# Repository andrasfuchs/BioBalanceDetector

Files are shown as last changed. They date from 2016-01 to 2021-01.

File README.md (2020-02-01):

<p align="center">
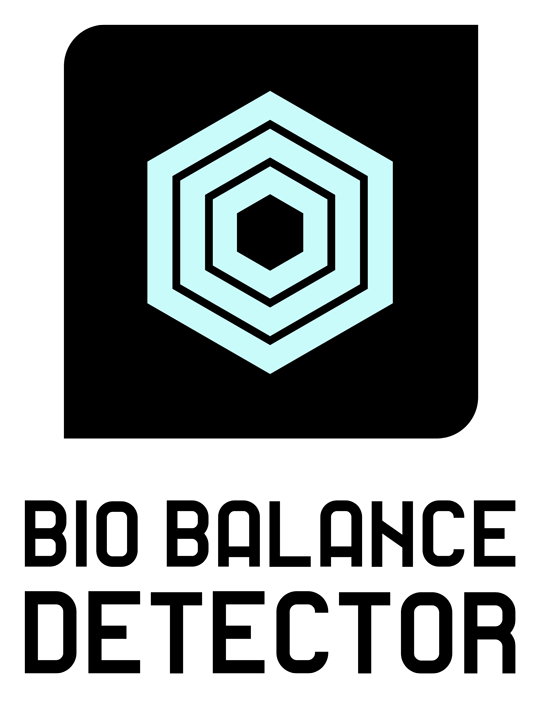
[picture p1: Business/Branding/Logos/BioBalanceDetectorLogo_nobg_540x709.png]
  
</p>

Technically speaking Bio Balance Detector is a software and hardware combination (a data acquisition system - DAS) to detect, measure, display and analyze the electromagnetic energy field around living beings and indicate any potential health imbalance.  
  
These very weak, but measurable electromagnetic fields are the same what our doctors use while using an EEG (electroencephalogram) and ECG (electrocardiogram) devices. We use the information gathered there mainly to detect if we are sleeping, awake or alert, or if there is any problem with our heart's. My goal is to extend this phenomenon's measurements to our hands, or even our whole body.  
  
Technically I will need to connect an electromagnetic sensor matrix which is connected to a PC where the rendering would take place. It will look similar to a Wacom tablet, just like this:
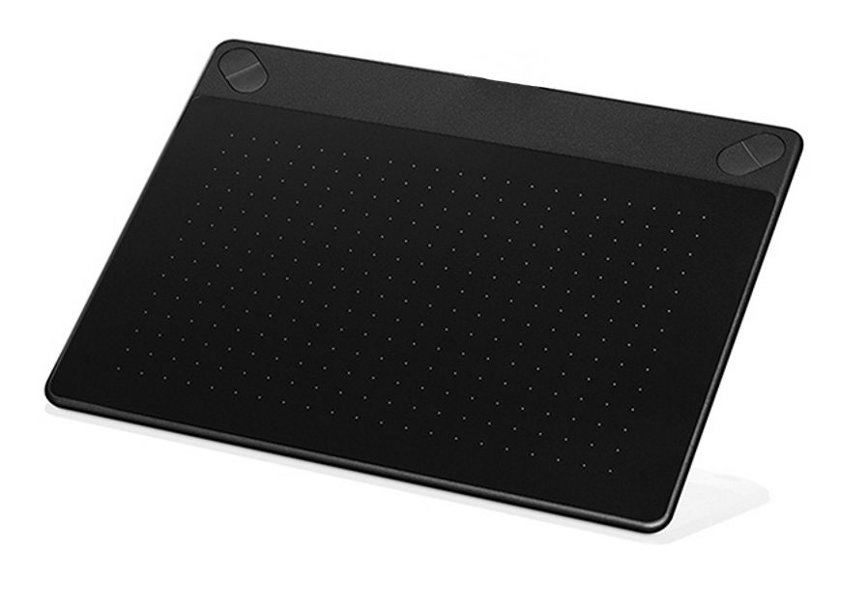
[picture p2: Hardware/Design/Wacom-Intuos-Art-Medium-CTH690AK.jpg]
Wacom Tablet
  
  
Right now, with my [Mercury-16 prototype](https://github.com/andrasfuchs/BioBalanceDetector/wiki/Proto-%235---Mercury-16)  I reached a point where I have a working sensor matrix connected to a microcontroller. Every microcontroller is connected to 8 sensors and 1 emitter. The sensors detect electromagnetic fields, the emitters generate those fields. This part (1 microcontroller, 8 sensors, 1 emitter) is called the cell. These cells are daisy-chained and they all are connected to another microcontroller called the organizer. The cells digitize the analog signals (at 1kHz, 12bit) from the sensors (antennas) and forward them to the organizer. The organizer's job is to format the raw data and send it to the PC trough USB. The PC has a driver which further processes the data, and applies the filters if necessary. There are now WAV file writer, VTS file writer, FFT (Fast Fourier Transformation), averager and offsetter filters available. The driver is capable to work with [SciLab](http://www.scilab.org/) and [ParaView](https://www.paraview.org/), and it also has a very basic console application UI.  
  
You can browse the technical challenges I worked and I am working on on the [implementation wiki page](https://github.com/andrasfuchs/BioBalanceDetector/wiki/Implementation). Future plans include, but not limited to: fractal antenna design, analog low-pass Butterworth filters, Goertzel algorithm implementation on the cells, emitters, USB 3.0, Unity3D GUI and many more.  
  
I realize at this point that I need experienced, passionate people to more forward. I'm currently looking for people with the following expertise, so don't hesitate to contact me:  
* Hardware designer: PCB with [KiCad](https://www.kicad-pcb.org/), antenna and analog low pass filter design  
* Microcontroller firmware programmer: Atmel XMEGA programming with AVR C  
* PC driver developer: .NET, C#, signal processing and WebSockets  
* GUI: Unity3D, C# and WebSockets  
  
If you would like to get know the project more, check out the [wiki page](http://bit.ly/29OBsJ2) or contact me at <andras.fuchs@gmail.com>.

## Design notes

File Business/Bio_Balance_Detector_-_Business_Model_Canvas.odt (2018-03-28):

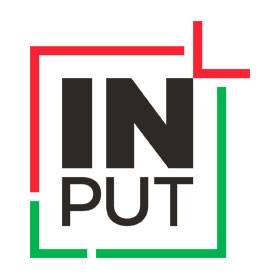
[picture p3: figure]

Business Canvas Model

| 7. Stratégiai partnerek - alkatrész beszállítók - természetgyógyászok - értékesítő ügynökök - szakorvosok | 8. Kulcs-tevékenységek - készülék értékesítése - a diagnózis felállításához szükséges adatok begyűjtése a célszemélytől - elemzés felajánlása szolgáltatásként | 1. Érték ajánlatok - gyors, fájdalommentes, non-invazív, teljes testre vonatkozó elektromágneses diagnosztikai eljárás, amely vizuálisan azonnal értelmezhető adatokat szolgáltat - egészségünkkel kapcsolatos egyensúlyi pontról való elmozdulások megjelenítése | | 4. Fogyasztói kapcsolatok - online - személyes | 2. Fogyasztói csoportok - egészségtudatos személy - természetgyógyász - magánpraxissal rendelkező orvos
| | 6. Erőforrások - hardware tervező - firmware fejlesztő - driver fejlesztő - Unity3D fejlesztő - adatelemző szakember - szkennelő hardware | | | 3. Értékesítési csatornák - online megrendelés - értékesítési ügynök
9. Költség struktúra - prototípus alkatrészek: 1.1 millió Ft - antenna háló tervezése és 3D nyomtatása: 1.5 millió Ft - hardware tervezés: 1.2 millió Ft (240 munkaóra) - software fejlesztés: 4.6 millió Ft (910 munkaóra) - adatok elemzése, diagnosztika: 0.6 millió Ft (120 munkaóra) | | | | 5. Bevételi Források - egyszeri bevétel a készülék eladásából - rendszeres előfizetői díj a folyamatos elemzésért - emelt díjas esetenkénti elemzési díj

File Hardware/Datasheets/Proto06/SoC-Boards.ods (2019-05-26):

 | Raspberry Pi 3 Model B | Raspberry Pi 3 Model B+ | Orange Pi PC Plus | Orange Pi 3 | Orange Pi Win | Pine RockPro64 | Pine Rock64 | Pine H64-B | Odroid C2 | Odroid N2
SoC | Broadcom BCM2837 4 x ARM Cortex-A53 1.2Ghz 64bit ARMv7 Architecture @40nm | Broadcom BCM2837B0 quad-core A53 (ARMv8) 64-bit @ 1.4GHz | Allwinner H3 Quad-core Cortex-A7 H.265/HEVC 4K | Allwinner H6 Quad-core 1.8GHZ 64bit ARM Cortex-A53 | Allwinner A64 quad core ARM Cortex A53 processor @ 1.2 GHz with Mali-400MP2 GPU | Rockchip RK3399 Hexa-Core (dual ARM Cortex A72 and quad ARM Cortex A53) 64-Bit Processor with MALI T-860 Quad-Core GPU | Rockchip RK3328 Quad-Core ARM Cortex A53 64-Bit | Quad-core ARM Cortex-A53 Processor@1488Mhz | Amlogic ARM® Cortex®-A53(ARMv8) 1.5Ghz quad core CPUs
RAM | 1GB 32bit LPDDR2 450MHz | 1GB LPDDR2 SDRAM | 1GB DDR3 (shared with GPU) | 1GB LPDDR3 (shared with GPU) | 1 GB DDR3 | 2/4GB LPDDR4 | 1/2/3GB 1600MHz LPDDR3 | 2/3GB LPDDR3. | 2GB 32bit DDR3 912MHz
HDMI | HDMI 1.4 / RCA / DSI |  |  |  |  |  |  |  | HDMI 2.0 4K / 60Hz
WiFi |  | 2.4GHz and 5GHz 802.11b/g/n/ac Wi-Fi |  | AP6256, IEEE 802.11 a/b/g/n/ac | 802.11 b/g/n | WiFi 802.11 b/g/n (extension) | WiFi 802.11 b/g/n (extension) | WiFi 802.11 b/g/n/ac
LAN | 10/100 Mbit/s | 10/100/1000Mbps (via USB channel) | 10/100Mbps | 10/100/1000Mbps | 10/100/1000Mbps | 10/100/1000Mbps | 10/100/1000Mbps | 10/100/1000Mbps | 10/100/1000Mbps
USB | 2.0 | 2.0 | 2.0 | 3.0 | 2.0 | 3.0 | 3.0 | 3.0 | 2.0
Power |  |  |  |  |  | 12V/3A barrel | 5V/3A coaxial
Linux | Raspbian | Raspbian |  |  |  |  |  | Armbian Debian | Ubuntu 16.04 or Android 6.0
Windows IoT | Yes | No |  |  |  | No | No | No | No
Released | 2016 | 2018 |  | 2019 | 2017
Price (USD) | 35 |  | 24 | 30 |  | 60/80 | 25/35/45 | 36/45 | 46 | 63/79
Problems | -faulty USB driver |  |  | -faulty software |  |  | -no wifi | +RaspPi header

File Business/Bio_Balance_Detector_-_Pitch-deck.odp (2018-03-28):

## Bio Balance Detector

- Fuchs András
  Április, 2018
  Hiventures, Budapest

## Jelenlegi csapat

  <number>
  Fuchs András
  Mérnök Informatikus
  Ötletgazda, hardware tervező, firmware és software fejlesztő
  13 éves .NET/C# szoftverfejlesztői tapasztalat
  5 éves hardware tervezői és Atmel-C firmware fejlesztői tapasztalat

## A kihívás

  <number>
- Egészségügyi diagnosztika ma: későn és kevés
  - A rákok 95%-a megelőzhető lenne, ez évente 9 millió emberélet!
- Drasztikus beavatkozások
  - Megelőzhető, ha időben cselekszünk, életmódváltással, gyógyszerek nélkül
- Félrekezelések
  - Azonnal kimutatható, ha a szervezet rosszabb állapotba kerül
- Kevés lehetőség öndiagnózisra
  - Mit tehet az egészségtudatos ember?
  - Quantified Self

## A megoldás

  <number>
- Testünk lenyomatának feldolgozása
- Intuitív hőtérképszerű megjelenítés
- Szakemberek bevonása akár távolról
- Idővel tipikus problémák felismerése Mesterséges Intelligenciával
- A későbbiekben szabadalmaztatható antenna kialakítása

## Hasonló vállalkozások

  <number>
- Hyperspectral Imaging
  - Űrkutatás
  - Nyersanyag-térképészet
  - Élelmiszer minőség ellenőrzés
- Reptéri ellenőrző kapuk
  - Millimeter-wave test szkenner
- Modern röntgen gépek

## Ügyfelek, értékesítés

  <number>
- Egészségtudatos magánszemélyek
  - Kis méretű készülék
  - Távoli diagnosztizálás szolgáltatás
- Természetgyógyászok
  - Kis méretű készülék
  - Helyi vagy távoli diagnózis
- Magánpraxissal rendelkező szakorvosok
  - Egész testes készülék
  - Helyi diagnózis

## Üzleti modell

  <number>
- Jelenleg
  - Prototípus fejlesztés alatt
- Későbbiekben
  - Termék eladások
  - Kapcsolódó szolgáltatás értékesítés
    - Távoli diagnózis közvetítés
    - AI szoftvercsomag
    - Akkreditált képzések

## Hol járunk most?

  <number>
- Ötödik prototípus működőképes
  - 16 csatorna (pixel)
  - Jelfeldolgozás a PC-n
  - Nagyon egyszerű megjelenítés
  - 2D maratott antennák
- Hatodik tervezési fázisban
  - 256 csatorna (pixel) egy 20x20 cm-es panelon
  - Jelfeldolgozás a mikrokontrolleren
  - Grafikus, valós idejű megjelenítés
  - 3D nyomtatott antennák

## Együttműködésünk

  <number>
- Egyelőre nem történt külső tőke bevonás
- Szakmai mentorokkal való kapcsolatfelvétel
  - Cégalapítás
  - Szabadalom-kezelés
  - Nemzetközi piacra való kijutás
  - Marketing, termékpozicionálás
  - Értékesítés
- Anyagi támogatás
  - 3 szakember foglalkoztatása szabadúszóként (MUC, driver és Unity3D)
  - Anyagköltségek (hardware alkatrészek, NYÁK és antenna gyártás)
  - Működési költség

## Kapcsolat

  <number>
- Kapcsolattartó: Fuchs András
- Email: andras.fuchs@gmail.com
- Telefon: +36 (70) 453-9624
- Weboldal: www.biobalancedetector.com

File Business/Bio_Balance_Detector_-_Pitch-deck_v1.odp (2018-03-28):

## Bio Balance Detector

- Fuchs András
  Április, 2018
  Hiventures, Budapest

## Jelenlegi csapat

  <number>
  Fuchs András
  Mérnök Informatikus
  Ötletgazda, hardware tervező, firmware és software fejlesztő
  13 éves .NET/C# szoftverfejlesztői tapasztalat
  5 éves hardware tervezői és Atmel-C firmware fejlesztői tapasztalat

## A kihívás

  <number>
- Egészségügyi diagnosztika ma: későn és kevés
  - A rákok 95%-a megelőzhető lenne, ez évente 9 millió emberélet!
- Drasztikus beavatkozások
  - Ha időben cselekszünk, életmódváltással, gyógyszerek nélkül
- Félrekezelések
  - Azonnal kimutatható, ha a szervezet rosszabb állapotba kerül
- Kevés lehetőség öndiagnózisra
  - Mit tehet az egészségtudatos ember?
  - Quantified Self: önmegfigyelés, optimalizálás

## A megoldás

  <number>
- Testünk lenyomatának feldolgozása
  - Minden szervünk folyamatosan ad magáról információt
- Intuitív hőtérképszerű megjelenítés
- Szakemberek bevonása akár távolról, otthonról
- Idővel tipikus problémák felismerése Mesterséges Intelligenciával
- A későbbiekben szabadalmaztatható antenna kialakítás

## Versenytársak

  <number>
- Hyperspectral Imaging
  - Űrkutatás
  - Nyersanyag-térképészet
  - Élelmiszer minőség ellenőrzés
- Reptéri ellenőrző kapuk
  - Millimeter-wave test szkenner
- Modern röntgen gépek
  - Káros sugárzással való bombázás
  - CCD érzékelő panel a detektálási oldalon (FPD)

## Ügyfelek, értékesítés

  <number>
- Egészségtudatos magánszemélyek
  - Kis méretű készülék
  - Távoli diagnosztizálás szolgáltatás
- Természetgyógyászok
  - Kis méretű készülék
  - Helyi vagy távoli diagnózis
- Magánpraxissal rendelkező szakorvosok
  - Egész testes készülék
  - Helyi diagnózis

## Üzleti modell

  <number>
- Jelenleg
  - Prototípus fejlesztési stádiumban
- Később
  - Hardware eladások
  - Kapcsolódó szolgáltatás értékesítés
    - távoli diagnózis közvetítés
    - AI szoftvercsomag
    - Akkreditált képzések

## Hol járunk most?

  <number>
- Ötödik prototípus működőképes:
  - 16 csatorna (pixel)
  - Jelfeldolgozás a PC-n
  - Nagyon egyszerű megjelenítés
  - 2D maratott antennák
- Hatodik tervezési fázisban:
  - 256 csatorna (pixel) egy 20x20 cm-eres panelon
  - Jelfeldolgozás a mikrokontrolleren
  - Grafikus, valós idejű megjelenítés
  - 3D nyomtatott antennák

## Zárás

  <number>
- Egyelőre nem történt külső tőke bevonás
- Elsősorban szaktudást, segítségnyújtást szeretnék
  - Cégalapítás, cégirányítás
  - Szabadalom-kezelés
  - Nemzetközi piacra való kijutás
  - Marketing, termékpozicionálás
  - Értékesítés
- Másodlagosan 9 millió forintot a fejlesztésekre
  - 3 szakember foglalkoztatása szabadúszóként (MUC, driver és Unity3D)
  - Anyagköltségek (hardware alkatrészek, NYÁK és antenna gyártás)
  - Minimális működési költség (VPS szerverbérlés, iroda nem szükséges)

## Kapcsolat

  <number>
- Nevem: Fuchs András
- Email: andras.fuchs@gmail.com
- Telefon: +36 (70) 453-9624
- Weboldal: www.biobalancedetector.com

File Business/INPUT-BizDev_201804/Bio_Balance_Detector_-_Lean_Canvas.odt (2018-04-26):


Lean Canvas

| Probléma - a természetgyógyászok elavult készülékekkel tudnak csak pontatlan diagnózist felállítani régi bio-rezonanciás gépekkel KPI: Megkérdezettek, válaszolók, akik rendelkeznek ezzel a problémával és/vagy tisztában vannak, ezzel a szükséglettel | Megoldás - egy olyan készülék és hozzá tartozó szolgáltatás, ami képes a test egészére jellemző és lokális egészséges állapottól való eltéréseket észlelni KPI: Válaszadók, akik kipróbálják az MVP-t, engagement, lemorzsolódás, legtöbbet/legkevesebbet használd feature, emberek akik hajlandóak fizetni | Egyedi értékajánlatok - gyors, fájdalommentes, non-invazív, teljes testre vonatkozó elektromágneses diagnosztikai eljárás, amely vizuálisan azonnal értelmezhető adatokat szolgáltat - egészségünkkel kapcsolatos egyensúlyi pontról való elmozdulások megjelenítése - hozzáférés egy folyamatosan frissülő probléma-felismerő szolgáltatáshoz KPI: Visszajelzések, független értékelések, fogyasztói kommentek, leírások a termékről, felmérések, versenytárs elemzés | | Unfair előny - magas technológiai ismeret szükséges a kifejlesztéshez - szabadalmazható érzékelő egység - jelenleg nincs közvetlen versenytárs KPI: Az egyedi értékajánlat értelmezése a fogyasztók által, patentek, márka érték, belépési korlátok, új belépők száma, a kapcsolatok exkluzivitása | Fogyasztói szegmensek - természetgyógyászok KPI: mennyire könnyű/olcsó potenciális vásárlókat találni
| | Key Metrics | | | Csatornák - online megrendelés - értékesítési ügynök KPI: Leadek, csatornákon elérhető fogyasztók, vírusos koefficiens és ciklus, net promoter score, megnyitási ráta, affiliate marginok, átkattintási ráta, PageRank, üzenetek eléri mérete
Költség struktúra - prototípus alkatrészek: 1.1 millió Ft - antenna háló tervezése és 3D nyomtatása: 1.5 millió Ft - hardware tervezés: 1.2 millió Ft (240 munkaóra) - software fejlesztés: 4.6 millió Ft (910 munkaóra) - adatok elemzése, diagnosztika: 0.6 millió Ft (120 munkaóra) KPI: Fix költségek, egy felhasználó megszerzésének költsége, az n-eik fogyasztó kiszolgálásának költsége, támogatási költség, kulcsszó költség | | | | Bevételi Források - egyszeri bevétel a készülék eladásából - rendszeres előfizetői díj a folyamatos elemzésért - emelt díjas esetenkénti elemzési díj - emelt díjas elemzési díj ritka betegségekre KPI: Lifetime Customer Value, átlagos bevétel felhasználóként, konverziós ráta, kosár méret, átkattintási ráta

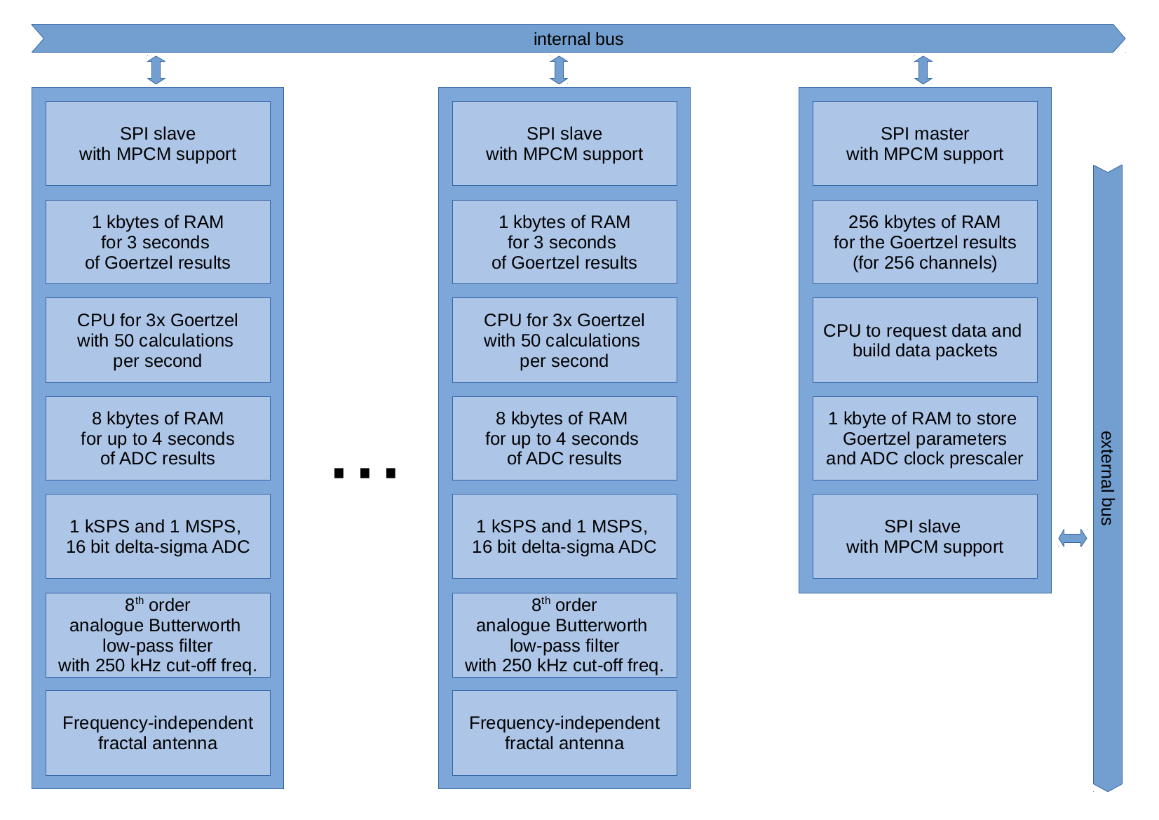
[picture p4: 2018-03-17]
Hardware/Design/BBD-Proto6-Functional_Diagram_v3.png

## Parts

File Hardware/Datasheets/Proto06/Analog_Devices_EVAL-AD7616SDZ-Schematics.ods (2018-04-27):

Bill Of Materials for EVAL-AD7616SDZ Rev-D (20 May-2016 ) (05-039639-01-d-1.xlsx)
Name | Part Description | VALUE | TOLERANCE | PCB Decal | SMD | Layer Name | PART DESC | MFG #1 | PART NUMBER | STOCK CODE
C1 | CAP | DNI | TBA | C0603 | Yes | Top | 0603 Ceramic Capacitor Location - Not Populated | Epcos | TBA | Do Not Insert
C2 | CAP | DNI | TBA | C0603 | Yes | Top | 0603 Ceramic Capacitor Location - Not Populated | Epcos | TBA | Do Not Insert
C3 | CAP | DNI | TBA | C0603 | Yes | Top | 0603 Ceramic Capacitor Location - Not Populated | Epcos | TBA | Do Not Insert
C4 | CAP | DNI | TBA | C0603 | Yes | Top | 0603 Ceramic Capacitor Location - Not Populated | Epcos | TBA | Do Not Insert
C5 | CAP | DNI | TBA | C0603 | Yes | Top | 0603 Ceramic Capacitor Location - Not Populated | Epcos | TBA | Do Not Insert
C6 | CAP | DNI | TBA | C0603 | Yes | Top | 0603 Ceramic Capacitor Location - Not Populated | Epcos | TBA | Do Not Insert
C7 | CAP | DNI | TBA | C0603 | Yes | Top | 0603 Ceramic Capacitor Location - Not Populated | Epcos | TBA | Do Not Insert
C8 | CAP | DNI | TBA | C0603 | Yes | Top | 0603 Ceramic Capacitor Location - Not Populated | Epcos | TBA | Do Not Insert
C9 | CAP | DNI | TBA | C0603 | Yes | Top | 0603 Ceramic Capacitor Location - Not Populated | Epcos | TBA | Do Not Insert
C10 | CAP | DNI | TBA | C0603 | Yes | Top | 0603 Ceramic Capacitor Location - Not Populated | Epcos | TBA | Do Not Insert
C11 | CAP | DNI | TBA | C0603 | Yes | Top | 0603 Ceramic Capacitor Location - Not Populated | Epcos | TBA | Do Not Insert
C12 | CAP | DNI | TBA | C0603 | Yes | Top | 0603 Ceramic Capacitor Location - Not Populated | Epcos | TBA | Do Not Insert
C13 | CAP | DNI | TBA | C0603 | Yes | Top | 0603 Ceramic Capacitor Location - Not Populated | Epcos | TBA | Do Not Insert
C14 | CAP | DNI | TBA | C0603 | Yes | Top | 0603 Ceramic Capacitor Location - Not Populated | Epcos | TBA | Do Not Insert
C15 | CAP | DNI | TBA | C0603 | Yes | Top | 0603 Ceramic Capacitor Location - Not Populated | Epcos | TBA | Do Not Insert
C16 | CAP | DNI | TBA | C0603 | Yes | Top | 0603 Ceramic Capacitor Location - Not Populated | Epcos | TBA | Do Not Insert
C17 | CAP | 0.1uF | ±10% | C0402 | Yes | Bottom | Capacitor ceramic, 16V, X7R, 0402 | Multicomp | MC0402B104K160CT | FEC 1758896
C18 | CAP | 10uF | ±20% | C0603 | Yes | Bottom | 6.3V X5R Ceramic Capacitor | Murata | GRM188R60J106ME47D | FEC 1735528RL
C19 | CAP | 0.1uF | ±10% | C0402 | Yes | Top | Capacitor ceramic, 16V, X7R, 0402 | Multicomp | MC0402B104K160CT | FEC 1758896
C20 | CAP | 10uF | ±20% | C0603 | Yes | Bottom | 6.3V X5R Ceramic Capacitor | Murata | GRM188R60J106ME47D | FEC 1735528RL
C21 | CAP | 0.1uF | ±10% | C0402 | Yes | Top | Capacitor ceramic, 16V, X7R, 0402 | Multicomp | MC0402B104K160CT | FEC 1758896
C22 | CAP | 10uF | ±20% | C0603 | Yes | Bottom | 6.3V X5R Ceramic Capacitor | Murata | GRM188R60J106ME47D | FEC 1735528RL
C23 | CAP | 0.1uF | ±10% | C0402 | Yes | Top | Capacitor ceramic, 16V, X7R, 0402 | Multicomp | MC0402B104K160CT | FEC 1758896
C24 | CAP | 10uF | ±20% | C0603 | Yes | Bottom | 6.3V X5R Ceramic Capacitor | Murata | GRM188R60J106ME47D | FEC 1735528RL
C25 | CAP | 0.1uF | ±10% | C0402 | Yes | Top | Capacitor ceramic, 16V, X7R, 0402 | Multicomp | MC0402B104K160CT | FEC 1758896
C26 | CAP | 10uF | ±20% | C0603 | Yes | Bottom | 6.3V X5R Ceramic Capacitor | Murata | GRM188R60J106ME47D | FEC 1735528RL
C27 | CAP | 0.1uF | ±10% | C0402 | Yes | Top | Capacitor ceramic, 16V, X7R, 0402 | Multicomp | MC0402B104K160CT | FEC 1758896
C28 | CAP | 10uF | ±10% | C0805 | Yes | Bottom | 10V X5R Ceramic Capacitor | Phycomp | 2222 2401 3676 | FEC 9402136
C29 | CAP | 0.1uF | ±10% | C0805 | Yes | Top | 50V X7R Ceramic Capacitor 0805 | Multicomp | MCU0805R104KCT | FEC 9406387
C30 | CAP | 10uF | ±20% | C0603 | Yes | Bottom | 6.3V X5R Ceramic Capacitor | Murata | GRM188R60J106ME47D | FEC 1735528RL
C31 | CAP | 0.1uF | ±10% | C0402 | Yes | Top | Capacitor ceramic, 16V, X7R, 0402 | Multicomp | MC0402B104K160CT | FEC 1758896
C32 | CAP | 10uF | ±20% | C0603 | Yes | Bottom | 6.3V X5R Ceramic Capacitor | Murata | GRM188R60J106ME47D | FEC 1735528RL
C33 | CAP | 0.1uF | ±10% | C0402 | Yes | Top | Capacitor ceramic, 16V, X7R, 0402 | Multicomp | MC0402B104K160CT | FEC 1758896
C34 | CAP | 10uF | ±20% | C0603 | Yes | Top | 6.3V X5R Ceramic Capacitor | Murata | GRM188R60J106ME47D | FEC 1735528RL
C35 | CAP | 0.1uF | ±10% | C0402 | Yes | Top | Capacitor ceramic, 16V, X7R, 0402 | Multicomp | MC0402B104K160CT | FEC 1758896
C36 | CAP | 1uF | ±10% | C0805 | Yes | Top | 10V X7R Ceramic Capacitor | Phycomp | CC0805KKX7R6BB105 | FEC 3352067
C43 | CAP | 2.2uF | ±10% | C0603 | Yes | Top | CAP, MLCC, X5R, 2.2UF, 10V, 0603 | MultiComp | MC0603X225K100CT | FEC 232-0817
C44 | CAP | DNI | n/a | C0402 | Yes | Top | Ceramic Capacitor, not inserted, 0402 | n/a | n/a | Do Not Insert
C45 | CAP | 2.2uF | ±10% | C0603 | Yes | Top | CAP, MLCC, X5R, 2.2UF, 10V, 0603 | MultiComp | MC0603X225K100CT | FEC 232-0817
C46 | CAP | 10uF | ±20% | C0603 | Yes | Top | 6.3V X5R Ceramic Capacitor | Murata | GRM188R60J106ME47D | FEC 1735528RL
C47 | CAP | 2.2uF | ±10% | C0603 | Yes | Top | CAP, MLCC, X5R, 2.2UF, 10V, 0603 | MultiComp | MC0603X225K100CT | FEC 232-0817
C48 | CAP | DNI | n/a | C0402 | Yes | Top | Ceramic Capacitor, not inserted, 0402 | n/a | n/a | Do Not Insert
C49 | CAP | 2.2uF | ±10% | C0603 | Yes | Top | CAP, MLCC, X5R, 2.2UF, 10V, 0603 | MultiComp | MC0603X225K100CT | FEC 232-0817
C50 | CAP | 10uF | ±20% | C0603 | Yes | Top | 6.3V X5R Ceramic Capacitor | Murata | GRM188R60J106ME47D | FEC 1735528RL
C51 | CAP | 1uF | ±10% | C0402 | Yes | Top | CAPACITOR, 0603, 1UF, 16V | Multicomp | MC0603B105K160CT | FEC 2320814
C52 | CAP | 1uF | ±10% | C0402 | Yes | Top | CAPACITOR, 0603, 1UF, 16V | Multicomp | MC0603B105K160CT | FEC 2320814
C54 | CAP | 0.1uF | ±10% | C0402 | Yes | Top | Capacitor ceramic, 16V, X7R, 0402 | Multicomp | MC0402B104K160CT | FEC 1758896
FID1 | FIDUCIAL-ECO |  |  | FIDUCIAL | Yes | Top
FID2 | FIDUCIAL-ECO |  |  | FIDUCIAL | Yes | Top
FID3 | FIDUCIAL-ECO |  |  | FIDUCIAL | Yes | Top
GND | TESTPOINT |  |  | TESTPOINT | No | Top | Black Testpoint | Vero | 20-2137 | FEC 8731128
GND1 | TESTPOINT |  |  | TESTPOINT | No | Top | Black Testpoint | Vero | 20-2137 | FEC 8731128
GND2 | TESTPOINT |  |  | TESTPOINT | No | Top | Black Testpoint | Vero | 20-2137 | FEC 8731128
GND3 | TESTPOINT |  |  | TESTPOINT | No | Top | Black Testpoint | Vero | 20-2137 | FEC 8731128
J1 | POWER_SKT_3.81MM_8WAY |  |  | POWER_SKT_3.81MM_8WAY | No | Top | 8-Pin Terminal header, pitch 3.81mm, vertical | Phoenix Contact | MC 1,5/ 8-G-3,81 | FEC 3704774
J1A | SREWTERM-8_RA | DNI |  | CON\POWER8(3_81PITCH) | No | Top | 8-Pin Screw Terminal, pitch 3.81mm, vertical | Phoenix Contact | 1727078 | Do Not Insert. Keep clear of solder.
J2 | POWER_SKT_3.81MM_8WAY |  |  | POWER_SKT_3.81MM_8WAY | No | Top | 8-Pin Terminal header, pitch 3.81mm, vertical | Phoenix Contact | MC 1,5/ 8-G-3,81 | FEC 3704774
J2A | SREWTERM-8_RA | DNI |  | CON\POWER8(3_81PITCH) | No | Top | 8-Pin Screw Terminal, pitch 3.81mm, vertical | Phoenix Contact | 1727078 | Do Not Insert. Keep clear of solder.
J3 | POWER_SKT_3.81MM_8WAY |  |  | POWER_SKT_3.81MM_8WAY | No | Top | 8-Pin Terminal header, pitch 3.81mm, vertical | Phoenix Contact | MC 1,5/ 8-G-3,81 | FEC 3704774
J3A | SREWTERM-8_RA | DNI |  | CON\POWER8(3_81PITCH) | No | Top | 8-Pin Screw Terminal, pitch 3.81mm, vertical | Phoenix Contact | 1727078 | Do Not Insert. Keep clear of solder.
J4 | POWER_SKT_3.81MM_8WAY |  |  | POWER_SKT_3.81MM_8WAY | No | Top | 8-Pin Terminal header, pitch 3.81mm, vertical | Phoenix Contact | MC 1,5/ 8-G-3,81 | FEC 3704774
J4A | SREWTERM-8_RA | DNI |  | CON\POWER8(3_81PITCH) | No | Top | 8-Pin Screw Terminal, pitch 3.81mm, vertical | Phoenix Contact | 1727078 | Do Not Insert. Keep clear of solder.
J5 | HEADER26 |  |  | HEADER26 | No | Top | 26-Pin (2 x 13) 0.1" Pitch Straight Header | Harwin | M20-9983646 | FEC 1022244 (36 Pin Strip, Cut to Length)
J6 | SMA |  |  | SMA | No | Top | 50r SMA Jack Vertical | TE Connectivity | 5-1814832-1 | FEC 1248990
J7 | CON\BARREL_SMD_2MM_KLDX-SMT2-0202-A |  |  | CON\BARREL_SMD_2MM_KLDX-SMT2-0202-A | No | Top | DC Power Connectors 2mm SMT POWER JACK | KYCON | KLDX-SMT2-0202-A | MOUSER 806-KLDX-SMT20202A
J8 | CON\POWER |  |  | CON\POWER | No | Top | 2 Pin Terminal Block (5mm Pitch) | Camden | CTB5000/2 | FEC 151785
J9 | CON\POWER |  |  | CON\POWER | No | Top | 2 Pin Terminal Block (5mm Pitch) | Camden | CTB5000/2 | FEC 151785
J10 | SDP-STANDARD-CONN |  |  | CON-120/FX8-120S-SV_W/S | No | Top | 120-way connector, 0.6mm pitch | Hirose | FX8-120S-SV(21) | FEC 1324660
LED1 | LED-0603-GREEN | GREEN |  | LED-0603 | Yes | Top | LED, SMD Green | OSRAM | LGQ971 | Digikey 475-1409-1-ND
LK1 | JUMPER |  |  | SIP-2P | No | Top | 2 Pin (0.1" Pitch) Header & Shorting Shunt | Harwin | M20-9990246 | FEC 1022247 & 150-411
LK2 | JUMPER |  |  | SIP-2P | No | Top | 2 Pin (0.1" Pitch) Header & Shorting Shunt | Harwin | M20-9990246 | FEC 1022247 & 150-411
LK3 | JUMPER |  |  | SIP-2P | No | Top | 2 Pin (0.1" Pitch) Header & Shorting Shunt | Harwin | M20-9990246 | FEC 1022247 & 150-411
LK4 | JUMPER |  |  | SIP-2P | No | Top | 2 Pin (0.1" Pitch) Header & Shorting Shunt | Harwin | M20-9990246 | FEC 1022247 & 150-411
LK5 | JUMPER |  |  | SIP-2P | No | Top | 2 Pin (0.1" Pitch) Header & Shorting Shunt | Harwin | M20-9990246 | FEC 1022247 & 150-411
LK6 | JUMPER |  |  | SIP-2P | No | Top | 2 Pin (0.1" Pitch) Header & Shorting Shunt | Harwin | M20-9990246 | FEC 1022247 & 150-411
LK7 | JUMPER |  |  | SIP-2P | No | Top | 2 Pin (0.1" Pitch) Header & Shorting Shunt | Harwin | M20-9990246 | FEC 1022247 & 150-411
LK8 | JUMPER |  |  | SIP-2P | No | Top | 2 Pin (0.1" Pitch) Header & Shorting Shunt | Harwin | M20-9990246 | FEC 1022247 & 150-411
LK9 | JUMPER |  |  | SIP-2P | No | Top | 2 Pin (0.1" Pitch) Header & Shorting Shunt | Harwin | M20-9990246 | FEC 1022247 & 150-411
LK10 | JUMPER |  |  | SIP-2P | No | Top | 2 Pin (0.1" Pitch) Header & Shorting Shunt | Harwin | M20-9990246 | FEC 1022247 & 150-411
LK11 | JUMPER |  |  | SIP-2P | No | Top | 2 Pin (0.1" Pitch) Header & Shorting Shunt | Harwin | M20-9990246 | FEC 1022247 & 150-411
LK12 | JUMPER |  |  | SIP-2P | No | Top | 2 Pin (0.1" Pitch) Header & Shorting Shunt | Harwin | M20-9990246 | FEC 1022247 & 150-411
LK13 | JUMPER |  |  | SIP-2P | No | Top | 2 Pin (0.1" Pitch) Header & Shorting Shunt | Harwin | M20-9990246 | FEC 1022247 & 150-411
LK14 | JUMPER |  |  | SIP-2P | No | Top | 2 Pin (0.1" Pitch) Header & Shorting Shunt | Harwin | M20-9990246 | FEC 1022247 & 150-411
LK15 | JUMPER |  |  | SIP-2P | No | Top | 2 Pin (0.1" Pitch) Header & Shorting Shunt | Harwin | M20-9990246 | FEC 1022247 & 150-411
LK16 | JUMPER |  |  | SIP-2P | No | Top | 2 Pin (0.1" Pitch) Header & Shorting Shunt | Harwin | M20-9990246 | FEC 1022247 & 150-411
LK17 | JUMPER |  |  | SIP-2P | No | Top | 2 Pin (0.1" Pitch) Header & Shorting Shunt | Harwin | M20-9990246 | FEC 1022247 & 150-411
LK18 | JUMPER |  |  | SIP-2P | No | Top | 2 Pin (0.1" Pitch) Header & Shorting Shunt | Harwin | M20-9990246 | FEC 1022247 & 150-411
LK19 | JUMPER |  |  | SIP-2P | No | Top | 2 Pin (0.1" Pitch) Header & Shorting Shunt | Harwin | M20-9990246 | FEC 1022247 & 150-411
LK20 | JUMPER |  |  | SIP-2P | No | Top | 2 Pin (0.1" Pitch) Header & Shorting Shunt | Harwin | M20-9990246 | FEC 1022247 & 150-411
LK21 | JUMPER |  |  | SIP-2P | No | Top | 2 Pin (0.1" Pitch) Header & Shorting Shunt | Harwin | M20-9990246 | FEC 1022247 & 150-411
LK22 | JUMPER |  |  | SIP-2P | No | Top | 2 Pin (0.1" Pitch) Header & Shorting Shunt | Harwin | M20-9990246 | FEC 1022247 & 150-411
LK23 | JUMPER |  |  | SIP-2P | No | Top | 2 Pin (0.1" Pitch) Header & Shorting Shunt | Harwin | M20-9990246 | FEC 1022247 & 150-411
LK24 | JUMPER |  |  | SIP-2P | No | Top | 2 Pin (0.1" Pitch) Header & Shorting Shunt | Harwin | M20-9990246 | FEC 1022247 & 150-411
LK25 | JUMPER |  |  | SIP-2P | No | Top | 2 Pin (0.1" Pitch) Header & Shorting Shunt | Harwin | M20-9990246 | FEC 1022247 & 150-411
LK26 | JUMPER |  |  | SIP-2P | No | Top | 2 Pin (0.1" Pitch) Header & Shorting Shunt | Harwin | M20-9990246 | FEC 1022247 & 150-411
LK27 | JUMPER |  |  | SIP-2P | No | Top | 2 Pin (0.1" Pitch) Header & Shorting Shunt | Harwin | M20-9990246 | FEC 1022247 & 150-411
LK28 | JUMPER |  |  | SIP-2P | No | Top | 2 Pin (0.1" Pitch) Header & Shorting Shunt | Harwin | M20-9990246 | FEC 1022247 & 150-411
LK29 | JUMPER |  |  | SIP-2P | No | Top | 2 Pin (0.1" Pitch) Header & Shorting Shunt | Harwin | M20-9990246 | FEC 1022247 & 150-411
LK30 | JUMPER |  |  | SIP-2P | No | Top | 2 Pin (0.1" Pitch) Header & Shorting Shunt | Harwin | M20-9990246 | FEC 1022247 & 150-411
LK31 | JUMPER |  |  | SIP-2P | No | Top | 2 Pin (0.1" Pitch) Header & Shorting Shunt | Harwin | M20-9990246 | FEC 1022247 & 150-411
LK32 | JUMPER |  |  | SIP-2P | No | Top | 2 Pin (0.1" Pitch) Header & Shorting Shunt | Harwin | M20-9990246 | FEC 1022247 & 150-411
LK33 | JUMPER-3 |  |  | JUMPER_3 | No | Top | 6 Pin (3x2) 0.1" Header & Shorting Block - Insert Shorting Block in Position-B | M20-9983646 | M20-9983646 | FEC 1022244 & 150-411 (36 Pin Strip, Cut to Lenght)
LK34 | JUMPER-3 |  |  | JUMPER_3 | No | Top | 6 Pin (3x2) 0.1" Header & Shorting Block - Insert Shorting Block in Position-B | M20-9983646 | M20-9983646 | FEC 1022244 & 150-411 (36 Pin Strip, Cut to Lenght)
LK35 | JUMPER-3 |  |  | JUMPER_3 | No | Top | 6 Pin (3x2) 0.1" Header & Shorting Block - Insert Shorting Block in Position-B | M20-9983646 | M20-9983646 | FEC 1022244 & 150-411 (36 Pin Strip, Cut to Lenght)
LK36 | JUMPER-3 |  |  | JUMPER_3 | No | Top | 6 Pin (3x2) 0.1" Header & Shorting Block - Insert Shorting Block in Position-B | M20-9983646 | M20-9983646 | FEC 1022244 & 150-411 (36 Pin Strip, Cut to Lenght)
LK37 | JUMPER-3 |  |  | JUMPER_3 | No | Top | 6 Pin (3x2) 0.1" Header & Shorting Block - Insert Shorting Block in Position-B | M20-9983646 | M20-9983646 | FEC 1022244 & 150-411 (36 Pin Strip, Cut to Lenght)
LK38 | JUMPER2\SIP3 |  |  | LINK-3P | No | Top | 3 Pin SIL Header & Shorting Link - Insert Shorting Block in Position-A | Harwin | M20-9990345 & M7567-05 | FEC 1022248 & 150410
LK39 | JUMPER |  |  | SIP-2P | No | Top | 2 Pin (0.1" Pitch) Header & Shorting Shunt | Harwin | M20-9990246 | FEC 1022247 & 150-411
LK40 | JUMPER2\SIP3 |  |  | LINK-3P | No | Top | 3 Pin SIL Header & Shorting Link - Insert Shorting Block in Position-A | Harwin | M20-9990345 & M7567-05 | FEC 1022248 & 150410
LK41 | JUMPER2\SIP3 |  |  | LINK-3P | No | Top | 3 Pin SIL Header & Shorting Link - Insert Shorting Block in Position-A | Harwin | M20-9990345 & M7567-05 | FEC 1022248 & 150410
Q2 | 2N7002 |  |  | SOT23 | Yes | Top | MOSFET N Transistor | STMICROELECTRONICS | 2N7002 | FEC 9512608
R1 | RES | 0r | ±1% | R0603 | Yes | Top | SMD Resistor | Multicomp | MC 0.063W 0603 0r | FEC 933-1662
R2 | RES | 0r | ±1% | R0603 | Yes | Top | SMD Resistor | Multicomp | MC 0.063W 0603 0r | FEC 933-1662
R3 | RES | 270r | 0,05 | R0603 | Yes | Top | SMD Resistor | Multicomp | MC 0.063W 0603 5% 270R | FEC 9331964
R4 | RES | 0r | ±1% | R0603 | Yes | Top | SMD Resistor | Multicomp | MC 0.063W 0603 0r | FEC 933-1662
R5 | RES | 0r | ±1% | R0603 | Yes | Top | SMD Resistor | Multicomp | MC 0.063W 0603 0r | FEC 933-1662
R6 | RES | 270r | 0,05 | R0603 | Yes | Top | SMD Resistor | Multicomp | MC 0.063W 0603 5% 270R | FEC 9331964
R7 | RES | 0r | ±1% | R0603 | Yes | Top | SMD Resistor | Multicomp | MC 0.063W 0603 0r | FEC 933-1662
R8 | RES | 0r | ±1% | R0603 | Yes | Top | SMD Resistor | Multicomp | MC 0.063W 0603 0r | FEC 933-1662
R9 | RES | 270r | 0,05 | R0603 | Yes | Top | SMD Resistor | Multicomp | MC 0.063W 0603 5% 270R | FEC 9331964
R10 | RES | 0r | ±1% | R0603 | Yes | Top | SMD Resistor | Multicomp | MC 0.063W 0603 0r | FEC 933-1662
R11 | RES | 0r | ±1% | R0603 | Yes | Top | SMD Resistor | Multicomp | MC 0.063W 0603 0r | FEC 933-1662
R12 | RES | 270r | 0,05 | R0603 | Yes | Top | SMD Resistor | Multicomp | MC 0.063W 0603 5% 270R | FEC 9331964
R13 | RES | 0r | ±1% | R0603 | Yes | Top | SMD Resistor | Multicomp | MC 0.063W 0603 0r | FEC 933-1662
R14 | RES | 0r | ±1% | R0603 | Yes | Top | SMD Resistor | MULTICOMP | MC 0.063W 0603 0r | FEC 933-1662
R15 | RES | 270r | 0,05 | R0603 | Yes | Top | SMD Resistor | Multicomp | MC 0.063W 0603 5% 270R | FEC 9331964
R16 | RES | 0r | ±1% | R0603 | Yes | Top | SMD Resistor | MULTICOMP | MC 0.063W 0603 0r | FEC 933-1662
R17 | RES | 0r | ±1% | R0603 | Yes | Top | SMD Resistor | Multicomp | MC 0.063W 0603 0r | FEC 933-1662
R18 | RES | 270r | 0,05 | R0603 | Yes | Top | SMD Resistor | Multicomp | MC 0.063W 0603 5% 270R | FEC 9331964
R19 | RES | 0R | ±1% | R0603 | Yes | Top | SMD Resistor | Multicomp | MC 0.063W 0603 0r | FEC 933-1662
R20 | RES | 0R | ±1% | R0603 | Yes | Top | SMD Resistor | Multicomp | MC 0.063W 0603 0r | FEC 933-1662
R21 | RES | 270r | 0,05 | R0603 | Yes | Top | SMD Resistor | Multicomp | MC 0.063W 0603 5% 270R | FEC 9331964
R22 | RES | 0R | ±1% | R0603 | Yes | Top | SMD Resistor | Multicomp | MC 0.063W 0603 0r | FEC 933-1662
R23 | RES | 0r | ±1% | R0603 | Yes | Top | SMD Resistor | MULTICOMP | MC 0.063W 0603 0r | FEC 933-1662
R24 | RES | 270r | 0,05 | R0603 | Yes | Top | SMD Resistor | Multicomp | MC 0.063W 0603 5% 270R | FEC 9331964
R25 | RES | 0r | ±1% | R0603 | Yes | Top | SMD Resistor | MULTICOMP | MC 0.063W 0603 0r | FEC 933-1662
R26 | RES | 0r | ±1% | R0603 | Yes | Top | SMD Resistor | Multicomp | MC 0.063W 0603 0r | FEC 933-1662
R27 | RES | 270r | 0,05 | R0603 | Yes | Top | SMD Resistor | Multicomp | MC 0.063W 0603 5% 270R | FEC 9331964
R28 | RES | 0r | ±1% | R0603 | Yes | Top | SMD Resistor | Multicomp | MC 0.063W 0603 0r | FEC 933-1662
R29 | RES | 0r | ±1% | R0603 | Yes | Top | SMD Resistor | Multicomp | MC 0.063W 0603 0r | FEC 933-1662
R30 | RES | 270r | 0,05 | R0603 | Yes | Top | SMD Resistor | Multicomp | MC 0.063W 0603 5% 270R | FEC 9331964
R31 | RES | 0r | ±1% | R0603 | Yes | Top | SMD Resistor | Multicomp | MC 0.063W 0603 0r | FEC 933-1662
R32 | RES | 0r | ±1% | R0603 | Yes | Top | SMD Resistor | Multicomp | MC 0.063W 0603 0r | FEC 933-1662
R33 | RES | 270r | 0,05 | R0603 | Yes | Top | SMD Resistor | Multicomp | MC 0.063W 0603 5% 270R | FEC 9331964
R34 | RES | 0r | ±1% | R0603 | Yes | Top | SMD Resistor | Multicomp | MC 0.063W 0603 0r | FEC 933-1662
R35 | RES | 0R | ±1% | R0603 | Yes | Top | SMD Resistor | Multicomp | MC 0.063W 0603 0r | FEC 933-1662
R36 | RES | 270r | 0,05 | R0603 | Yes | Top | SMD Resistor | Multicomp | MC 0.063W 0603 5% 270R | FEC 9331964
R37 | RES | 0R | ±1% | R0603 | Yes | Top | SMD Resistor | Multicomp | MC 0.063W 0603 0r | FEC 933-1662
R38 | RES | 0R | ±1% | R0603 | Yes | Top | SMD Resistor | Multicomp | MC 0.063W 0603 0r | FEC 933-1662
R39 | RES | 270r | 0,05 | R0603 | Yes | Top | SMD Resistor | Multicomp | MC 0.063W 0603 5% 270R | FEC 9331964
R40 | RES | 0R | ±1% | R0603 | Yes | Top | SMD Resistor | Multicomp | MC 0.063W 0603 0r | FEC 933-1662
R41 | RES | 0r | ±1% | R0603 | Yes | Top | SMD Resistor | Multicomp | MC 0.063W 0603 0r | FEC 933-1662
R42 | RES | 270r | 0,05 | R0603 | Yes | Top | SMD Resistor | Multicomp | MC 0.063W 0603 5% 270R | FEC 9331964
R43 | RES | 0r | ±1% | R0603 | Yes | Top | SMD Resistor | Multicomp | MC 0.063W 0603 0r | FEC 933-1662
R44 | RES | 0r | ±1% | R0603 | Yes | Top | SMD Resistor | Multicomp | MC 0.063W 0603 0r | FEC 933-1662
R45 | RES | 270r | 0,05 | R0603 | Yes | Top | SMD Resistor | Multicomp | MC 0.063W 0603 5% 270R | FEC 9331964
R46 | RES | 0r | ±1% | R0603 | Yes | Top | SMD Resistor | Multicomp | MC 0.063W 0603 0r | FEC 933-1662
R47 | RES | 0r | ±1% | R0603 | Yes | Top | SMD Resistor | Multicomp | MC 0.063W 0603 0r | FEC 933-1662
R48 | RES | 270r | 0,05 | R0603 | Yes | Top | SMD Resistor | Multicomp | MC 0.063W 0603 5% 270R | FEC 9331964
R49 | 100K_0402_1%_0.063W | 100k | ±1% | R0402 | Yes | Bottom | RESISTOR, 100K, 0.063W, 1%, 0402 | MULTICOMP | MC00625W04021100K | FEC 1358096
R50 | 100K_0402_1%_0.063W | 100k | ±1% | R0402 | Yes | Bottom | RESISTOR, 100K, 0.063W, 1%, 0402 | MULTICOMP | MC00625W04021100K | FEC 1358096
R51 | 100K_0402_1%_0.063W | 100k | ±1% | R0402 | Yes | Bottom | RESISTOR, 100K, 0.063W, 1%, 0402 | MULTICOMP | MC00625W04021100K | FEC 1358096
R52 | 100K_0402_1%_0.063W | 100k | ±1% | R0402 | Yes | Bottom | RESISTOR, 100K, 0.063W, 1%, 0402 | MULTICOMP | MC00625W04021100K | FEC 1358096
R53 | 100K_0402_1%_0.063W | 100k | ±1% | R0402 | Yes | Bottom | RESISTOR, 100K, 0.063W, 1%, 0402 | MULTICOMP | MC00625W04021100K | FEC 1358096
R54 | 100K_0402_1%_0.063W | 100k | ±1% | R0402 | Yes | Bottom | RESISTOR, 100K, 0.063W, 1%, 0402 | MULTICOMP | MC00625W04021100K | FEC 1358096
R55 | 100K_0402_1%_0.063W | 100k | ±1% | R0402 | Yes | Bottom | RESISTOR, 100K, 0.063W, 1%, 0402 | MULTICOMP | MC00625W04021100K | FEC 1358096
R56 | 100K_0402_1%_0.063W | 100k | ±1% | R0402 | Yes | Bottom | RESISTOR, 100K, 0.063W, 1%, 0402 | MULTICOMP | MC00625W04021100K | FEC 1358096
R57 | 100K_0402_1%_0.063W | 100k | ±1% | R0402 | Yes | Bottom | RESISTOR, 100K, 0.063W, 1%, 0402 | MULTICOMP | MC00625W04021100K | FEC 1358096
R58 | 100K_0402_1%_0.063W | 100k | ±1% | R0402 | Yes | Bottom | RESISTOR, 100K, 0.063W, 1%, 0402 | MULTICOMP | MC00625W04021100K | FEC 1358096
R59 | 100K_0402_1%_0.063W | 100k | ±1% | R0402 | Yes | Bottom | RESISTOR, 100K, 0.063W, 1%, 0402 | MULTICOMP | MC00625W04021100K | FEC 1358096
R60 | 100K_0402_1%_0.063W | 100k | ±1% | R0402 | Yes | Bottom | RESISTOR, 100K, 0.063W, 1%, 0402 | MULTICOMP | MC00625W04021100K | FEC 1358096
R61 | 100K_0402_1%_0.063W | 100k | ±1% | R0402 | Yes | Bottom | RESISTOR, 100K, 0.063W, 1%, 0402 | MULTICOMP | MC00625W04021100K | FEC 1358096
R62 | 100K_0402_1%_0.063W | 100k | ±1% | R0402 | Yes | Bottom | RESISTOR, 100K, 0.063W, 1%, 0402 | MULTICOMP | MC00625W04021100K | FEC 1358096
R63 | 100K_0402_1%_0.063W | 100k | ±1% | R0402 | Yes | Bottom | RESISTOR, 100K, 0.063W, 1%, 0402 | MULTICOMP | MC00625W04021100K | FEC 1358096
R64 | 10K_0402_1%_0.063W | 10k | ±1% | R0402 | Yes | Top | RESISTOR, 10K, 0.063W, 1%, 0402 | Multicomp | MC00625W0402110K | FEC 1358069
R65 | 10K_0402_1%_0.063W | 10k | ±1% | R0402 | Yes | Bottom | RESISTOR, 10K, 0.063W, 1%, 0402 | Multicomp | MC00625W0402110K | FEC 1358069
R66 | 10K_0402_1%_0.063W | 10k | ±1% | R0402 | Yes | Top | RESISTOR, 10K, 0.063W, 1%, 0402 | Multicomp | MC00625W0402110K | FEC 1358069
R67 | 10K_0805_1%_0.1W | 10k | ±1% | R0805 | Yes | Top | RESISTOR, 10K, 0.1W, 1%, 0805 | MULTICOMP | MC01W0805110K | FEC 9332391
R82 | 2K4_0603_1%_0.063W | 2k4 | ±1% | R0603 | Yes | Top | RESISTOR, 2K4, 0.063W, 1%, 0603 | MULTICOMP | MC0063W060312K4 | FEC 9330879
R83 | 0R_0603_1%_0.063W | 0r | ±1% | R0603 | Yes | Top | RESISTOR, 0603 1% 0R | MULTICOMP | MC0063W06030R | FEC 9331662
R84 | 100K_0402_1%_0.063W | 100k | ±1% | R0402 | Yes | Top | RESISTOR, 100K, 0.063W, 1%, 0402 | MULTICOMP | MC00625W04021100K | FEC 1358096
R85 | 10K_0402_1%_0.063W | 10k | ±1% | R0402 | Yes | Bottom | RESISTOR, 10K, 0.063W, 1%, 0402 | Multicomp | MC00625W0402110K | FEC 1358069
R86 | DNP_0402 | DNI | n/a | R0402 | Yes | Bottom | SMD RESISTOR 0402 | n/a | n/a | Do Not Insert
R87 | DNP_0402 | DNI | n/a | R0402 | Yes | Bottom | SMD RESISTOR 0402 | n/a | n/a | Do Not Insert
R88 | DNP_0402 | DNI | n/a | R0402 | Yes | Bottom | SMD RESISTOR 0402 | n/a | n/a | Do Not Insert
R89 | 0R_0402_1%_0.063W | 0r | ±1% | R0402 | Yes | Bottom | RESISTOR, 0402 1% 0R | Multicomp | MC00625W040210R | FEC 1357983
R90 | 0R_0402_1%_0.063W | 0r | ±1% | R0402 | Yes | Bottom | RESISTOR, 0402 1% 0R | Multicomp | MC00625W040210R | FEC 1357983
R91 | 0R_0402_1%_0.063W | 0r | ±1% | R0402 | Yes | Top | RESISTOR, 0402 1% 0R | Multicomp | MC00625W040210R | FEC 1357983
R92 | DNP_0402 | DNI | n/a | R0402 | Yes | Top | SMD RESISTOR 0402 | n/a | n/a | Do Not Insert
R93 | DNP_0402 | DNI | n/a | R0402 | Yes | Top | SMD RESISTOR 0402 | n/a | n/a | Do Not Insert
R94 | DNP_0402 | DNI | n/a | R0402 | Yes | Top | SMD RESISTOR 0402 | n/a | n/a | Do Not Insert
R95 | DNP_0402 | DNI | n/a | R0402 | Yes | Top | SMD RESISTOR 0402 | n/a | n/a | Do Not Insert
R96 | DNP_0402 | DNI | n/a | R0402 | Yes | Top | SMD RESISTOR 0402 | n/a | n/a | Do Not Insert
R97 | DNP_0402 | DNI | n/a | R0402 | Yes | Top | SMD RESISTOR 0402 | n/a | n/a | Do Not Insert
R98 | DNP_0402 | DNI | n/a | R0402 | Yes | Top | SMD RESISTOR 0402 | n/a | n/a | Do Not Insert
R99 | 0R_0402_1%_0.063W | 0r | ±1% | R0402 | Yes | Top | RESISTOR, 0402 1% 0R | Multicomp | MC00625W040210R | FEC 1357983
R100 | 0R_0402_1%_0.063W | 0r | ±1% | R0402 | Yes | Top | RESISTOR, 0402 1% 0R | Multicomp | MC00625W040210R | FEC 1357983
R101 | 0R_0402_1%_0.063W | 0r | ±1% | R0402 | Yes | Top | RESISTOR, 0402 1% 0R | Multicomp | MC00625W040210R | FEC 1357983
R102 | 100K_0402_1%_0.063W | 100k | ±1% | R0402 | Yes | Top | RESISTOR, 100K, 0.063W, 1%, 0402 | MULTICOMP | MC00625W04021100K | FEC 1358096
R103 | DNP_0402 | DNI | n/a | R0402 | Yes | Top | SMD RESISTOR 0402 | n/a | n/a | Do Not Insert
R104 | 100K_0402_1%_0.063W | 100k | ±1% | R0402 | Yes | Top | RESISTOR, 100K, 0.063W, 1%, 0402 | MULTICOMP | MC00625W04021100K | FEC 1358096
REGA | TESTPOINT |  |  | TESTPOINT | No | Top | Black Testpoint | Vero | 20-2137 | FEC 8731128
REGD | TESTPOINT |  |  | TESTPOINT | No | Top | Black Testpoint | Vero | 20-2137 | FEC 8731128
RESET | SW-PUSH-SMD |  |  | SW_PB_SMD_6MM | Yes | Top | SMD Push Button Switch (sealed 6mm x 6mm) | Omron | B3S-1000 | FEC 177-807
SL1 | SOLDER_PADS_0402 | DNI |  | 402 | Yes | Bottom | On-board Solder Shorting Link | n/a | n/a | Do Not Insert
SL2 | SOLDER_PADS_0402 | DNI |  | 402 | Yes | Bottom | On-board Solder Shorting Link | n/a | n/a | Do Not Insert
SL3 | SOLDER_PADS_0402 | DNI |  | 402 | Yes | Bottom | On-board Solder Shorting Link | n/a | n/a | Do Not Insert
SL4 | SOLDER_PADS_0402 | DNI |  | 402 | Yes | Bottom | On-board Solder Shorting Link | n/a | n/a | Do Not Insert
SL5 | SOLDER_PADS_0402 | DNI |  | 402 | Yes | Top | On-board Solder Shorting Link | n/a | n/a | Do Not Insert
SL6 | SOLDER_PADS_0402 | DNI |  | 402 | Yes | Bottom | On-board Solder Shorting Link | n/a | n/a | Do Not Insert
SL7 | SOLDER_PADS_0402 | DNI |  | 402 | Yes | Bottom | On-board Solder Shorting Link | n/a | n/a | Do Not Insert
SL8 | SOLDER_PADS_0402 | DNI |  | 402 | Yes | Bottom | On-board Solder Shorting Link | n/a | n/a | Do Not Insert
U1 | AD7616 |  |  | LQFP80-65MM-PITCH | Yes | Top | 16-Chan Dual Sim-Sar | Analog Devices | AD7616BSTZ | AD7616BSTZ
U2 | ADR421 |  |  | SO8NB | Yes | Top | 2.5V Reference | Analog Devices | ADR421ARZ | ADR421ARZ
U3 | ADP7104ARDZ-5.0 |  |  | SO8NB_RD8-2 | Yes | Top | Linear Regulator 5V, 20V, 500mA, Ultralow Noise, CMOS | Analog Devices | ADP7104ARDZ-5.0 | ADP7104ARDZ-5.0
U4 | ADP7118ARDZ-3.3 |  |  | SO8NB_RD-8-1 | Yes | Top | Linear Regulator 3.3V, Ultralow Noise, CMOS | Analog Devices | ADP7118ARDZ-3.3 | ADP7118ARDZ-3.3-R7
U5 | ADP7118ARDZ-5.0 |  |  | SO8NB_RD-8-1 | Yes | Top | Linear Regulator 5.0V, Ultralow Noise, CMOS | Analog Devices | ADP7118ARDZ-5.0 | ADP7118ARDZ-5.0-R7
U7 | 24LC32A-I/MS |  |  | MSO8 | Yes | Top | 32K I2C Serial EEPROM, MSOP8 | Microchip | 24LC32A-I/MS | FEC 1331330
V0A | SMA |  |  | SMA | No | Top | 50r SMA Jack Vertical | TE Connectivity | 5-1814832-1 | FEC 1248990
V0B | SMA |  |  | SMA | No | Top | 50r SMA Jack Vertical | TE Connectivity | 5-1814832-1 | FEC 1248990
V1A | SMA |  |  | SMA | No | Top | 50r SMA Jack Vertical | TE Connectivity | 5-1814832-1 | FEC 1248990
V1B | SMA |  |  | SMA | No | Top | 50r SMA Jack Vertical | TE Connectivity | 5-1814832-1 | FEC 1248990
V2A | SMA |  |  | SMA | No | Top | 50r SMA Jack Vertical | TE Connectivity | 5-1814832-1 | FEC 1248990
V2B | SMA |  |  | SMA | No | Top | 50r SMA Jack Vertical | TE Connectivity | 5-1814832-1 | FEC 1248990
V3A | SMA |  |  | SMA | No | Top | 50r SMA Jack Vertical | TE Connectivity | 5-1814832-1 | FEC 1248990
V3B | SMA |  |  | SMA | No | Top | 50r SMA Jack Vertical | TE Connectivity | 5-1814832-1 | FEC 1248990
V4A | SMA |  |  | SMA | No | Top | DNI | TE Connectivity | DNI | Do Not Insert
V4B | SMA |  |  | SMA | No | Top | DNI | TE Connectivity | DNI | Do Not Insert
V5A | SMA |  |  | SMA | No | Top | DNI | TE Connectivity | DNI | Do Not Insert
V5B | SMA |  |  | SMA | No | Top | DNI | TE Connectivity | DNI | Do Not Insert
V6A | SMA |  |  | SMA | No | Top | DNI | TE Connectivity | DNI | Do Not Insert
V6B | SMA |  |  | SMA | No | Top | DNI | TE Connectivity | DNI | Do Not Insert
V7A | SMA |  |  | SMA | No | Top | DNI | TE Connectivity | DNI | Do Not Insert
V7B | SMA |  |  | SMA | No | Top | DNI | TE Connectivity | DNI | Do Not Insert
VDD | TESTPOINT |  |  | TESTPOINT | No | Top | Black Testpoint | Vero | 20-2137 | FEC 8731128
VDRIVE | TESTPOINT |  |  | TESTPOINT | No | Top | Black Testpoint | Vero | 20-2137 | FEC 8731128
X1 | CLAMP-14MM |  |  | CLAMP-14MM | No | Top | 14mm QFP Clamp | IM Tech |  | Do Not Insert
Screw1 |  |  |  |  |  |  | SCREW, CHEESE, NYLON, M3X10, PK100 | Allthread | 119030010 | FEC 7070597
Screw2 |  |  |  |  |  |  | SCREW, CHEESE, NYLON, M3X10, PK100 | Allthread | 119030010 | FEC 7070597
Nut1 |  |  |  |  |  |  | NUT/WASHER, NYLON, M3, PK100 | Duratool | 1140030 | FEC 7061857
Nut2 |  |  |  |  |  |  | NUT/WASHER, NYLON, M3, PK100 | Duratool | 1140030 | FEC 7061857
 | Distributor Web Sites |  |  |  |  | Parts Not Inserted
 | FEC | www.farnell.com |  |  |  | ADI Supplied Parts
 | Digikey | www.digikey.com |  |  |  | Bare Board |  | EVAL-AD7616SDZ Rev-D (08-039639-D)
 | Analog Devices | www.analog.com |  |  |  | 4 x Stick on feet |  | Do Not Cover Mounting holes with feet, height must be greater than maximum component height on bottom side.
 | Mouser | www.mouser.com |  |  |  | 4 x Pluggable Terminal Blocks (for J1, J2, J3 & J4) |  | Phoenix Contact | 1803633 | FEC 3704956
 |  | www.stontronics.co.uk |  |  |  | Packing Material |  | Bubble Wrap
 |  |  |  |  |  | Board to be placed in suitable sized Anti-static bag
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

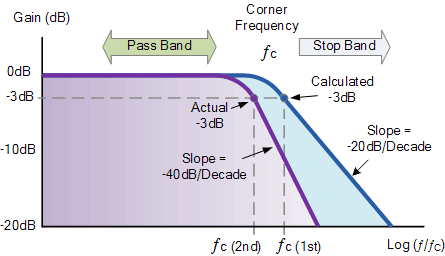
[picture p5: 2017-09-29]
Photos/Common/FrequencyResponseOfA2stOrderLowPassFilter.gif

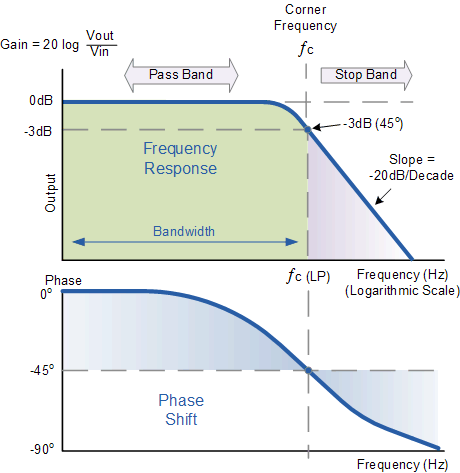
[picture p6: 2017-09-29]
Photos/Common/FrequencyResponseOfA1stOrderLowPassFilter.gif

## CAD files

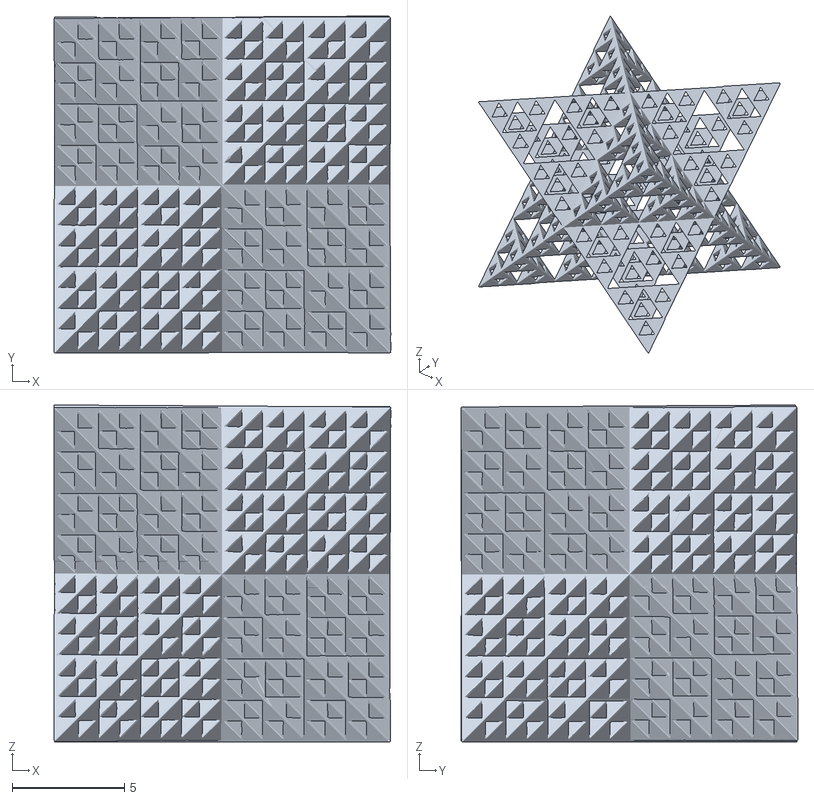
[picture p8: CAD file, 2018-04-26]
Hardware/Design/Antenna/merkaba_(level 3).stl
15.0 x 15.0 x 15.0

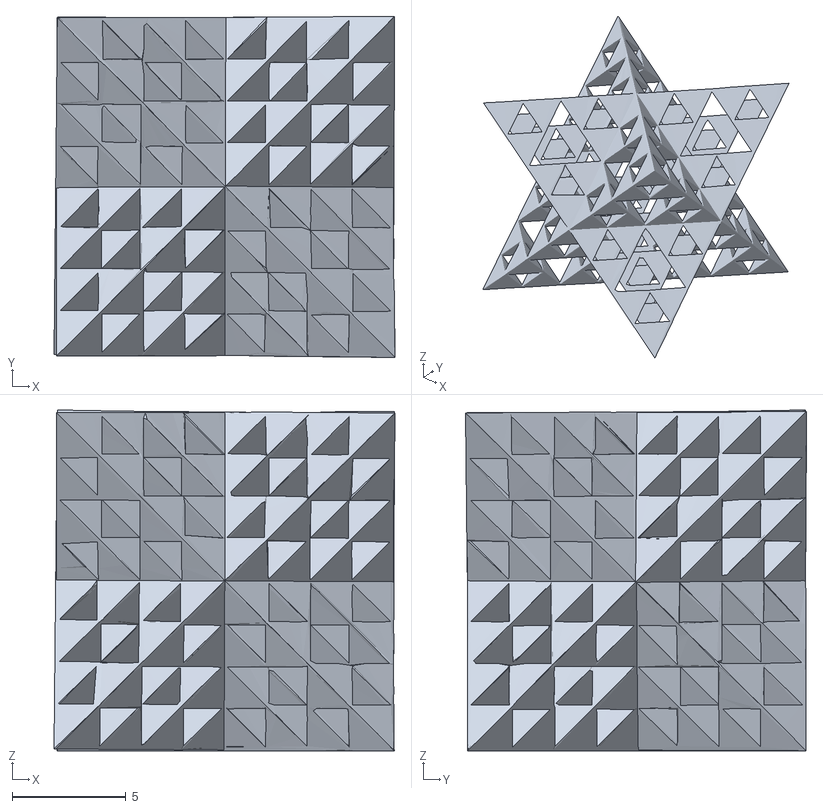
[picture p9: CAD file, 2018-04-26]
Hardware/Design/Antenna/merkaba_(level 2).stl
15.0 x 15.0 x 15.0

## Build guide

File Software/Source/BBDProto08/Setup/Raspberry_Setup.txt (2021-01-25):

# https://darryldias.me/2021/install-and-setup-net-5-on-raspberry-pi/

wget https://download.visualstudio.microsoft.com/download/pr/567a64a8-810b-4c3f-85e3-bc9f9e06311b/02664afe4f3992a4d558ed066d906745/dotnet-sdk-5.0.101-linux-arm.tar.gz
wget https://download.visualstudio.microsoft.com/download/pr/11977d43-d937-4fdb-a1fb-a20d56f1877d/73aa09b745586ac657110fd8b11c0275/aspnetcore-runtime-5.0.1-linux-arm.tar.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

mkdir ~/.dotnet

tar -xvf dotnet-sdk-5.0.101-linux-arm.tar.gz -C ~/.dotnet
tar -xvf aspnetcore-runtime-5.0.1-linux-arm.tar.gz -C ~/.dotnet

nano ~/.bashrc

export DOTNET_ROOT=$HOME/.dotnet 
export PATH=$PATH:$HOME/.dotnet

dotnet --version

# https://docs.microsoft.com/en-us/dotnet/core/install/linux-debian

x, Clone the repo on the Raspberry
cd ~/Work/BioBalanceDetector
git clone https://github.com/andrasfuchs/BioBalanceDetector.git

x, Update the repo on the Raspberry
cd ~/Work/BioBalanceDetector
git pull

x, Build the .NET source code on the Raspberry
cd ~/Work/BioBalanceDetector/Software/Source/BBDProto08/BBD.SleepLogger
dotnet build

x, Publish the .NET app on the Raspberry
cd ~/Work/BioBalanceDetector/Software/Source/BBDProto08/BBD.SleepLogger
dotnet publish --configuration release --runtime linux-arm --self-contained true --output ~/Work/BBD.SleepLogger

x, Run the .NET app on the Raspberry
cd ~/Work/BBD.SleepLogger
./BBD.SleepLogger

x, Configure the .NET 5 app to run as background services
sudo apt-get install supervisor

sudo nano /etc/supervisor/supervisord.conf
# change chmod=0700 to chmod=0766 @ line 5

sudo nano /etc/supervisor/conf.d/bbd.conf

[group:bbd]
programs=SleepLogger

[program:SleepLogger]
directory=/home/pi/Work/BBD.SleepLogger
command=/home/pi/Work/BBD.SleepLogger/BBD.SleepLogger
autostart=true
autorestart=true
stderr_logfile=/var/log/BBD.SleepLogger.err.log
stdout_logfile=/var/log/BBD.SleepLogger.out.log
user=pi
environment=HOME="/home/pi",USER="pi"
stopsignal=INT
stopasgroup=false

sudo service supervisor restart

supervisorctl status all
supervisorctl stop bbd:
supervisorctl start bbd:

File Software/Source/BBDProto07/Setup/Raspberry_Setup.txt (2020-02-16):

1, Format SD card with SD Card Formatter [https://www.sdcard.org/downloads/formatter_4/eula_windows/SDCardFormatterv5_WinEN.zip]

2, Extract NOOBS to the SD card [https://www.raspberrypi.org/downloads/noobs/]

3, Install Raspbian full

4, Set fixed IP to 192.168.1.35 (wired) and 192.168.1.36 (wireless)

5, Enable VNC, I2C and SPI interfaces

6, Install updates

7, Set timezone and WiFi country

8, Use VNC Viewer to connect [https://www.realvnc.com/download/file/viewer.files/VNC-Viewer-6.19.107-Windows.exe]

8, Setup SAMBA share [https://www.raspberrypi.org/magpi/samba-file-server/]

9, Install .NET Core SDK ARM32 [https://dotnet.microsoft.com/download/dotnet-core/current]
	Copy dotnet-sdk-3.1.101-linux-arm.tar.gz to Pi
	mkdir -p $HOME/dotnet && tar zxf dotnet-sdk-3.1.101-linux-arm.tar.gz -C $HOME/dotnet
	
	# add these two lines to ~/.bashrc
	export DOTNET_ROOT=$HOME/dotnet
	export PATH=$PATH:$HOME/dotnet
	
10, Install VSDbg [https://github.com/OmniSharp/omnisharp-vscode/wiki/Remote-Debugging-On-Linux-Arm]
	curl -sSL https://aka.ms/getvsdbgsh | bash /dev/stdin -r linux-arm -v latest -l ~/vsdbg
	
11, Switch to the Windows 10 machine	
	
12, Download WinSCP client and its .NET assembly / COM library [https://winscp.net/eng/downloads.php]
	
13, Start a new .NET Core 3.1 project in Visual Studio 2019

14, Install Pi packages:
		Install-Package Unosquare.Raspberry.IO
		Install-Package Unosquare.WiringPi
		Install-Package Unosquare.RaspberryIO.Peripherals
		
15, Build the project

16, Create a DeployToPi.ps1 script in the project folder [https://medium.com/@lewwybogus/debugging-your-net-core-3-app-on-your-raspberry-pi-with-visual-studio-2019-9662348e79d9]

17, Put this .ps1 file into the root of the new project, and extract the WinSCP .NET assembly (WinSCPnet.dll) into that folder too

18, Open PowerShell with administrator privileges, run "Set-ExecutionPolicy RemoteSigned", and run ".\DeployToPi.ps1" 

19, Press Ctrl + Alt + P in Visual Studio, and attach to SSH/192.168.1.36/

20, Next time press Shift + Alt + P to reattach the debugger to the same process

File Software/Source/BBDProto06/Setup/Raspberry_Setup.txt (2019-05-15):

1, Format SD card with SD Card Formatter [https://www.sdcard.org/downloads/formatter_4/eula_windows/SDCardFormatterv5_WinEN.zip]

2, Extract NOOBS to the SD card [https://www.raspberrypi.org/downloads/noobs/]

3, Install Raspbian full

4, Set fixed IP to 192.168.1.35 (wired) and 192.168.1.36 (wireless)

5, Enable VNC, I2C and SPI interfaces

6, Install updates

7, Set timezone and WiFi country

8, Use VNC Viewer to connect [https://www.realvnc.com/download/file/viewer.files/VNC-Viewer-6.19.107-Windows.exe]

8, Setup SAMBA share [https://www.raspberrypi.org/magpi/samba-file-server/]

9, Install .NET Core SDK ARM32 [https://dotnet.microsoft.com/download/dotnet-core/2.2]
	Copy dotnet-sdk-2.2.105-linux-arm.tar.gz to Pi
	mkdir -p $HOME/dotnet && tar zxf dotnet-sdk-2.2.105-linux-arm.tar.gz -C $HOME/dotnet
	
	# add these two lines to ~/.bashrc
	export DOTNET_ROOT=$HOME/dotnet
	export PATH=$PATH:$HOME/dotnet
	
10, Install VSDbg [https://github.com/OmniSharp/omnisharp-vscode/wiki/Remote-Debugging-On-Linux-Arm]
	curl -sSL https://aka.ms/getvsdbgsh | bash /dev/stdin -r linux-arm -v latest -l ~/vsdbg

11, Create a Raspberry Pi 3 app from template 
	dotnet new -i "RaspberryPi.Template::*"
	dotnet new coreiot -n MyNewIoTProject

12, Preprare project
	Add win10-arm;linux-arm as RuntimeIdentifiers
	Install Pi packages:
		Install-Package Unosquare.Raspberry.IO
		Install-Package Unosquare.WiringPi
		Install-Package Unosquare.RaspberryIO.Peripherals

13, Create a publish profile to publish to a local folder (debug,self-contained,netcoreapp2.2,linux-arm) 

14, Set up WinSCP's Commands/Keep Remote Directory up to Date function on that folder

15, Run the app on the Pi

16, Attach debugger to the process on Pi using SSH
	DEV: Visual Studio > Debug > Attach to process > SSH > Pi

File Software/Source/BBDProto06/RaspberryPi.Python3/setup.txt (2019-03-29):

@Pi> sudo pip3 install rpi_ws281x adafruit-circuitpython-neopixel

@PC> WinSCP > Commands > Keep remote folder up to date (Ctrl+U)

@PC> Visual Studio > open rpi_neopixel_simpletest.py

@PC> PuTTY > sudo python3 ~/Documents/Work/rpi_neopixel_simpletest.py

# https://learn.adafruit.com/neopixels-on-raspberry-pi/raspberry-pi-wiring
# sudo pip3 install rpi_ws281x adafruit-circuitpython-neopixel
# rpi_neopixel_simpletest.py

# https://learn.adafruit.com/mlx90393-wide-range-3-axis-magnetometer/circuitpython
# sudo pip3 install adafruit-circuitpython-mlx90393
# sudo python3 ~/Documents/Work/adafruit_mlx90393_simpletest.py

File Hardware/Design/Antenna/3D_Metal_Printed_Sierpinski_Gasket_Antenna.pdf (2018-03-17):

________________________________________________________________________________________
Department of Engineering Technology, Waterford Institute of Technology, Waterford, Ireland e-mail: 20061369@mail.wit.ie, poleary@wit.ie
SEAM Research Centre, Waterford Institute of Technology, Waterford, Ireland
e-mail: rraghavendra@mail.wit.ie

# 3D Metal Printed Sierpinski Gasket Antenna

### Deepak Shamvedi¹

### , Oliver J. McCarthy¹,2, Eoghan O’Donoghue¹,2, Paul O’Leary¹

,

### Ramesh Raghavendra¹,2

Abstract In this research, the design, simulation, and fabrication of the first ever 3D metal printed Sierpinski gasket antenna, with multiple resonance characteristics is reported. The antenna is fabricated from Titanium alloy Ti-6Al-4V, using the Direct Metal Laser Sintering (DMLS) technique. Mechanical considerations like Rumsey’s principle and the support structures required for overhanging 3D printed structures have also been studied in detail and discussed. The validity of the DMLS technique for manufacturing a complex shaped (fractal) antenna is assessed, by comparing CST (Computer Simulation Technology) simulation results with the measured data.

### 1 INTRODUCTION

Additive Manufacturing (AM) or 3D printing technology allows 3D parts to be fabricated directly from Computer Aided Design (CAD) data, sliced into stacks or in a layer-by-layer fashion, without the need to plan the transformation from 2D into 3D. Complex parts, which were extremely difficult or in some cases impossible to be manufactured at all using conventional tooling methods, can now be built with a short lead time, with good reliability and the high level of precision [1]. In a very short span of time, AM has found its application in almost all leading engineering areas, such as aerospace, automotive, medical fields, consumer products and military. Recent research in 3D printing has also focused on RF/Microwave components [2]-[4]. These 3D
components | can | be | fabricated | using
Stereolithography, where the physical structure is fabricated using non-conducting thermoplastics, such as Acrylonitrile Butadiene Styrene (ABS), and then usually metallized or painted in order to make the printed electromagnetic component functional. Uniform coating or selective coating, adds an extra processing step over the polymer printed component, and also has to be done very precisely, in order to achieve acceptable electromagnetic performance from the component.
This research presents the first 3D metal printed Sierpinski gasket antenna for wireless applications using DMLS technology. In earlier published research, DMLS has already been used to manufacture a waveguide fed antenna array, while EBM has been used to manufacture a 3D printed metallic horn antenna [3] [4]. Both the DMLS and EBM antennae have been produced as early demonstrations of the power of AM for microwave components, using metallic materials. In this research, the selection of the Sierpinski gasket antenna is done as another early example of

3D printing, where the geometry is more complex. The aim of this research is to push the limits of 3D metal printing in the field of complex antenna manufacturing. However, 3D metal printing imposes some unexpected restrictions on antenna design, which will be outlined later in section 4.

### 2 SIERPINSKI GASKET ANTENNA

The Sierpinski gasket is named after the Polish mathematician Sierpinski, who described some of the main properties of a fractal shape in 1916 [5]. In this case, the discontinuities (or fractals), increase the perimeter of the material so that the antenna has multiple electrical lengths, which leads to multiband behavior [6]. Historically, this feature has been exploited in 2D antenna designs, but in this research, a 3D extension is presented, so instead of triangles, tetrahedrons are arranged in a self-symmetric fashion.
To the best of the authors’ knowledge, a 3D Sierpinski antenna has only been built twice [7] [8]. Anguera. J, et al in [7], presented a very light-weight, fractal-shaped, Sierpinski-carpet, cylindrical hole, monopole antenna, fabricated with metallized foam,
where | the | antenna | possessed | multiband
characteristics. In [8], the first 3D full-metal version of a Sierpinski gasket antenna was manually fabricated using brass. The antenna possessed multiband characteristics; however, differences between computational and measured results could be easily seen, which might have occurred due to
geometrical | inaccuracies | during | the | manual
fabrication of this complex-shaped antenna. The manual fabrication challenges mean that the differences between the measured and simulation results will increase, if the radiating monopole structure were designed for a higher wavelength.

### 3 ANTENNA FABRICATION

The proposed antenna was fabricated using the DMLS machine EOSINT M280, with the Titanium alloy Ti-6Al-4V as the conducting material. The antenna designed is a 2nd iteration, Sierpinski gasket antenna, with a large side length of 46.7 mm, on a finite rectangular copper ground plane, of area 160 mm x 100 mm, with 1 mm thickness, as shown in Figure 1.

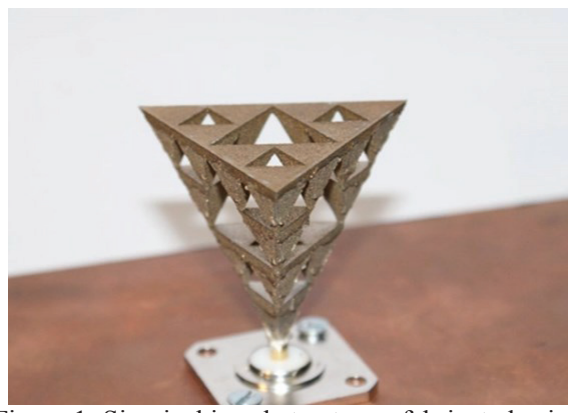
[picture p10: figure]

Figure 1: Sierpinski gasket antenna fabricated using DMLS technology on Ti-6Al-4V

### 4 MECHANICAL CONSIDERATIONS

### 4.1 Support Structures

In the process of 3D printing, where models are built layer-by-layer, each layer is supported by previously printed layers underneath it. In order to print structures with shallow angles (with reference to the horizontal plane building plate) and cantilever sections, extra support structures are needed to ensure the printed objects’ integrity and print quality. An industry rule of thumb with DMLS technology is that support structures are needed, if the structure has an overhanging angle () less than a material-specific value. For example, with the Ti-6Al-4V allow used here, =45º. The overhanging angle varies from material to material, as well as from technique to technique, and also depends on other factors, such as manufacturing layer thickness, the width of the printed line, and the melt temperature, to ensure a high print quality [9]. While the proposed Sierpinski gasket antenna satisfies the condition of the maximum overhanging angle () for the alloy Ti-6Al-4V using DMLS, i.e. =60º, nonetheless a conservative approach was taken and support structures were still added, as shown in Figure 2.

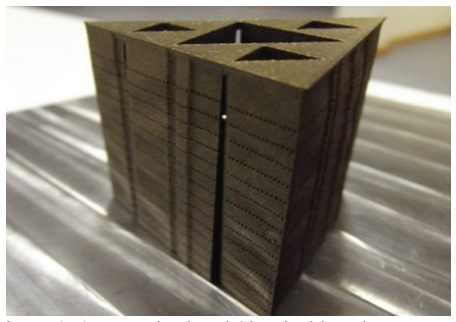
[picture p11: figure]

Figure 2: 3D metal printed Sierpinski gasket antenna with build support structure

The supports appear as individual pillars, constructed as a network of interconnected pieces, deliberately brittle for easy removal from the model.

### 4.2 Build Orientation

The recent research has shown that build orientation plays an important role in influencing the construction time as well as the mechanical properties of the printed structure. In publication [10], the author has mentioned the importance of considering the build orientation of 0º, 45º, and 90º on test samples during the designing process. It was concluded that the mechanical properties such as tensile strength, residual stress, fatigue as well as surface roughness are highly dependent on the orientation of the build.
However, due to the complex geometry of the Sierpinski antenna, it was decided to choose a build orientation of 90º w.r.t the building platform, so that the proposed antenna corresponds to the minimum fatigue and possess maximum tensile strength.

### 4.3 Ring Width

The “ring width” (parameter related to the width of the excitation point) of the Sierpinski gasket antenna is important from the perspective of multiband features. V H Rumsey, in the early sixties, established what is now known as Rumsey’s Principle and is the current notion of broadband antennae. According to Rumsey’s Principle, if the geometry of an antenna is solely the function of an angle, then the antenna parameters will be independent of the frequency [11]. However, in 1999 Hohlfeld and Cohen proposed an extension to Rumsey’s Principle, known as the Hohlfeld-Cohen-Rumsey (HCR) condition, stating that self-symmetry is one of the underlining requirements. For the antenna to be frequency independent, it needs to be symmetric along the origin as well, where the origin is the antenna feeding point [12]. However, as the flare angle in the case of Sierpinski gasket antenna remain fixed at approximately 60º, the HCR condition will not be considered further in this work. But it should also be noted that even the slightest variation caused at the ring width have an impact on antenna’s input impedance.
One more complication related to the ring width is that having an antenna built in an upside-down orientation, a minimum of 1.90 mm of ring width diameter is required to successfully build the antenna. Furthermore, in order to connect the antenna with a feeding circuit, the ring width should be big enough to facilitate soldering, if required. It should also be noted the ring width may be further increased when soldering or conductive epoxy is applied to the feed point.
CST simulations were carried out and are shown in Figure 3. During the simulation, it was observed that even a minor increase in the radius value (r) of ring width causes the wider antenna bandwidth and also lead the antenna resonance frequency dip to shift
towards | the | higher | frequency | bands.

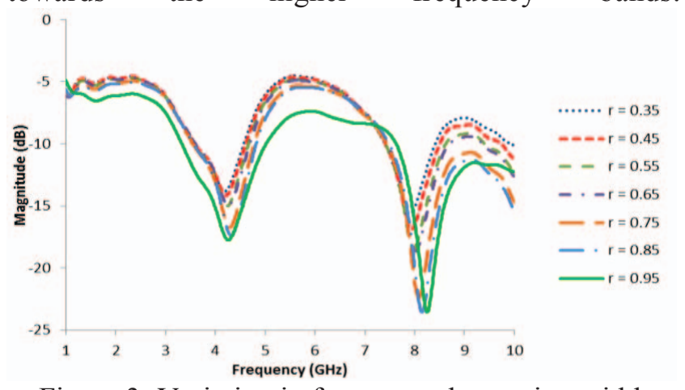
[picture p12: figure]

Figure 3: Variation in frequency due to ring width effect

### 4.4 Feed Point Challenges

After the antenna fabrication, the next task was to connect the antenna circuitry to an N-type connector. One of the major challenges faced, as the antenna was fabricated from Titanium, was to establish an RF antenna connection with a feeding circuitry. The chosen Titanium alloy is very difficult to solder, as the metals oxidize readily as its temperature elevates during soldering, making it extremely difficult to solder an antenna onto a connector. For this reason, the antenna was glued onto the connector with the help of a conductive silver epoxy adhesive having < .001-cm volume resistivity.
As can be seen in Figure 4, a laboratory clamp was employed to mount the antenna onto the feed.

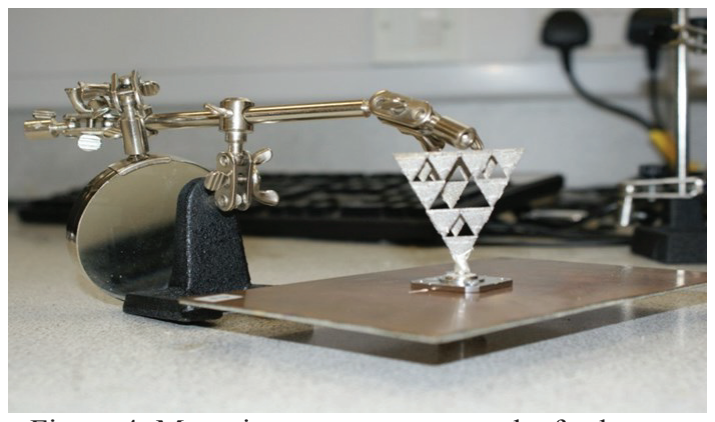
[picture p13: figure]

Figure 4: Mounting an antenna onto the feed setup

It is also noteworthy that a challenge in the gluing process was achieving a consistent, perpendicular orientation was not easy. Mounting an antenna in this way may lead to variation in the input impedance from one mounting to another, and hence, a better set up will be employed in the future. However, this variation should be quite small, as has been shown in publication [13], where the author has performed experiments on the variation of the input impedance due to changes in the tilt angle of a planar monopole antenna.

### 4.5 Equilateral Triangle

A three-dimensional Sierpinski gasket antenna is an arrangement of tetrahedrons in a self-symmetric fashion stacked one upon another, which gives the antenna multiband characteristics. However, in practice, a 3D Sierpinski gasket antenna cannot be realized with infinitely small joints (unlike a 2D realization) to be mechanically rigid, for example in practice, one tetrahedron should overlap the adjacent one. This was confirmed during the physical examination of the antenna, as it was observed that the triangular sides were not perfectly equilateral. This means that the antenna geometry is no longer in the shape of an equilateral triangle, but is now simply an isosceles triangle. However, it does not affect the multiband behavior of the antenna, as the structure is still self-symmetric.

### 5 RESULTS

The above-mentioned antenna was designed, optimized and simulated on CST software. The return loss coefficient (S11) and path loss (S21) of the antenna were measured on a Rhode and Schwarz ZVB 20 Vector Network Analyser (VNA). Figure 5 shows the comparison of measured and simulated reflection characteristics of the 3D metal printed Sierpinski gasket antenna. Both the results are in good agreement with each other.

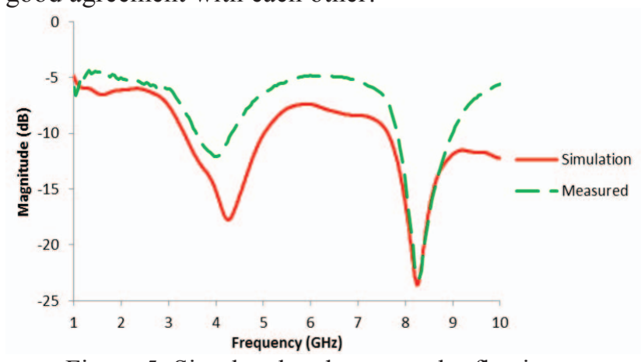
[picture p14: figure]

Figure 5: Simulated and measured reflection coefficient

The antenna resonates at both the fundamental frequencies, of 4.2 GHz and 8.4 GHz, maintaining its multiband feature. The measured and simulated gains at both the corresponding resonant frequencies are shown in Figure 6.

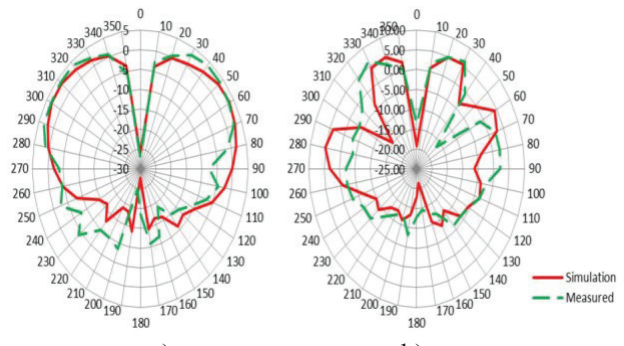
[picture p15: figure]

a) b)

Figure 6: Simulated and measured gain radiation pattern a) 4.2 GHz b) 8.4 GHz

The simulated gain at 4.2 GHz was found to be 5.07 dB compared to the measured gain of 4.07 dB, at 8.4 GHz, the measured gain was found to be 4.45 dB compared to the simulated gain of 6.64 dB. The difference between the measured and the simulation value could be due to the effect of surface roughness, this effect is significant at higher frequencies. However, in this research, no efforts have been made to reduce the surface roughness of the antenna using surface treatment process such as wetblasting or polishing as explained in [14], which could lead to further improvement of results.

### 4 CONCLUSION

From an RF design and realization perspective, 3D printing offers great advantages, as an efficient and easy method for printing complex geometries.
The complex geometry antenna described in this work is a Sierpinski gasket antenna, created using a DMLS 3D metal printer. The design restrictions and challenges are explained in detail in the body of the work. The antenna RF performance was measured and found to be in good agreement with simulation results, in terms of bandwidth and radiation characteristics.

References

[1] F. Niesler and M. Hermatschweiler, "Additive manufacturing of micro-sized parts-trend of
miniaturization | is | driver | for | 3D | laser
lithography," Laser Technik Journal, vol. 11, no. 5, p. 16–18, 2014.
[2] T. Le, B. Song, Q. Liu, R. Bahr, S. Moscato, C.-
P. Wong and M. Tentzeris, "A novel strain sensor based on 3D printing technology and 3D antenna design," in 2015 IEEE 65th Electronic Components and Technology Conference (ECTC), San Diego, CA, 2015.
[3] H. Guan-Long, Z. Shi-Gang, C. Tan-Huat and Y. Tat-Soon, "3-D metal-direct-printed wideband and high-efficiency waveguide-fed antenna array," in International Microwave Symposium, Phoenix, AZ, 2015.
[4] C. Garcia, R. Rumpf, H. Tsang and J. Barton, "Effects of extreme surface roughness on 3D printed horn antenna," IET, vol. 49, no. 12, pp. 734 - 736, 2013.
[5] H.O. Peitgen, H. Jürgens and D. Saupe, Chaos and Fractals: New Frontiers of Science, 2nd ed., New York: Springer-Verlag, 2004.
[6] R. Batra, P. L. Zade and D. Sagne, "Design and implementation of Sierpinski carpet fractal
antenna | for | wireless | communications,"
International Journal of Scientific Research Engineering & Technology (IJSRET), vol. 1, no. 4, pp. 043-047, 2012.
[7] J. Anguera, J. P. Daniel, C. Borja, J. Mumbru, C. Puente, T. Leduc, K. Sayegrih and P. V. Roy, "Metallized foams for antenna design: application to fractal-shaped Sierpinski-carpet monopole," Progress In Electromagnetics Research, vol. 104, pp. 239-251, 2010.
[8] M. Alaydrus, "Analysis of Sierpinski gasket
tetrahedron | antennas," | Journal | of
Telecommunications, vol. 5, no. 2, pp. 6-10, 2010.
[9] J. Kranz, D. Herzog and C. Emmelmann, "Design guidelines for laser additive manufacturing of lightweight structures in TiAl6V4," Journal of Laser Application, vol. 27, no. 1, pp. 1-16, 2015.
[10] W. Vree, "On the influence of build orientation on the mechanical properties of direct metal laser sintered (DMLS) Ti-6Al-4V flexures," 04 April 2016. [Online]
[11] V. Rumsey, Frequency independent antennas, New York and London: Academic Press, 1966.
[12] R. G. Holfield, N. Cohen, "Self-similarity and the geometric requirements for frequency independence in antennae," Fractals - Complex Geometry, Patterns, and Scaling in Nature and Society, vol. 07, no. 1, pp. 79-84, 1999.
[13] Z. N. Chen, "Experiments on input impedance of tilted planar monopole antenna," Microwave and Optical Technology Letter, vol. 26, no. 3, pp. 202-204, 2000.
[14] D. Shamvedi, O. McCarthy, E. O'Donoghue,
P. O’ Leary and R. Raghavendra, “Surface treatment of 3D metal printed microwave components,” 18th Research Colloquium on Radio Science and Communications for a Smarter World, Dublin, March 2017.

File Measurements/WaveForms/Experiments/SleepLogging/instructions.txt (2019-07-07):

Laptop + mobile phone
0, put phone into silent mode
1, start DroidCam on the phone and put the phone on the stand
2, start OBS and load preset (720p stereo, x264, DroidCam video, laptop mic audio ch1, desktop audio ch2)
3, connect headphones
4, load meditation mp3
5, put on conductive glove/sock/electrode
6, start biosignal recording with start_aqusition.bat
7, start recording in OBS
8, play meditation mp3
9, sign and say meditation depth while meditating
10, stop recording

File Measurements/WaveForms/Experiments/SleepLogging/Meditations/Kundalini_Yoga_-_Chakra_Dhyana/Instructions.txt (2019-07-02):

Sit with your eyes closed, spine erect but not rigid.
Rest your hands on your thighs with palms facing up, index fingertips touching the tip of each thumb for the first three chakras, touching the middle joint of each thumb for the fourth & fifth chakras and the base of the thumb for the sixth & seventh chakras.
If you wish you may touch the tip of the tongue to the roof of your mouth. Take several long, slow, easy deep breaths breathing through your nose, until your body becomes calm. Sit during this meditation. Do not lie down. 
As we come to each chakra, focus your attention on the indicated area of your body. With each exhale chant the mantra that is given in a slow, elongated fashion. Begin with the root chakra (Mooladhara) and work upward to the Crown (Sahasrara). At the end always allow the energy to ground, flowing down through your body, and spend a few minutes in meditation or lie on your back in shavasan.
 
1. Begin with the Mooladhara chakra, located at the perineum, midway between your anus and genitals.
Say "Om Mooladhara".
Visualize its red color. Slowly repeat "Lang" (pronounced lung) for a few minutes, then visualize the chakra turning liquid gold as you say "Kundalini, arohanum" several times.
 
2. The Swadhisthana chakra, located in the genital region or at the base of the spine.
Say "Om Swadhisthana".
Visualize its orange color. Say "Vang" (pronounced vung) for a few minutes, then visualize the chakra turning liquid gold as you say "Kundalini, arohanum" several times.
 
3. The Manipura chakra, located at the navel.
Say "Om Sri Mani Padme Hum".
Visualize its yellow color. Say "Rang" (pronounced rung) for a few minutes, then visualize the chakra turning liquid gold as you say "Kundalini, arohanum" several times.
 
4. The Anahata chakra, in the center of your chest, your spiritual heart.
Say "Om Anahata".
Visualize its green color. Say "Yang" (pronounced yung) for a few minutes, then visualize the chakra turning liquid gold as you say "Kundalini, arohanum" several times.
 
5. The Vishuddhi chakra, located in your throat, at the Adam's apple or the epiglottis.
Say "Om Vishuddhi".
Visualize its blue color. Say "Hang" (pronounced hung) for a few minutes, then visualize the chakra turning liquid gold as you say "Kundalini, arohanum" several times.
 
6. The Ajneya chakra, located between our eyebrows.
Say "Om Ajneya".
Visualize its indigo color, the color of the original Levi blue jeans prior to washing them. Say "AUM" in a 3-2-1 ratio. "A-A-A-O-O-M" for a few minutes, then visualize the chakra turning liquid gold as you say "Kundalini, arohanum" several times.
 
7. The Sahasrara chakra, located at the center of the top of your head.
Say "Om Sahasrara".
Visualize its violet color, pastel purple.
Say "Ogum Satyam Om" for a few minutes, then visualize the chakra turning liquid gold as you say "Kundalini, arohanum" several times.
 
Lie Down in Shavasan
 
Lie down with your eyes closed immediately after the meditation, and relax for at least 10 or 20 minutes, or as long as you like. Yoga's Corpse Pose, Shavasan, is good for this (eyes closed, on your back with arms loosely to the sides, palms up, legs slightly apart). Let go. Enjoy. Notice the dynamics of the energy in your body as the kundalini flows.

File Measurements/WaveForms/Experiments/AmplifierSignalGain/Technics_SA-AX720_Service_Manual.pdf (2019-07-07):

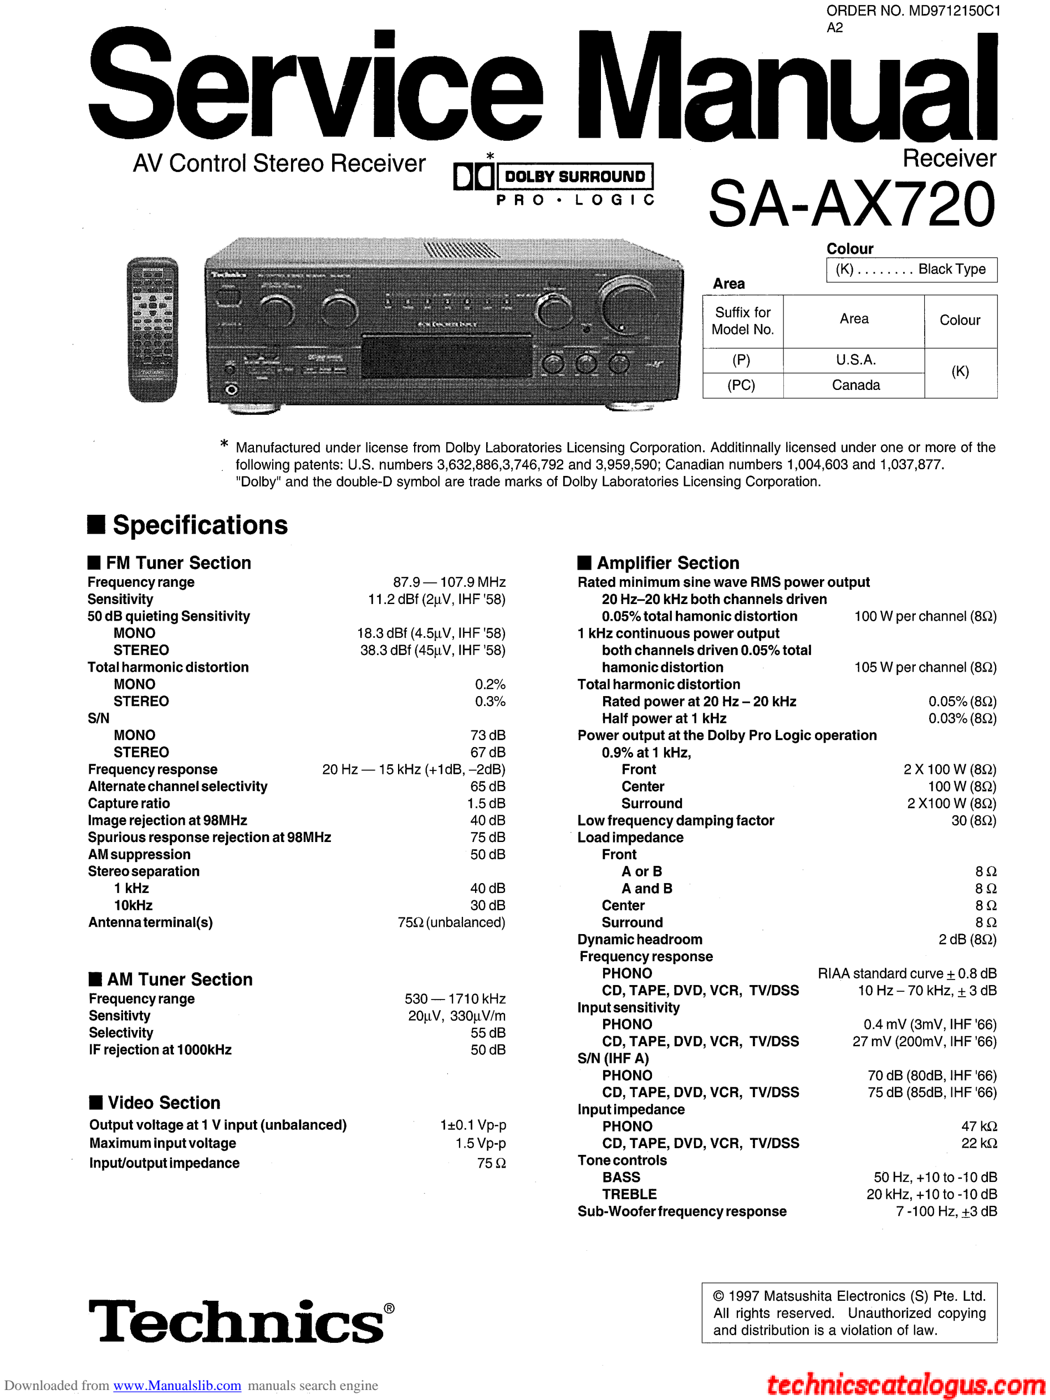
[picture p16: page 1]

Downloaded from www.Manualslib.com manuals search engine

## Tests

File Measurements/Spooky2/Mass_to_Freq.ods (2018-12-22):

INPUT |  | Atomic mass or Molecular weight |  |  |  |  |  |  | OUTPUT
 |  |  |  |  | 615.046343 ; 78725.932008 |  | 217.1966 ; 27801.16541
 |  | 206.32556 | amu or g/mol
 |  | 3.4261165294E-25 | Kg
 |  |  |  |  | Remote Mode |  | Contact Mode
 |  |  |  | SubHarmonic
 | Speed of light Vacuum | 299,792,458.0 | m/s | 1 | 46,471,587,831,075,400,000,000,000.000 |  | 16,410,911,465,097,700,000,000,000.000
 | Speed of light Tisuue | 105,868,288.9 | m/s | 2 | 23,235,793,915,537,700,000,000,000.000 |  | 8,205,455,732,548,850,000,000,000.000
 | Avogadro constant | 6.0221407600E+23 | 1/mol | 3 | 11,617,896,957,768,900,000,000,000.000 |  | 4,102,727,866,274,420,000,000,000.000
 | Planck constant | 6.6260700730E-34 | J s | 4 | 5,808,948,478,884,430,000,000,000.000 |  | 2,051,363,933,137,210,000,000,000.000
 |  |  |  | 5 | 2,904,474,239,442,220,000,000,000.000 |  | 1,025,681,966,568,610,000,000,000.000
 |  |  |  | 6 | 1,452,237,119,721,110,000,000,000.000 |  | 512,840,983,284,303,000,000,000.000
 |  |  |  | 7 | 726,118,559,860,554,000,000,000.000 |  | 256,420,491,642,151,000,000,000.000
 |  |  |  | 8 | 363,059,279,930,277,000,000,000.000 |  | 128,210,245,821,076,000,000,000.000
 |  |  |  | 9 | 181,529,639,965,138,000,000,000.000 |  | 64,105,122,910,537,900,000,000.000
 |  |  |  | 10 | 90,764,819,982,569,200,000,000.000 |  | 32,052,561,455,268,900,000,000.000
 |  |  |  | 11 | 45,382,409,991,284,600,000,000.000 |  | 16,026,280,727,634,500,000,000.000
 |  |  |  | 12 | 22,691,204,995,642,300,000,000.000 |  | 8,013,140,363,817,230,000,000.000
 |  |  |  | 13 | 11,345,602,497,821,200,000,000.000 |  | 4,006,570,181,908,620,000,000.000
 |  |  |  | 14 | 5,672,801,248,910,580,000,000.000 |  | 2,003,285,090,954,310,000,000.000
 |  |  |  | 15 | 2,836,400,624,455,290,000,000.000 |  | 1,001,642,545,477,150,000,000.000
 |  |  |  | 16 | 1,418,200,312,227,640,000,000.000 |  | 500,821,272,738,577,000,000.000
 |  |  |  | 17 | 709,100,156,113,822,000,000.000 |  | 250,410,636,369,289,000,000.000
 |  |  |  | 18 | 354,550,078,056,911,000,000.000 |  | 125,205,318,184,644,000,000.000
 |  |  |  | 19 | 177,275,039,028,456,000,000.000 |  | 62,602,659,092,322,100,000.000
 |  |  |  | 20 | 88,637,519,514,227,800,000.000 |  | 31,301,329,546,161,100,000.000
 |  |  |  | 21 | 44,318,759,757,113,900,000.000 |  | 15,650,664,773,080,500,000.000
 |  |  |  | 22 | 22,159,379,878,556,900,000.000 |  | 7,825,332,386,540,270,000.000
 |  |  |  | 23 | 11,079,689,939,278,500,000.000 |  | 3,912,666,193,270,130,000.000
 |  |  |  | 24 | 5,539,844,969,639,240,000.000 |  | 1,956,333,096,635,070,000.000
 |  |  |  | 25 | 2,769,922,484,819,620,000.000 |  | 978,166,548,317,533,000.000
 |  |  |  | 26 | 1,384,961,242,409,810,000.000 |  | 489,083,274,158,767,000.000
 |  |  |  | 27 | 692,480,621,204,904,000.000 |  | 244,541,637,079,383,000.000
 |  |  |  | 28 | 346,240,310,602,452,000.000 |  | 122,270,818,539,692,000.000
 |  |  |  | 29 | 173,120,155,301,226,000.000 |  | 61,135,409,269,845,800.000
 |  |  |  | 30 | 86,560,077,650,613,100.000 |  | 30,567,704,634,922,900.000
 |  |  |  | 31 | 43,280,038,825,306,500.000 |  | 15,283,852,317,461,500.000
 |  |  |  | 32 | 21,640,019,412,653,300.000 |  | 7,641,926,158,730,729.000
 |  |  |  | 33 | 10,820,009,706,326,600.000 |  | 3,820,963,079,365,360.000
 |  |  |  | 34 | 5,410,004,853,163,316.000 |  | 1,910,481,539,682,680.000
 |  |  |  | 35 | 2,705,002,426,581,658.000 |  | 955,240,769,841,341.000
 |  |  |  | 36 | 1,352,501,213,290,829.000 |  | 477,620,384,920,671.000
 |  |  |  | 37 | 676,250,606,645,415.000 |  | 238,810,192,460,335.000
 |  |  |  | 38 | 338,125,303,322,707.000 |  | 119,405,096,230,168.000
 |  |  |  | 39 | 169,062,651,661,354.000 |  | 59,702,548,115,083.800
 |  |  |  | 40 | 84,531,325,830,676.800 |  | 29,851,274,057,541.900
 |  |  |  | 41 | 42,265,662,915,338.400 |  | 14,925,637,028,771.000
 |  |  |  | 42 | 21,132,831,457,669.200 |  | 7,462,818,514,385.480
 |  |  |  | 43 | 10,566,415,728,834.600 |  | 3,731,409,257,192.740
 |  |  |  | 44 | 5,283,207,864,417.300 |  | 1,865,704,628,596.370
 |  |  |  | 45 | 2,641,603,932,208.650 |  | 932,852,314,298.185
 |  |  |  | 46 | 1,320,801,966,104.320 |  | 466,426,157,149.092
 |  |  |  | 47 | 660,400,983,052.162 |  | 233,213,078,574.546
 |  |  |  | 48 | 330,200,491,526.081 |  | 116,606,539,287.273
 |  |  |  | 49 | 165,100,245,763.041 |  | 58,303,269,643.637
 |  |  |  | 50 | 82,550,122,881.520 |  | 29,151,634,821.818
 |  |  |  | 51 | 41,275,061,440.760 |  | 14,575,817,410.909
 |  |  |  | 52 | 20,637,530,720.380 |  | 7,287,908,705.455
 |  |  |  | 53 | 10,318,765,360.190 |  | 3,643,954,352.727
 |  |  |  | 54 | 5,159,382,680.095 |  | 1,821,977,176.364
 |  |  |  | 55 | 2,579,691,340.048 |  | 910,988,588.182
 |  |  |  | 56 | 1,289,845,670.024 |  | 455,494,294.091
 |  |  |  | 57 | 644,922,835.012 |  | 227,747,147.045
 |  |  |  | 58 | 322,461,417.506 |  | 113,873,573.523
 |  |  |  | 59 | 161,230,708.753 |  | 56,936,786.761
 |  |  |  | 60 | 80,615,354.376 |  | 28,468,393.381
 |  |  |  | 61 | 40,307,677.188 |  | 14,234,196.690
 |  |  |  | 62 | 20,153,838.594 |  | 7,117,098.345
 |  |  |  | 63 | 10,076,919.297 |  | 3,558,549.173
 |  |  |  | 64 | 5,038,459.649 |  | 1,779,274.586
 |  |  |  | 65 | 2,519,229.824 |  | 889,637.293
 |  |  |  | 66 | 1,259,614.912 |  | 444,818.647
 |  |  |  | 67 | 629,807.456 |  | 222,409.323
 |  |  |  | 68 | 314,903.728 |  | 111,204.662
 |  |  |  | 69 | 157,451.864 |  | 55,602.331
 |  |  |  | 70 | 78,725.932008 | Hz | 27,801.165410 | Hz
 |  |  |  | 71 | 39,362.966 |  | 13,900.583
 |  |  |  | 72 | 19,681.483 |  | 6,950.291
 |  |  |  | 73 | 9,840.742 |  | 3,475.146
 |  |  |  | 74 | 4,920.371 |  | 1,737.573
 |  |  |  | 75 | 2,460.185 |  | 868.786
 |  |  |  | 76 | 1,230.093 |  | 434.393
 |  |  |  | 77 | 615.046343 | Hz | 217.196600 | Hz
 |  |  |  | 78 | 307.523 |  | 108.598
 |  |  |  | 79 | 153.762 |  | 54.299
 |  |  |  | 80 | 76.881 |  | 27.150
 |  |  |  | 81 | 38.440 |  | 13.575
 |  |  |  | 82 | 19.220 |  | 6.787
 |  |  |  | 83 | 9.610 |  | 3.394
 |  |  |  | 84 | 4.805 |  | 1.697
 |  |  |  | 85 | 2.403 |  | 0.848
 |  |  |  | 86 | 1.201 |  | 0.424
 |  |  |  | 87 | 0.601 |  | 0.212
 |  |  |  |  | Remote Mode |  | Contact Mode

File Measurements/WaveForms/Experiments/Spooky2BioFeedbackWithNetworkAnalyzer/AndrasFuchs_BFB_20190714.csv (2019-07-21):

Frequency (Hz) | Channel 1 Magnitude (X)
41000 | 0.9093570267959536
41175.9 | 0.909732158270729
41351.8 | 0.9098236179531836
41527.7 | 0.9095900324994128
41703.6 | 0.9097897429876993
41879.5 | 0.9093921829554481
42055.4 | 0.9085742407360946
42231.3 | 0.9090931361637102
42407.2 | 0.9096566758799609
42583.1 | 0.9095322484242006
42759 | 0.9094825323104266
42934.9 | 0.9094767387526024
43110.8 | 0.9095624389416028
43286.7 | 0.9086582583484644
43462.6 | 0.9095626714949256
43638.5 | 0.9099354471126662
43814.4 | 0.9096236590669655
43990.3 | 0.9093271694732938
44166.2 | 0.9091924879838933
44342.1 | 0.9101552842038979
44518 | 0.9101776411684406
44693.9 | 0.9101169138309301
44869.8 | 0.9100997535247651
45045.7 | 0.9105672718490956
45221.6 | 0.9101246767376912
45397.5 | 0.9093027780635518
45573.4 | 0.9098292816734708
45749.3 | 0.9103983824829385
45925.2 | 0.910476234353504
46101.1 | 0.9103682698603041
46277 | 0.9102829479701167
46452.9 | 0.9103604048953768
46628.8 | 0.9096638114455899
46804.7 | 0.9088950362454847
46980.6 | 0.9104261668270868
47156.5 | 0.9103902029875429
47332.4 | 0.9104506729964232
47508.3 | 0.9106760719917129
47684.2 | 0.9103738980647835
47860.1 | 0.9102911845686685
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

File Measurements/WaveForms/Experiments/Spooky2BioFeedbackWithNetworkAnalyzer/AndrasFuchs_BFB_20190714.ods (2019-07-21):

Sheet: AndrasFuchs_BFB_20190714
Frequency (Hz) | Channel 1 Magnitude (X)
41000 | 0.909357026795954
41175.9 | 0.909732158270729
41351.8 | 0.909823617953184
41527.7 | 0.909590032499413
41703.6 | 0.909789742987699
41879.5 | 0.909392182955448
42055.4 | 0.908574240736095
42231.3 | 0.90909313616371
42407.2 | 0.909656675879961
42583.1 | 0.9095322484242
42759 | 0.909482532310427
42934.9 | 0.909476738752602
43110.8 | 0.909562438941603
43286.7 | 0.908658258348464
43462.6 | 0.909562671494926
43638.5 | 0.909935447112666
43814.4 | 0.909623659066966
43990.3 | 0.909327169473294
44166.2 | 0.909192487983893
44342.1 | 0.910155284203898
44518 | 0.910177641168441
44693.9 | 0.91011691383093
44869.8 | 0.910099753524765
45045.7 | 0.910567271849096
45221.6 | 0.910124676737691
45397.5 | 0.909302778063552
45573.4 | 0.909829281673471
45749.3 | 0.910398382482938
45925.2 | 0.910476234353504
46101.1 | 0.910368269860304
46277 | 0.910282947970117
46452.9 | 0.910360404895377
46628.8 | 0.90966381144559
46804.7 | 0.908895036245485
46980.6 | 0.910426166827087
47156.5 | 0.910390202987543
47332.4 | 0.910450672996423
47508.3 | 0.910676071991713
47684.2 | 0.910373898064784
47860.1 | 0.910291184568668
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

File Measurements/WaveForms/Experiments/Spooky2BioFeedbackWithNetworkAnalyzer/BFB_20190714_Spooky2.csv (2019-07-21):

Date_Time | Frequency | BPM | HRV | Angle | Current | Angle + Current | Spare | Spare | Spare | Spare | Spare
20190714_2035_00 | 41000 | 0 | 0 | 0 | 363.742810718381 | 363.742810718381 | 0 | 0 | 0 | 0 | 0
20190714_2035_00 | 41175.9 | 0 | 0 | 0 | 363.892863308292 | 363.892863308292 | 0 | 0 | 0 | 0 | 0
20190714_2035_00 | 41351.8 | 0 | 0 | 0 | 363.929447181273 | 363.929447181273 | 0 | 0 | 0 | 0 | 0
20190714_2035_00 | 41527.7 | 0 | 0 | 0 | 363.836012999765 | 363.836012999765 | 0 | 0 | 0 | 0 | 0
20190714_2035_00 | 41703.6 | 0 | 0 | 0 | 363.91589719508 | 363.91589719508 | 0 | 0 | 0 | 0 | 0
20190714_2035_00 | 41879.5 | 0 | 0 | 0 | 363.756873182179 | 363.756873182179 | 0 | 0 | 0 | 0 | 0
20190714_2035_00 | 42055.4 | 0 | 0 | 0 | 363.429696294438 | 363.429696294438 | 0 | 0 | 0 | 0 | 0
20190714_2035_00 | 42231.3 | 0 | 0 | 0 | 363.637254465484 | 363.637254465484 | 0 | 0 | 0 | 0 | 0
20190714_2035_00 | 42407.2 | 0 | 0 | 0 | 363.862670351984 | 363.862670351984 | 0 | 0 | 0 | 0 | 0
20190714_2035_00 | 42583.1 | 0 | 0 | 0 | 363.81289936968 | 363.81289936968 | 0 | 0 | 0 | 0 | 0
20190714_2035_00 | 42759 | 0 | 0 | 0 | 363.793012924171 | 363.793012924171 | 0 | 0 | 0 | 0 | 0
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

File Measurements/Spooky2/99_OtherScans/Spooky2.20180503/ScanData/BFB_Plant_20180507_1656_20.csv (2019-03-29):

Date_Time | Frequency | BPM | HRV | Angle | Current | Angle + Current | Spare | Spare | Spare | Spare | Spare
20180507_1656_31 | 41000 | 0 | 0 | 96.13 | 498.13 | 594.26 | 0 | 0 | 0 | 0 | 0
20180507_1656_31 | 41051.25 | 0 | 0 | 96.13 | 498.13 | 594.26 | 0 | 0 | 0 | 0 | 0
20180507_1656_31 | 41102.56 | 0 | 0 | 96.13 | 498.2 | 594.33 | 0 | 0 | 0 | 0 | 0
20180507_1656_31 | 41153.94 | 0 | 0 | 95.52 | 498.2 | 593.72 | 0 | 0 | 0 | 0 | 0
20180507_1656_31 | 41205.38 | 0 | 0 | 95.52 | 498.48 | 594 | 0 | 0 | 0 | 0 | 0
20180507_1656_31 | 41256.89 | 0 | 0 | 95.5 | 498.48 | 593.98 | 0 | 0 | 0 | 0 | 0
20180507_1656_31 | 41308.46 | 0 | 0 | 95.5 | 498.48 | 593.98 | 0 | 0 | 0 | 0 | 0
20180507_1656_31 | 41360.1 | 0 | 0 | 95.5 | 498.83 | 594.33 | 0 | 0 | 0 | 0 | 0
20180507_1656_32 | 41411.8 | 0 | 0 | 94.89 | 498.83 | 593.72 | 0 | 0 | 0 | 0 | 0
20180507_1656_32 | 41463.56 | 0 | 0 | 94.89 | 498.83 | 593.72 | 0 | 0 | 0 | 0 | 0
20180507_1656_32 | 41515.39 | 0 | 0 | 94.89 | 498.84 | 593.73 | 0 | 0 | 0 | 0 | 0
20180507_1656_32 | 41567.28 | 0 | 0 | 94.89 | 498.84 | 593.73 | 0 | 0 | 0 | 0 | 0
20180507_1656_32 | 41619.24 | 0 | 0 | 94.89 | 498.9 | 593.79 | 0 | 0 | 0 | 0 | 0
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

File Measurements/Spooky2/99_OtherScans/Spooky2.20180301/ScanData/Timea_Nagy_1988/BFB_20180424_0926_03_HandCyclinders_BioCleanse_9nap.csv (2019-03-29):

Date_Time | Frequency | BPM | HRV | Angle | Current | Angle + Current | Spare | Spare | Spare | Spare | Spare
20180424_0926_11 | 20000 | 0 | 0 | 81.05 | 504.02 | 585.07 | 0 | 0 | 0 | 0 | 0
20180424_0926_11 | 20025 | 0 | 0 | 81.06 | 504.63 | 585.69 | 0 | 0 | 0 | 0 | 0
20180424_0926_11 | 20050.03125 | 0 | 0 | 81.06 | 504.63 | 585.69 | 0 | 0 | 0 | 0 | 0
20180424_0926_12 | 20075.09379 | 0 | 0 | 81.06 | 505.06 | 586.12 | 0 | 0 | 0 | 0 | 0
20180424_0926_12 | 20100.18766 | 0 | 0 | 81.03 | 505.06 | 586.09 | 0 | 0 | 0 | 0 | 0
20180424_0926_12 | 20125.31289 | 0 | 0 | 81.03 | 505.71 | 586.74 | 0 | 0 | 0 | 0 | 0
20180424_0926_12 | 20150.46953 | 0 | 0 | 80.97 | 505.71 | 586.68 | 0 | 0 | 0 | 0 | 0
20180424_0926_12 | 20175.65762 | 0 | 0 | 80.97 | 505.71 | 586.68 | 0 | 0 | 0 | 0 | 0
20180424_0926_12 | 20200.87719 | 0 | 0 | 80.97 | 506.28 | 587.25 | 0 | 0 | 0 | 0 | 0
20180424_0926_12 | 20226.12829 | 0 | 0 | 80.63 | 506.28 | 586.91 | 0 | 0 | 0 | 0 | 0
20180424_0926_12 | 20251.41095 | 0 | 0 | 80.63 | 506.86 | 587.49 | 0 | 0 | 0 | 0 | 0
20180424_0926_12 | 20276.72521 | 0 | 0 | 80.48 | 506.86 | 587.34 | 0 | 0 | 0 | 0 | 0
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

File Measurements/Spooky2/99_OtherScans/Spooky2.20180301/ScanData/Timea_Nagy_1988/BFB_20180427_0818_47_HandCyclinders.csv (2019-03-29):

Date_Time | Frequency | BPM | HRV | Angle | Current | Angle + Current | Spare | Spare | Spare | Spare | Spare
20180427_0819_12 | 41000 | 0 | 0 | 102.01 | 511.34 | 613.35 | 0 | 0 | 0 | 0 | 0
20180427_0819_12 | 41051.25 | 0 | 0 | 102.01 | 511.34 | 613.35 | 0 | 0 | 0 | 0 | 0
20180427_0819_12 | 41102.56 | 0 | 0 | 102.01 | 511.35 | 613.36 | 0 | 0 | 0 | 0 | 0
20180427_0819_12 | 41153.94 | 0 | 0 | 101.92 | 511.35 | 613.27 | 0 | 0 | 0 | 0 | 0
20180427_0819_12 | 41205.38 | 0 | 0 | 101.92 | 511.35 | 613.27 | 0 | 0 | 0 | 0 | 0
20180427_0819_12 | 41256.89 | 0 | 0 | 101.92 | 511.34 | 613.26 | 0 | 0 | 0 | 0 | 0
20180427_0819_12 | 41308.46 | 0 | 0 | 101.43 | 511.34 | 612.77 | 0 | 0 | 0 | 0 | 0
20180427_0819_12 | 41360.1 | 0 | 0 | 101.43 | 511.34 | 612.77 | 0 | 0 | 0 | 0 | 0
20180427_0819_12 | 41411.8 | 0 | 0 | 101.39 | 511.34 | 612.73 | 0 | 0 | 0 | 0 | 0
20180427_0819_12 | 41463.56 | 0 | 0 | 101.39 | 511.34 | 612.73 | 0 | 0 | 0 | 0 | 0
20180427_0819_13 | 41515.39 | 0 | 0 | 101.39 | 511.34 | 612.73 | 0 | 0 | 0 | 0 | 0
20180427_0819_13 | 41567.28 | 0 | 0 | 101.39 | 511.33 | 612.72 | 0 | 0 | 0 | 0 | 0
20180427_0819_13 | 41619.24 | 0 | 0 | 101.39 | 511.33 | 612.72 | 0 | 0 | 0 | 0 | 0
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

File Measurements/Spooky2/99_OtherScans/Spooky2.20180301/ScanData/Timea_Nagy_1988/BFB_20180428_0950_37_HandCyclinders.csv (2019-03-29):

Date_Time | Frequency | BPM | HRV | Angle | Current | Angle + Current | Spare | Spare | Spare | Spare | Spare
20180428_0950_51 | 41000 | 0 | 0 | 101.13 | 511.28 | 612.41 | 0 | 0 | 0 | 0 | 0
20180428_0950_51 | 41051.25 | 0 | 0 | 101.13 | 511.25 | 612.38 | 0 | 0 | 0 | 0 | 0
20180428_0950_51 | 41102.56 | 0 | 0 | 101.12 | 511.25 | 612.37 | 0 | 0 | 0 | 0 | 0
20180428_0950_52 | 41153.94 | 0 | 0 | 101.12 | 511.25 | 612.37 | 0 | 0 | 0 | 0 | 0
20180428_0950_52 | 41205.38 | 0 | 0 | 100.85 | 511.25 | 612.1 | 0 | 0 | 0 | 0 | 0
20180428_0950_52 | 41256.89 | 0 | 0 | 100.85 | 511.25 | 612.1 | 0 | 0 | 0 | 0 | 0
20180428_0950_52 | 41308.46 | 0 | 0 | 100.85 | 511.29 | 612.14 | 0 | 0 | 0 | 0 | 0
20180428_0950_52 | 41360.1 | 0 | 0 | 100.85 | 511.29 | 612.14 | 0 | 0 | 0 | 0 | 0
20180428_0950_52 | 41411.8 | 0 | 0 | 100.54 | 511.29 | 611.83 | 0 | 0 | 0 | 0 | 0
20180428_0950_52 | 41463.56 | 0 | 0 | 100.54 | 511.34 | 611.88 | 0 | 0 | 0 | 0 | 0
20180428_0950_52 | 41515.39 | 0 | 0 | 100.49 | 511.34 | 611.83 | 0 | 0 | 0 | 0 | 0
20180428_0950_52 | 41567.28 | 0 | 0 | 100.49 | 511.34 | 611.83 | 0 | 0 | 0 | 0 | 0
20180428_0950_52 | 41619.24 | 0 | 0 | 100.49 | 511.41 | 611.9 | 0 | 0 | 0 | 0 | 0
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

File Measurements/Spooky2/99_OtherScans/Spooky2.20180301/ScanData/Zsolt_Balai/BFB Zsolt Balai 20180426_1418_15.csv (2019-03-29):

Date_Time | Frequency | BPM | HRV | Angle | Current | Angle + Current | Spare | Spare | Spare | Spare | Spare
20180426_1418_39 | 41000 | 0 | 0 | 87.86 | 537.97 | 625.83 | 0 | 0 | 0 | 0 | 0
20180426_1418_39 | 41051.25 | 0 | 0 | 87.86 | 537.97 | 625.83 | 0 | 0 | 0 | 0 | 0
20180426_1418_39 | 41102.56 | 0 | 0 | 87.86 | 537.97 | 625.83 | 0 | 0 | 0 | 0 | 0
20180426_1418_39 | 41153.94 | 0 | 0 | 87.86 | 537.97 | 625.83 | 0 | 0 | 0 | 0 | 0
20180426_1418_39 | 41205.38 | 0 | 0 | 87.8 | 537.97 | 625.77 | 0 | 0 | 0 | 0 | 0
20180426_1418_39 | 41256.89 | 0 | 0 | 87.8 | 537.95 | 625.75 | 0 | 0 | 0 | 0 | 0
20180426_1418_39 | 41308.46 | 0 | 0 | 87.8 | 537.95 | 625.75 | 0 | 0 | 0 | 0 | 0
20180426_1418_39 | 41360.1 | 0 | 0 | 87.77 | 537.95 | 625.72 | 0 | 0 | 0 | 0 | 0
20180426_1418_39 | 41411.8 | 0 | 0 | 87.77 | 537.95 | 625.72 | 0 | 0 | 0 | 0 | 0
20180426_1418_40 | 41463.56 | 0 | 0 | 87.77 | 537.95 | 625.72 | 0 | 0 | 0 | 0 | 0
20180426_1418_40 | 41515.39 | 0 | 0 | 87.75 | 537.95 | 625.7 | 0 | 0 | 0 | 0 | 0
20180426_1418_40 | 41567.28 | 0 | 0 | 87.75 | 537.98 | 625.73 | 0 | 0 | 0 | 0 | 0
20180426_1418_40 | 41619.24 | 0 | 0 | 87.73 | 537.98 | 625.71 | 0 | 0 | 0 | 0 | 0
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

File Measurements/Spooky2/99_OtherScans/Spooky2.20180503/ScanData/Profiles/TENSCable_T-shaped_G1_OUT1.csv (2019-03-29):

Frequency | Min_Angle | Avg_Angle | Max_Angle | Min_Current | Avg_Current | Max_Current
1.00000 | -41.44 | 8.80 | 55.58 | 13.04 | 13.16 | 13.44
1.00125 | -41.44 | 19.23 | 55.58 | 13.16 | 13.47 | 13.80
1.00250 | -32.43 | 1.30 | 44.55 | 13.14 | 13.55 | 13.88
1.00375 | -39.09 | -9.42 | 31.00 | 13.22 | 13.75 | 13.96
1.00500 | -33.84 | -15.58 | 9.83 | 13.02 | 13.32 | 13.69
1.00626 | -18.79 | 19.51 | 68.90 | 13.07 | 13.37 | 13.65
1.00752 | -21.42 | 14.11 | 68.90 | 13.40 | 13.57 | 13.70
1.00878 | -28.91 | -5.95 | 37.94 | 12.85 | 13.27 | 13.62
1.01004 | -31.73 | 8.04 | 61.80 | 12.95 | 13.30 | 13.72
1.01130 | -34.09 | 8.22 | 54.44 | 13.07 | 13.45 | 13.76
1.01256 | -52.20 | -18.99 | 37.79 | 13.07 | 13.45 | 13.76
1.01383 | -52.20 | -28.38 | 37.79 | 13.07 | 13.56 | 13.76
1.01510 | -41.78 | -26.07 | -1.47 | 13.04 | 13.50 | 13.78
1.01637 | -70.13 | -30.58 | 8.55 | 13.04 | 13.40 | 13.78
1.01764 | -67.50 | -26.85 | 10.59 | 13.09 | 13.47 | 13.77
1.01891 | -30.47 | -2.01 | 49.71 | 13.13 | 13.64 | 13.81
1.02018 | -30.77 | -11.59 | 49.71 | 13.63 | 13.72 | 13.80
1.02146 | -46.11 | -18.51 | 34.37 | 13.11 | 13.46 | 13.74
1.02274 | -48.77 | -16.09 | 45.28 | 13.10 | 13.34 | 13.72
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

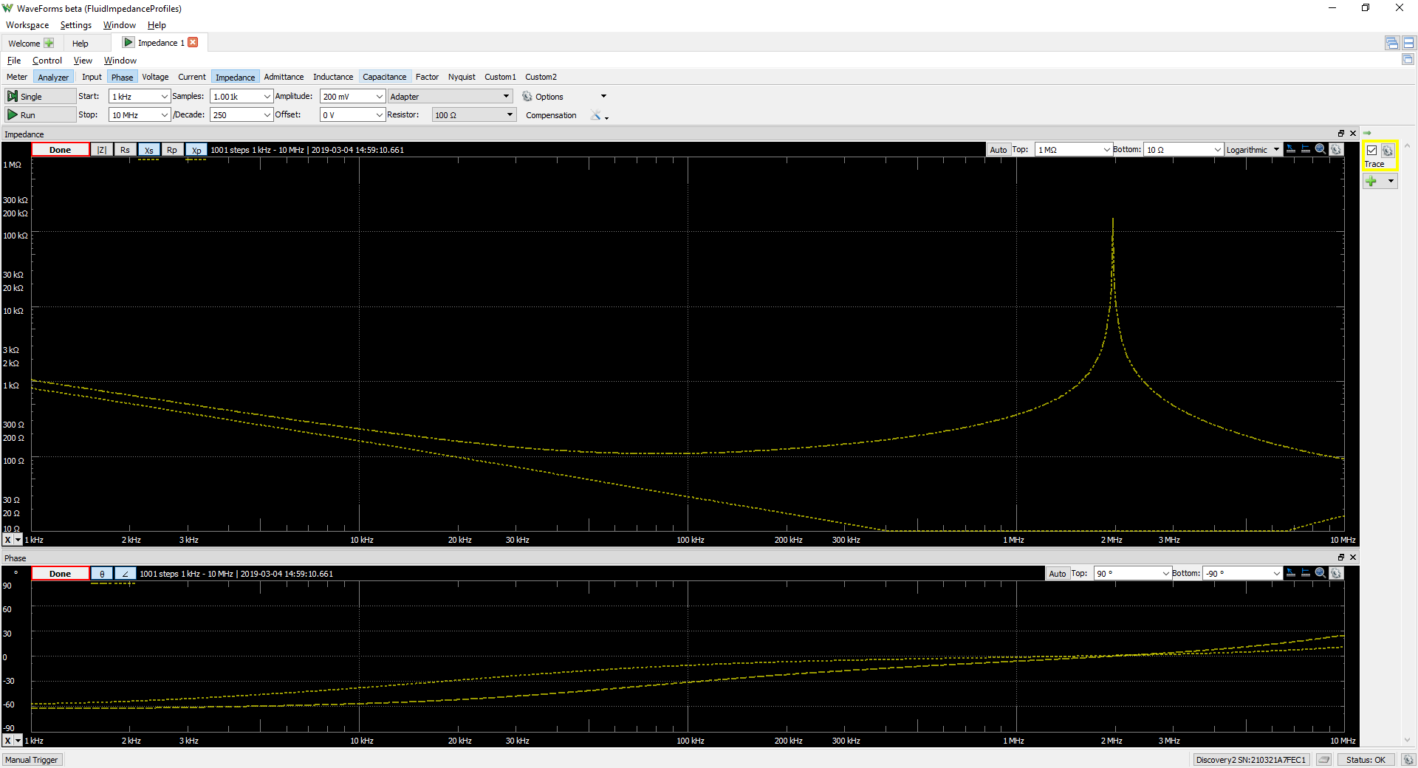
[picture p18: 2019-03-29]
Measurements/WaveForms/Experiments/FluidImpedanceProfiles/ConsistencyTest/FluidImpedanceProfiles_20190304_CarbonFilteredSaltyWater_R0100_A.png

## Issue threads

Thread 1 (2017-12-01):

ADC range in very limited

andrasfuchs, 2017-12-01:
ADC sample rate can be changed in the [settings struct's constructor](https://github.com/andrasfuchs/BioBalanceDetector/blob/master/Software/Source/BBDProto05/Mercury/Mercury-16/src/settings.c).
The firmware should be able to handle sample rates between 1kSPS and 2000kSPS.

Now, if we set it to 1kSPS the responsiveness is very low, and the driver can catch only 250 SPS, and if its 100kSPS the LCD menu on the device becomes terribly slow.

andrasfuchs, 2017-12-01:
The low sample rate bug was fixed. The main reason was that the driver didn't recognized many packets, because the packet length was set incorrectly by the firmware.

andrasfuchs, 2017-12-01:
With the current double buffering 4000 SPS, 32-bit/sample speed seems to be the hard limit because of the bandwidth limitation.
The recommended strategy would be to use 1000 SPS by default when not doing Goertzel, and switch the sampling rate dynamically when we do. The dynamic rate should be always at least 4 times the highest Goertzel frequency.
The current settings is that we have 128 samples per channel per buffer, so the difference between the highest and the lowest Goertzel frequency can be 32-fold the most.

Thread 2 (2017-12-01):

Goertzel algorithm doesn't work

andrasfuchs, 2017-12-01:
There is a setting in the settings struct to switch on Goertzel algorithm on every sensor in a cell. This feature should be used if the sampling rate if higher than 1kSPS.

In that case the data forwarded to the USB should be only the Goertzel values at a rate of 100 values/channel/seconds. A special data frame with APDU.Choice == 0xF008 should be used to transfer the data.

Currently the setting doesn't do anything.

andrasfuchs, 2017-12-01:
Added Goertzel support for the firmware https://github.com/andrasfuchs/BioBalanceDetector/commit/c4c24fb44d1cdc941e59899d6ee4ef96a2f217df

Closed 2017-12-01.

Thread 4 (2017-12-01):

USB device is not recognized

andrasfuchs, 2017-12-01:
Sometimes I get the "USB device is not recognized" on Windows. I get the error more often if I try to use higher ADC frequency.

Closed 2022-05-30.

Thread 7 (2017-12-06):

Switch data rendering modes on the fly

andrasfuchs, 2017-12-06:
Every time we need a different view of the data received from Mercury-16 we need to recompile the driver. It would be great to be able to switch those display modes while running the driver.

andrasfuchs, 2017-12-06:
https://github.com/andrasfuchs/BioBalanceDetector/commit/0c2eab672ce02fb9e24c577862dfbfd89ee527b1

Closed 2017-12-06.

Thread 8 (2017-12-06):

Set new settings from the driver

andrasfuchs, 2017-12-06:
It would be great to change the ADC's sample rate, the packet types and all the other properties of the Mercury-16 from the driver on the fly.

andrasfuchs, 2017-12-06:
Settings are successfully changed at the driver and sent it back to Mercury-16, they are just not applied yet.

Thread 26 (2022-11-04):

Balance feature based on its statistical dispersion

andrasfuchs, 2022-11-04:
Now that we have float feature values (based on sleep stage or blood samples) we would need to filter ML model training inputs based on the total [statistical dispersion](https://en.wikipedia.org/wiki/Statistical_dispersion) of the dataset.

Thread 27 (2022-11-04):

Store inputAmplification in the session file and add overflow protection when saving .wav files

andrasfuchs, 2022-11-04:
We have now a fixed +/- 1 Volt range defined for the .WAV files. This is normally fine, but we should have an extra protection for higher values. This could be done by storing and adopting the `inputAmplification` value, because that is the multiplier we use when we convert the measured values from floating point to (16-bit) integers.

We could store its current value as a dedicated `SegmentedData` chunk in the session file.

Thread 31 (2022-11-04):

Retire this repo and create new ones within BioBalanceDetector organization

andrasfuchs, 2022-11-04:
This repo contains all the previous prototypes, documentation, research papers and many other things that are not currently relevant for Body Monitor.

I would prefer to move this repo into an organization, and have separate repos for Body Monitor.
We should probably have at least 4 repos:
 * Source code related to older prototypes
 * Management, design, documentation, etc.
 * Body Monitor library, API, GUI, CLI
 * Metadata, some sample data for ML training and trained models

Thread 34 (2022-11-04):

Keep the .WAV file running if the data loss is neglegable

andrasfuchs, 2022-11-04:
During an 7-hour long session it's not atypical that we have ~80 session breaks because of small packet losses.

If the data loss is tiny we should fill up the missing data with zeros and keep the .WAV file running, it would make the management of sessions easier.

Alternatively we should keep track of the newly started .WAV files every time a packet loss occurs and record them into the session's `SegmentedData` section.

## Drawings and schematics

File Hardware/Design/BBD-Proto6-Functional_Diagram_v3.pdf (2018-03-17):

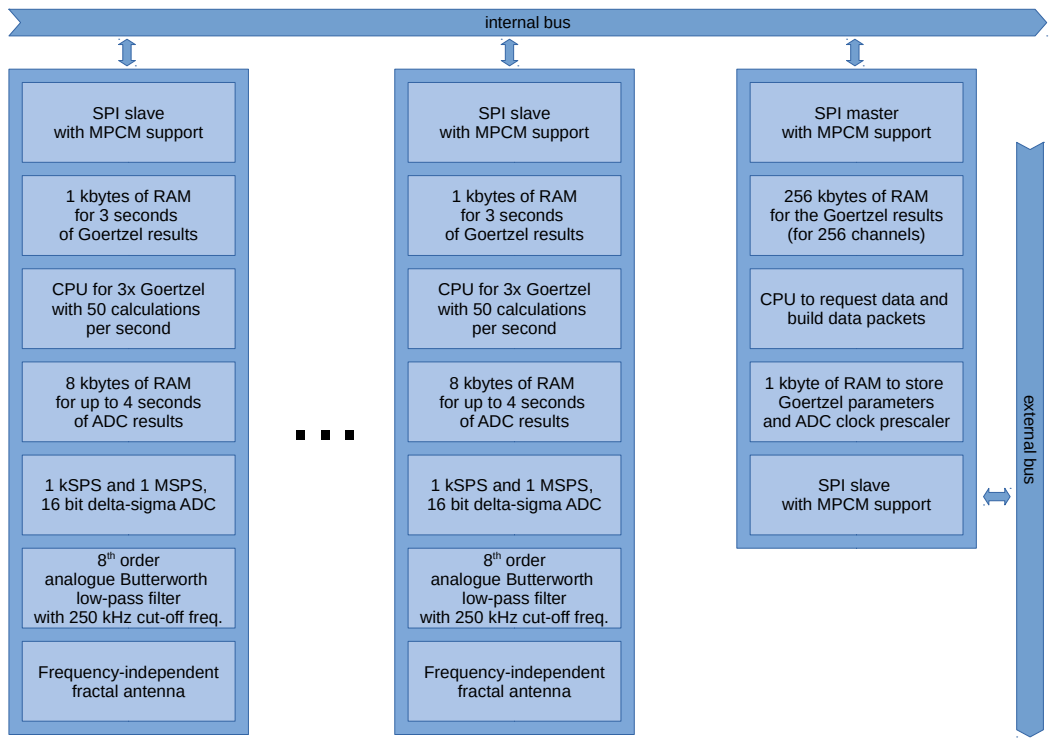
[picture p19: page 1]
Frequency-independent fractal antenna; internal bus

SPI slave
with MPCM support

SPI master

1 kbytes of RAM
for 3 seconds
of Goertzel results

256 kbytes of RAM
for the Goertzel results
(for 256 channels)

CPU for 3x Goertzel
with 50 calculations
per second

CPU to request data and
build data packets

8 kbytes of RAM
for up to 4 seconds
of ADC results

1 kbyte of RAM to store
Goertzel parameters
and ADC clock prescaler

1 kSPS and 1 MSPS,
16 bit delta-sigma ADC

th order
analogue Butterworth
low-pass filter
with 250 kHz cut-off freq.

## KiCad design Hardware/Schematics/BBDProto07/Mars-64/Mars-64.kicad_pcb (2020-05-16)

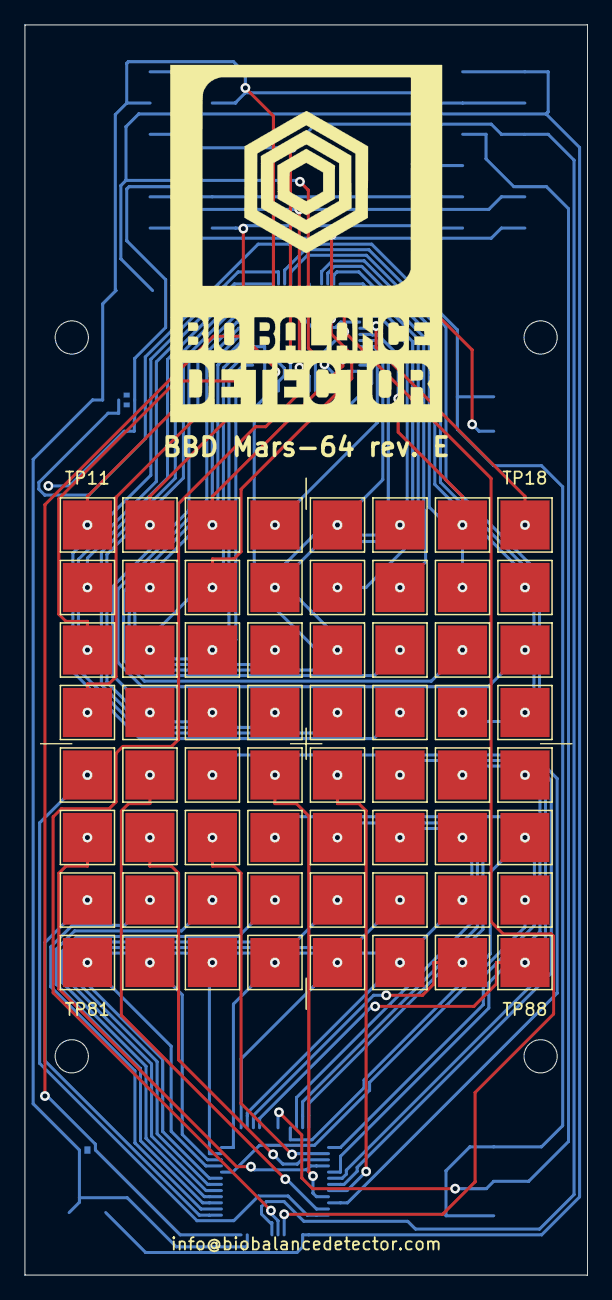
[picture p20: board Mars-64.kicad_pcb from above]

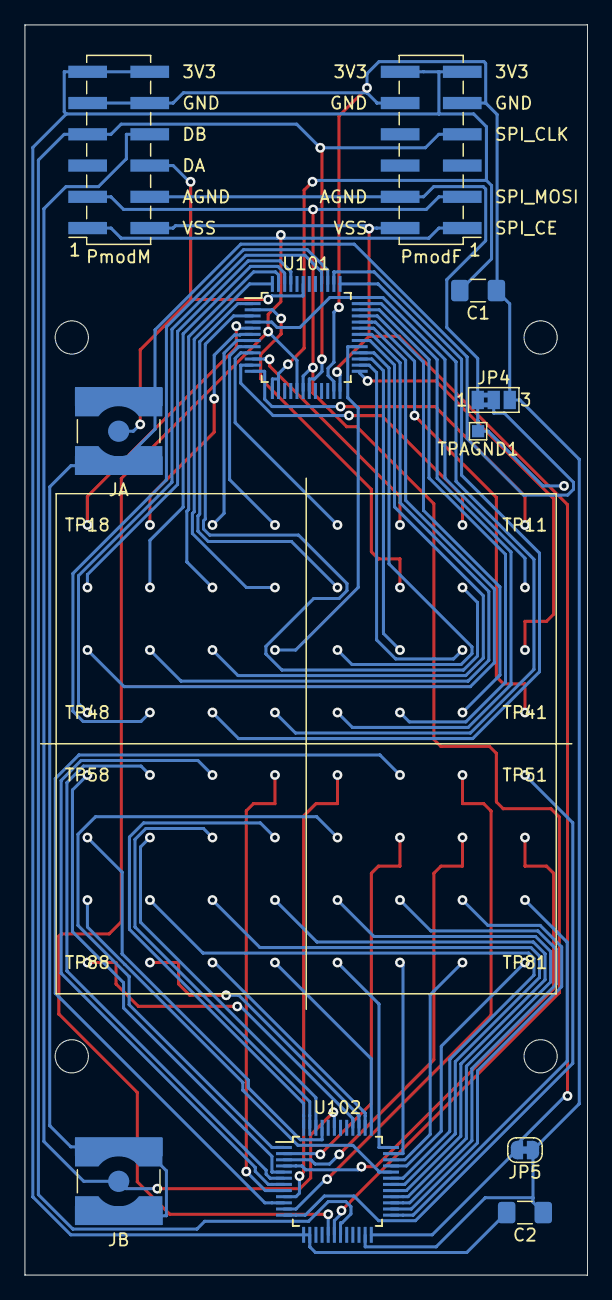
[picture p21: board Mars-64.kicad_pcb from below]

Board: 4 copper layers, 45.7 x 101.6 mm, 79 parts (11 on the bottom side), 74 nets.

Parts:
C1, C2: 100 nF; C_1206_3216Metric_Pad1.42x1.75mm_HandSolder
H1, H2, H3, H4: MountingHole; MountingHole_2.7mm_M2.5
JA: Conn_Coaxial; SMA_Amphenol_132134-10_Vertical
JB: Conn_Coaxial; SMA_Amphenol_132134-10_Vertical
JP4: Jumper_NC_Dual; SolderJumper-3_P1.3mm_Bridged2Bar12_Pad1.0x1.5mm_NumberLabe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
JP5: SolderJumper_2_Bridged; SolderJumper-2_P1.3mm_Bridged_RoundedPad1.0x1.5mm
PmodF: Conn_02x06_Top_Bottom; PinHeader_2x06_P2.54mm_Vertical_SMD_TopBottom
PmodM: Conn_02x06_Top_Bottom; PinHeader_2x06_P2.54mm_Vertical_SMD_TopBottom_Mirrored
TP101, TP102, TP103, TP104, TP105, TP106, TP107, TP108, TP109, TP110, TP111, TP112, TP113, TP114, TP115, TP116, TP117, TP118, TP119, TP120, TP121, TP122, TP123, TP124, TP125, TP126, TP127, TP128, TP129, TP130, TP131, TP132, TP201, TP202, TP203, TP204, TP205, TP206, TP207, TP208, TP209, TP210, TP211, TP212, TP213, TP214, TP215, TP216, TP217, TP218, TP219, TP220, TP221, TP222, TP223, TP224, TP225, TP226, TP227, TP228, TP229, TP230, TP231, TP232: TestPoint_Small; TestPoint_Pad_4.0x4.0mm
TPAGND1: TestPoint_Small; TestPoint_Pad_1.0x1.0mm
U101, U102: ADG731; TQFP-48_7x7mm_P0.5mm

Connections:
/AGND: JP4.1, PmodF.8, PmodM.8, TPAGND1.1
/DA: JA.1, PmodM.9, U101.43
/DB: JB.1, PmodM.10, U102.43
/SPI_CLK: PmodF.4, PmodM.4, U101.19, U102.19
/SPI_MOSI: PmodF.2, PmodM.2, U101.18, U102.18
/VCC3V3: C1.2, C2.2, PmodF.6, PmodF.12, PmodM.6, PmodM.12, U101.13, U101.14, U102.13, U102.14
/VSS: JP5.2, PmodF.7, PmodM.7, U101.24, U102.24
/~SPI_CE: PmodF.1, PmodM.1, U101.17, U102.17
GND: C1.1, C2.1, JP4.3, JP5.1, PmodF.5, PmodF.11, PmodM.5, PmodM.11, U101.23, U102.23
unnamed: JA.2, JB.2, JP4.2
unnamed: TP101.1, U101.12
unnamed: TP102.1, U101.11
unnamed: TP103.1, U101.10
unnamed: TP104.1, U101.9
unnamed: TP105.1, U101.8
unnamed: TP106.1, U101.7
unnamed: TP107.1, U101.6
unnamed: TP108.1, U101.5
unnamed: TP109.1, U101.4
unnamed: TP110.1, U101.3
unnamed: TP111.1, U101.2
unnamed: TP112.1, U101.1
unnamed: TP113.1, U101.48
unnamed: TP114.1, U101.47
unnamed: TP115.1, U101.46
unnamed: TP116.1, U101.45
unnamed: TP117.1, U101.25
unnamed: TP118.1, U101.26
unnamed: TP119.1, U101.27
unnamed: TP120.1, U101.28
unnamed: TP121.1, U101.29
unnamed: TP122.1, U101.30
unnamed: TP123.1, U101.31
unnamed: TP124.1, U101.32
unnamed: TP125.1, U101.33
unnamed: TP126.1, U101.34
unnamed: TP127.1, U101.35
unnamed: TP128.1, U101.36
unnamed: TP129.1, U101.37
unnamed: TP130.1, U101.38
unnamed: TP131.1, U101.39
unnamed: TP132.1, U101.40
unnamed: TP201.1, U102.12
unnamed: TP202.1, U102.11
unnamed: TP203.1, U102.10
unnamed: TP204.1, U102.9
unnamed: TP205.1, U102.8
unnamed: TP206.1, U102.7
unnamed: TP207.1, U102.6
unnamed: TP208.1, U102.5
unnamed: TP209.1, U102.4
unnamed: TP210.1, U102.3
unnamed: TP211.1, U102.2
unnamed: TP212.1, U102.1
unnamed: TP213.1, U102.48
unnamed: TP214.1, U102.47
unnamed: TP215.1, U102.46
unnamed: TP216.1, U102.45
unnamed: TP217.1, U102.25
unnamed: TP218.1, U102.26
unnamed: TP219.1, U102.27
unnamed: TP220.1, U102.28
unnamed: TP221.1, U102.29
unnamed: TP222.1, U102.30
unnamed: TP223.1, U102.31
unnamed: TP224.1, U102.32
unnamed: TP225.1, U102.33
unnamed: TP226.1, U102.34
unnamed: TP227.1, U102.35
unnamed: TP228.1, U102.36
unnamed: TP229.1, U102.37
unnamed: TP230.1, U102.38
unnamed: TP231.1, U102.39
unnamed: TP232.1, U102.40

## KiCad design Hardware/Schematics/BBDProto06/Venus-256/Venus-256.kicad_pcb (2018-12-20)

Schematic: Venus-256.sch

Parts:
JP101: VOUT1_JP; SolderJumper-2_P1.3mm_Bridged2Bar_Pad1.0x1.5mm
JP102: VOUT2_JP; SolderJumper-2_P1.3mm_Bridged2Bar_Pad1.0x1.5mm
TP101: VOUT3_TP; TestPoint_Pad_1.0x1.0mm
TP102: VOUT4_TP; TestPoint_Pad_1.0x1.0mm
U101: TPS22993; Texas_S-PWQFN-N20

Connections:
/CellMaster-01/VCC_MCU_P3V3: JP101.2; also elsewhere on the board
/CellMaster-02/VCC_MCU_P3V3: JP102.2; also elsewhere on the board
/RaspberryPiGPIOHeader/DC_POWER_3V3: U101.2, U101.4, U101.7, U101.8, U101.9, U101.10, U101.12, U101.14, U101.18; also elsewhere on the board
/RaspberryPiGPIOHeader/DC_POWER_5V0: U101.3; also elsewhere on the board
/RaspberryPiGPIOHeader/I2C_SCL1: U101.17; also elsewhere on the board
/RaspberryPiGPIOHeader/I2C_SDA1: U101.19; also elsewhere on the board
GND: U101.6, U101.13, U101.16, U101.20; also elsewhere on the board
unnamed: JP101.1, U101.5
unnamed: JP102.1, U101.1
unnamed: TP101.1, U101.15
unnamed: TP102.1, U101.11

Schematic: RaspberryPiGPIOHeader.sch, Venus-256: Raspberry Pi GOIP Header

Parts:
J201: RaspberryPi header; PinHeader_2x20_P2.54mm_Horizontal

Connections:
/CellMaster-01/SPI0_MISO: J201.21; also elsewhere on the board
/CellMaster-01/SPI0_MOSI: J201.19; also elsewhere on the board
/CellMaster-01/SPI0_SPCK: J201.23; also elsewhere on the board
/RaspberryPiGPIOHeader/DC_POWER_3V3: J201.1, J201.17; also elsewhere on the board
/RaspberryPiGPIOHeader/DC_POWER_5V0: J201.2, J201.4; also elsewhere on the board
/RaspberryPiGPIOHeader/I2C_SCL1: J201.5; also elsewhere on the board
/RaspberryPiGPIOHeader/I2C_SDA1: J201.3; also elsewhere on the board
GND: J201.6, J201.9, J201.14, J201.20, J201.25, J201.30, J201.34, J201.39; also elsewhere on the board

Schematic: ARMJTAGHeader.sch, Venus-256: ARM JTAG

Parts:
J301: ARM JTAG; PinHeader_2x10_P2.54mm_Horizontal
R301, R302, R303, R304: 0R; R_0603_1608Metric_Pad0.84x1.00mm_HandSolder

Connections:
/ARMJTAGHeader/SWCLK: R301.1; also elsewhere on the board
/ARMJTAGHeader/SWDIO: R303.2; also elsewhere on the board
/ARMJTAGHeader/TARGET_RESET: R302.1; also elsewhere on the board
/ARMJTAGHeader/TRACESWO: R304.2; also elsewhere on the board
/RaspberryPiGPIOHeader/DC_POWER_3V3: J301.1, J301.2; also elsewhere on the board
GND: J301.4, J301.6, J301.8, J301.10, J301.12, J301.14, J301.16, J301.18, J301.20; also elsewhere on the board
unnamed: J301.7, R303.1
unnamed: J301.9, R301.2
unnamed: J301.13, R304.1
unnamed: J301.15, R302.2

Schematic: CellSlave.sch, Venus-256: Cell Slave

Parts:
C401, C405, C407, C409, C411, C413, C416: 10uF; C_0603_1608Metric_Pad0.84x1.00mm_HandSolder
C402, C406, C408, C410, C412, C414, C415: 0.1uF; C_0603_1608Metric_Pad0.84x1.00mm_HandSolder
C403: 0.1uF,X8R; C_0603_1608Metric_Pad0.84x1.00mm_HandSolder
C404: 10uF,X5R; C_0603_1608Metric_Pad0.84x1.00mm_HandSolder
TP401: S01; TestPoint_Pad_1.0x1.0mm
TP402: S02; TestPoint_Pad_1.0x1.0mm
TP403: S03; TestPoint_Pad_1.0x1.0mm
TP404: S04; TestPoint_Pad_1.0x1.0mm
TP405: S05; TestPoint_Pad_1.0x1.0mm
TP406: S06; TestPoint_Pad_1.0x1.0mm
TP407: S07; TestPoint_Pad_1.0x1.0mm
TP408: S08; TestPoint_Pad_1.0x1.0mm
TP409: S09; TestPoint_Pad_1.0x1.0mm
TP410: S10; TestPoint_Pad_1.0x1.0mm
TP411: S11; TestPoint_Pad_1.0x1.0mm
TP412: S12; TestPoint_Pad_1.0x1.0mm
TP413: S13; TestPoint_Pad_1.0x1.0mm
TP414: S14; TestPoint_Pad_1.0x1.0mm
TP415: S15; TestPoint_Pad_1.0x1.0mm
TP416: S16; TestPoint_Pad_1.0x1.0mm
TP417: ADC_REF_OUT; TestPoint_Pad_1.0x1.0mm
U401: AD7616; LQFP-80_14x14mm_P0.65mm

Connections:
/CellMaster-01/ADC_BUSY0: U401.67; also elsewhere on the board
/CellMaster-01/ADC_CONVST0: U401.68; also elsewhere on the board
/CellMaster-01/ADC_RESET: U401.36; also elsewhere on the board
/CellMaster-01/DAC0: U401.1, U401.3, U401.8, U401.10, U401.11, U401.13, U401.18, U401.20, U401.21, U401.23, U401.25, U401.27, U401.74, U401.76, U401.78, U401.80; also elsewhere on the board
/CellMaster-01/SPI1_NPCS0: U401.63; also elsewhere on the board
/CellSlave-01A/SCLK: U401.55, U401.62; also elsewhere on the board
/CellSlave-01A/SDOA: U401.57; also elsewhere on the board
/RaspberryPiGPIOHeader/DC_POWER_3V3: C413.2, C414.2, U401.35, U401.40, U401.49; also elsewhere on the board
/RaspberryPiGPIOHeader/DC_POWER_5V0: C405.2, C406.1, C407.2, C408.2, C409.2, C410.2, C411.2, C412.2, U401.6, U401.15, U401.30, U401.71; also elsewhere on the board
GND: C401.2, C402.2, C403.2, C404.2, C405.1, C406.2, C407.1, C408.1, C409.1, C410.1, C411.1, C412.1, C413.1, C414.1, C415.2, C416.2, U401.5, U401.16, U401.29, U401.32, U401.34, U401.37, U401.38, U401.39, U401.41, U401.42, U401.43, U401.44, U401.45, U401.46, U401.47, U401.48, U401.50, U401.51, U401.53, U401.54, U401.58, U401.59, U401.60, U401.61, U401.64, U401.65, U401.66, U401.69, U401.72; also elsewhere on the board
unnamed: C401.1, C402.1, U401.70
unnamed: C403.1, TP417.1, U401.33
unnamed: C404.1, U401.31
unnamed: C415.1, C416.1, U401.52
unnamed: TP401.1, U401.73
unnamed: TP402.1, U401.75
unnamed: TP403.1, U401.77
unnamed: TP404.1, U401.79
unnamed: TP405.1, U401.9
unnamed: TP406.1, U401.7
unnamed: TP407.1, U401.4
unnamed: TP408.1, U401.2
unnamed: TP409.1, U401.19
unnamed: TP410.1, U401.17
unnamed: TP411.1, U401.14
unnamed: TP412.1, U401.12
unnamed: TP413.1, U401.28
unnamed: TP414.1, U401.26
unnamed: TP415.1, U401.24
unnamed: TP416.1, U401.22

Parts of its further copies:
C601, C605, C607, C609, C611, C613, C616, C701, C705, C707, C709, C711, C713, C716, C801, C805, C807, C809, C811, C813, C816, C1001, C1005, C1007, C1009, C1011, C1013, C1016: 10uF; C_0603_1608Metric_Pad0.84x1.00mm_HandSolder
C602, C606, C608, C610, C612, C614, C615, C702, C706, C708, C710, C712, C714, C715, C802, C806, C808, C810, C812, C814, C815, C1002, C1006, C1008, C1010, C1012, C1014, C1015: 0.1uF; C_0603_1608Metric_Pad0.84x1.00mm_HandSolder
C603, C703, C803, C1003: 0.1uF,X8R; C_0603_1608Metric_Pad0.84x1.00mm_HandSolder
C604, C704, C804, C1004: 10uF,X5R; C_0603_1608Metric_Pad0.84x1.00mm_HandSolder
TP601, TP701, TP801, TP1001: S01; TestPoint_Pad_1.0x1.0mm
TP602, TP702, TP802, TP1002: S02; TestPoint_Pad_1.0x1.0mm
TP603, TP703, TP803, TP1003: S03; TestPoint_Pad_1.0x1.0mm
TP604, TP704, TP804, TP1004: S04; TestPoint_Pad_1.0x1.0mm
TP605, TP705, TP805, TP1005: S05; TestPoint_Pad_1.0x1.0mm
TP606, TP706, TP806, TP1006: S06; TestPoint_Pad_1.0x1.0mm
TP607, TP707, TP807, TP1007: S07; TestPoint_Pad_1.0x1.0mm
TP608, TP708, TP808, TP1008: S08; TestPoint_Pad_1.0x1.0mm
TP609, TP709, TP809, TP1009: S09; TestPoint_Pad_1.0x1.0mm
TP610, TP710, TP810, TP1010: S10; TestPoint_Pad_1.0x1.0mm
TP611, TP711, TP811, TP1011: S11; TestPoint_Pad_1.0x1.0mm
TP612, TP712, TP812, TP1012: S12; TestPoint_Pad_1.0x1.0mm
TP613, TP713, TP813, TP1013: S13; TestPoint_Pad_1.0x1.0mm
TP614, TP714, TP814, TP1014: S14; TestPoint_Pad_1.0x1.0mm
TP615, TP715, TP815, TP1015: S15; TestPoint_Pad_1.0x1.0mm
TP616, TP716, TP816, TP1016: S16; TestPoint_Pad_1.0x1.0mm
TP617, TP717, TP817, TP1017: ADC_REF_OUT; TestPoint_Pad_1.0x1.0mm
U601, U701, U801, U1001: AD7616; LQFP-80_14x14mm_P0.65mm

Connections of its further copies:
/CellMaster-01/ADC_BUSY1: U601.67; also elsewhere on the board
/CellMaster-01/ADC_BUSY2: U701.67; also elsewhere on the board
/CellMaster-01/ADC_BUSY3: U801.67; also elsewhere on the board
/CellMaster-01/ADC_CONVST1: U601.68; also elsewhere on the board
/CellMaster-01/ADC_CONVST2: U701.68; also elsewhere on the board
/CellMaster-01/ADC_CONVST3: U801.68; also elsewhere on the board
/CellMaster-01/ADC_RESET: U601.36, U701.36, U801.36; also elsewhere on the board
/CellMaster-01/DAC0: U601.1, U601.3, U601.8, U601.10, U601.11, U601.13, U601.18, U601.20, U601.21, U601.23, U601.25, U601.27, U601.74, U601.76, U601.78, U601.80, U701.1, U701.3, U701.8, U701.10, U701.11, U701.13, U701.18, U701.20, U701.21, U701.23, U701.25, U701.27, U701.74, U701.76, U701.78, U701.80, U801.1, U801.3, U801.8, U801.10, U801.11, U801.13, U801.18, U801.20, U801.21, U801.23, U801.25, U801.27, U801.74, U801.76, U801.78, U801.80; also elsewhere on the board
/CellMaster-01/SPI1_NPCS1: U601.63; also elsewhere on the board
/CellMaster-01/SPI1_NPCS2: U701.63; also elsewhere on the board
/CellMaster-01/SPI1_NPCS3: U801.63; also elsewhere on the board
/CellMaster-02/ADC_BUSY0: U1001.67; also elsewhere on the board
/CellMaster-02/ADC_CONVST0: U1001.68; also elsewhere on the board
/CellMaster-02/ADC_RESET: U1001.36; also elsewhere on the board
/CellMaster-02/DAC0: U1001.1, U1001.3, U1001.8, U1001.10, U1001.11, U1001.13, U1001.18, U1001.20, U1001.21, U1001.23, U1001.25, U1001.27, U1001.74, U1001.76, U1001.78, U1001.80; also elsewhere on the board
/CellMaster-02/SPI1_NPCS0: U1001.63; also elsewhere on the board
/CellSlave-01A/SCLK: U601.55, U601.62, U701.55, U701.62, U801.55, U801.62; also elsewhere on the board
/CellSlave-01A/SDOA: U601.57, U701.57, U801.57; also elsewhere on the board
/CellSlave-02A/SCLK: U1001.62; also elsewhere on the board
/CellSlave-02A/SDI: U1001.55; also elsewhere on the board
/CellSlave-02A/SDOA: U1001.57; also elsewhere on the board
/RaspberryPiGPIOHeader/DC_POWER_3V3: C613.2, C614.2, C713.2, C714.2, C813.2, C814.2, C1013.2, C1014.2, U601.35, U601.40, U601.49, U701.35, U701.40, U701.49, U801.35, U801.40, U801.49, U1001.35, U1001.40, U1001.49; also elsewhere on the board
/RaspberryPiGPIOHeader/DC_POWER_5V0: C605.2, C606.1, C607.2, C608.2, C609.2, C610.2, C611.2, C612.2, C705.2, C706.1, C707.2, C708.2, C709.2, C710.2, C711.2, C712.2, C805.2, C806.1, C807.2, C808.2, C809.2, C810.2, C811.2, C812.2, C1005.2, C1006.1, C1007.2, C1008.2, C1009.2, C1010.2, C1011.2, C1012.2, U601.6, U601.15, U601.30, U601.71, U701.6, U701.15, U701.30, U701.71, U801.6, U801.15, U801.30, U801.71, U1001.6, U1001.15, U1001.30, U1001.71; also elsewhere on the board
GND: C601.2, C602.2, C603.2, C604.2, C605.1, C606.2, C607.1, C608.1, C609.1, C610.1, C611.1, C612.1, C613.1, C614.1, C615.2, C616.2, C701.2, C702.2, C703.2, C704.2, C705.1, C706.2, C707.1, C708.1, C709.1, C710.1, C711.1, C712.1, C713.1, C714.1, C715.2, C716.2, C801.2, C802.2, C803.2, C804.2, C805.1, C806.2, C807.1, C808.1, C809.1, C810.1, C811.1, C812.1, C813.1, C814.1, C815.2, C816.2, C1001.2, C1002.2, C1003.2, C1004.2, C1005.1, C1006.2, C1007.1, C1008.1, C1009.1, C1010.1, C1011.1, C1012.1, C1013.1, C1014.1, C1015.2, C1016.2, U601.5, U601.16, U601.29, U601.32, U601.34, U601.37, U601.38, U601.39, U601.41, U601.42, U601.43, U601.44, U601.45, U601.46, U601.47, U601.48, U601.50, U601.51, U601.53, U601.54, U601.58, U601.59, U601.60, U601.61, U601.64, U601.65, U601.66, U601.69, U601.72, U701.5, U701.16, U701.29, U701.32, U701.34, U701.37, U701.38, U701.39, U701.41, U701.42, U701.43, U701.44, U701.45, U701.46, U701.47, U701.48, U701.50, U701.51, U701.53, U701.54, U701.58, U701.59, U701.60, U701.61, U701.64, U701.65, U701.66, U701.69, U701.72, U801.5, U801.16, U801.29, U801.32, U801.34, U801.37, U801.38, U801.39, U801.41, U801.42, U801.43, U801.44, U801.45, U801.46, U801.47, U801.48, U801.50, U801.51, U801.53, U801.54, U801.58, U801.59, U801.60, U801.61, U801.64, U801.65, U801.66, U801.69, U801.72, U1001.5, U1001.16, U1001.29, U1001.32, U1001.34, U1001.37, U1001.38, U1001.39, U1001.41, U1001.42, U1001.43, U1001.44, U1001.45, U1001.46, U1001.47, U1001.48, U1001.50, U1001.51, U1001.53, U1001.54, U1001.58, U1001.59, U1001.60, U1001.61, U1001.64, U1001.65, U1001.66, U1001.69, U1001.72; also elsewhere on the board
unnamed: C601.1, C602.1, U601.70
unnamed: C603.1, TP617.1, U601.33
unnamed: C604.1, U601.31
unnamed: C615.1, C616.1, U601.52
unnamed: C701.1, C702.1, U701.70
unnamed: C703.1, TP717.1, U701.33
unnamed: C704.1, U701.31
unnamed: C715.1, C716.1, U701.52
unnamed: C801.1, C802.1, U801.70
unnamed: C803.1, TP817.1, U801.33
unnamed: C804.1, U801.31
unnamed: C815.1, C816.1, U801.52
unnamed: C1001.1, C1002.1, U1001.70
unnamed: C1003.1, TP1017.1, U1001.33
unnamed: C1004.1, U1001.31
unnamed: C1015.1, C1016.1, U1001.52
unnamed: TP601.1, U601.73
unnamed: TP602.1, U601.75
unnamed: TP603.1, U601.77
unnamed: TP604.1, U601.79
unnamed: TP605.1, U601.9
unnamed: TP606.1, U601.7
unnamed: TP607.1, U601.4
unnamed: TP608.1, U601.2
unnamed: TP609.1, U601.19
unnamed: TP610.1, U601.17
unnamed: TP611.1, U601.14
unnamed: TP612.1, U601.12
unnamed: TP613.1, U601.28
unnamed: TP614.1, U601.26
unnamed: TP615.1, U601.24
unnamed: TP616.1, U601.22
unnamed: TP701.1, U701.73
unnamed: TP702.1, U701.75
unnamed: TP703.1, U701.77
unnamed: TP704.1, U701.79
unnamed: TP705.1, U701.9
unnamed: TP706.1, U701.7
unnamed: TP707.1, U701.4
unnamed: TP708.1, U701.2
unnamed: TP709.1, U701.19
unnamed: TP710.1, U701.17
unnamed: TP711.1, U701.14
unnamed: TP712.1, U701.12
unnamed: TP713.1, U701.28
unnamed: TP714.1, U701.26
unnamed: TP715.1, U701.24
unnamed: TP716.1, U701.22
unnamed: TP801.1, U801.73
unnamed: TP802.1, U801.75
unnamed: TP803.1, U801.77
unnamed: TP804.1, U801.79
unnamed: TP805.1, U801.9
unnamed: TP806.1, U801.7
unnamed: TP807.1, U801.4
unnamed: TP808.1, U801.2
unnamed: TP809.1, U801.19
unnamed: TP810.1, U801.17
unnamed: TP811.1, U801.14
unnamed: TP812.1, U801.12
unnamed: TP813.1, U801.28
unnamed: TP814.1, U801.26
unnamed: TP815.1, U801.24
unnamed: TP816.1, U801.22
unnamed: TP1001.1, U1001.73
unnamed: TP1002.1, U1001.75
unnamed: TP1003.1, U1001.77
unnamed: TP1004.1, U1001.79
unnamed: TP1005.1, U1001.9
unnamed: TP1006.1, U1001.7
unnamed: TP1007.1, U1001.4
unnamed: TP1008.1, U1001.2
unnamed: TP1009.1, U1001.19
unnamed: TP1010.1, U1001.17
unnamed: TP1011.1, U1001.14
unnamed: TP1012.1, U1001.12
unnamed: TP1013.1, U1001.28
unnamed: TP1014.1, U1001.26
unnamed: TP1015.1, U1001.24
unnamed: TP1016.1, U1001.22

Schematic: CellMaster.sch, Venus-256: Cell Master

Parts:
C501: 10uF; C_0603_1608Metric_Pad0.84x1.00mm_HandSolder
C502, C503, C504, C506, C507, C508, C509, C510, C511, C512, C513, C514, C515, C516: 100nF; C_0603_1608Metric_Pad0.84x1.00mm_HandSolder
C505: 10pF; C_0603_1608Metric_Pad0.84x1.00mm_HandSolder
D501: LED_ARGB; LED_RGB_1210
JP501: GPAD_JP; SolderJumper-3_P1.3mm_Open_Pad1.0x1.5mm
L501: L; L_0603_1608Metric_Pad0.84x1.00mm_HandSolder
R501: 5.62K; R_0603_1608Metric_Pad0.84x1.00mm_HandSolder
TP501: AFE0_AD0; TestPoint_Pad_1.0x1.0mm
TP502: AFE0_AD1; TestPoint_Pad_1.0x1.0mm
TP503: ADVREF; TestPoint_Pad_1.0x1.0mm
TP504: GPAD; TestPoint_Pad_1.0x1.0mm
U501: ATSAME70Q21A-AN; LQFP-144_20x20mm_P0.5mm

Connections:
/ARMJTAGHeader/SWCLK: U501.89 (PB7/SWCLK/TCK); also elsewhere on the board
/ARMJTAGHeader/SWDIO: U501.79 (PB6/SWDIO/TMS); also elsewhere on the board
/ARMJTAGHeader/TARGET_RESET: U501.83 (NRST); also elsewhere on the board
/ARMJTAGHeader/TRACESWO: U501.109 (PB5/TDO/TRACESWO/WKUP13); also elsewhere on the board
/CellMaster-01/ADC_BUSY0: U501.46 (PA23); also elsewhere on the board
/CellMaster-01/ADC_BUSY1: U501.56 (PA24); also elsewhere on the board
/CellMaster-01/ADC_BUSY2: U501.59 (PA25); also elsewhere on the board
/CellMaster-01/ADC_BUSY3: U501.62 (PA26); also elsewhere on the board
/CellMaster-01/ADC_CONVST0: U501.4 (PE0/AFE1_AD11); also elsewhere on the board
/CellMaster-01/ADC_CONVST1: U501.6 (PE1); also elsewhere on the board
/CellMaster-01/ADC_CONVST2: U501.7 (PE2); also elsewhere on the board
/CellMaster-01/ADC_CONVST3: U501.10 (PE3/AFE1_AD10); also elsewhere on the board
/CellMaster-01/ADC_RESET: U501.70 (PA27); also elsewhere on the board
/CellMaster-01/DAC0: U501.20 (PB1/AFE1_AD0/RTCOUT1), U501.144 (PB13/DAC0); also elsewhere on the board
/CellMaster-01/SPI0_MISO: U501.65 (SPI0_MISO/PD20); also elsewhere on the board
/CellMaster-01/SPI0_MOSI: U501.63 (SPI0_MOSI/PD21); also elsewhere on the board
/CellMaster-01/SPI0_SPCK: U501.60 (SPI0_SPCK/PD22); also elsewhere on the board
/CellMaster-01/SPI1_NPCS0: U501.133 (SPI1_NPCS0/PC25); also elsewhere on the board
/CellMaster-01/SPI1_NPCS1: U501.76 (SPI1_NPCS1/PC28); also elsewhere on the board
/CellMaster-01/SPI1_NPCS2: U501.16 (SPI1_NPCS2/AFE1_AD4/PC29); also elsewhere on the board
/CellMaster-01/SPI1_NPCS3: U501.15 (SPI1_NPCS3/AFE1_AD5/PC30); also elsewhere on the board
/CellMaster-01/VCC_MCU_P3V3: C501.1, C503.1, C504.1, C506.1, C507.1, C508.1, C509.1, C510.1, C511.1, C512.1, C513.1, C514.1, C515.1, C516.1, L501.2, U501.5 (VDDIN), U501.29 (VDDCORE), U501.30 (VDDIO), U501.33 (VDDCORE), U501.43 (VDDIO), U501.50 (VDDCORE), U501.72 (VDDIO), U501.80 (VDDIO), U501.81 (VDDCORE), U501.96 (VDDIO), U501.107 (VDDCORE), U501.134 (VDDUTMII), U501.143 (VDDPLLUSB); also elsewhere on the board
/CellSlave-01A/SCLK: U501.12 (SPI1_MOSI/AFE1_AD8/PC27), U501.130 (SPI1_SPCK/PC24); also elsewhere on the board
/CellSlave-01A/SDOA: U501.13 (SPI1_MISO/AFE1_AD7/PC26); also elsewhere on the board
GND: C501.2, C502.2, C503.2, C504.2, C505.2, C506.2, C507.2, C508.2, C509.2, C510.2, C511.2, C512.2, C513.2, C514.2, C515.2, C516.2, JP501.3, R501.2, U501.8 (VREFN), U501.44 (GND), U501.61 (GND), U501.95 (GND), U501.115 (GND), U501.135 (GND), U501.138 (GND); also elsewhere on the board
unnamed: C502.1, L501.1, TP503.1, U501.9 (VREFP)
unnamed: C505.1, R501.1, U501.140 (VBG)
unnamed: D501.1, U501.51 (PA14/WKUP8/PIODCEN1)
unnamed: D501.2, U501.42 (PA13/PIODC7)
unnamed: D501.3, U501.68 (PA12/PIODC6)
unnamed: D501.4, U501.64 (PA11/WKUP7/PIODC5)
unnamed: JP501.1, U501.1 (SPI1_NPCS1/DAC1/PD0)
unnamed: JP501.2, TP504.1
unnamed: TP501.1, U501.34 (UTXD3/AFE0_AD0/PD30)
unnamed: TP502.1, U501.32 (PA21/AFE0_AD1/PIODCEN2)

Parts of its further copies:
C901: 10uF; C_0603_1608Metric_Pad0.84x1.00mm_HandSolder
C902, C903, C904, C906, C907, C908, C909, C910, C911, C912, C913, C914, C915, C916: 100nF; C_0603_1608Metric_Pad0.84x1.00mm_HandSolder
C905: 10pF; C_0603_1608Metric_Pad0.84x1.00mm_HandSolder
D901: LED_ARGB; LED_RGB_1210
JP901: GPAD_JP; SolderJumper-3_P1.3mm_Open_Pad1.0x1.5mm
L901: L; L_0603_1608Metric_Pad0.84x1.00mm_HandSolder
R901: 5.62K; R_0603_1608Metric_Pad0.84x1.00mm_HandSolder
TP901: AFE0_AD0; TestPoint_Pad_1.0x1.0mm
TP902: AFE0_AD1; TestPoint_Pad_1.0x1.0mm
TP903: ADVREF; TestPoint_Pad_1.0x1.0mm
TP904: GPAD; TestPoint_Pad_1.0x1.0mm
U901: ATSAME70Q21A-AN; LQFP-144_20x20mm_P0.5mm

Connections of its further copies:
/ARMJTAGHeader/SWCLK: U901.89 (PB7/SWCLK/TCK); also elsewhere on the board
/ARMJTAGHeader/SWDIO: U901.79 (PB6/SWDIO/TMS); also elsewhere on the board
/ARMJTAGHeader/TARGET_RESET: U901.83 (NRST); also elsewhere on the board
/ARMJTAGHeader/TRACESWO: U901.109 (PB5/TDO/TRACESWO/WKUP13); also elsewhere on the board
/CellMaster-01/SPI0_MISO: U901.65 (SPI0_MISO/PD20); also elsewhere on the board
/CellMaster-01/SPI0_MOSI: U901.63 (SPI0_MOSI/PD21); also elsewhere on the board
/CellMaster-01/SPI0_SPCK: U901.60 (SPI0_SPCK/PD22); also elsewhere on the board
/CellMaster-02/ADC_BUSY0: U901.46 (PA23); also elsewhere on the board
/CellMaster-02/ADC_CONVST0: U901.4 (PE0/AFE1_AD11); also elsewhere on the board
/CellMaster-02/ADC_RESET: U901.70 (PA27); also elsewhere on the board
/CellMaster-02/DAC0: U901.20 (PB1/AFE1_AD0/RTCOUT1), U901.144 (PB13/DAC0); also elsewhere on the board
/CellMaster-02/SPI1_NPCS0: U901.133 (SPI1_NPCS0/PC25); also elsewhere on the board
/CellMaster-02/VCC_MCU_P3V3: C901.1, C903.1, C904.1, C906.1, C907.1, C908.1, C909.1, C910.1, C911.1, C912.1, C913.1, C914.1, C915.1, C916.1, L901.2, U901.5 (VDDIN), U901.29 (VDDCORE), U901.30 (VDDIO), U901.33 (VDDCORE), U901.43 (VDDIO), U901.50 (VDDCORE), U901.72 (VDDIO), U901.80 (VDDIO), U901.81 (VDDCORE), U901.96 (VDDIO), U901.107 (VDDCORE), U901.134 (VDDUTMII), U901.143 (VDDPLLUSB); also elsewhere on the board
/CellSlave-02A/SCLK: U901.130 (SPI1_SPCK/PC24); also elsewhere on the board
/CellSlave-02A/SDI: U901.12 (SPI1_MOSI/AFE1_AD8/PC27); also elsewhere on the board
/CellSlave-02A/SDOA: U901.13 (SPI1_MISO/AFE1_AD7/PC26); also elsewhere on the board
GND: C901.2, C902.2, C903.2, C904.2, C905.2, C906.2, C907.2, C908.2, C909.2, C910.2, C911.2, C912.2, C913.2, C914.2, C915.2, C916.2, JP901.3, R901.2, U901.8 (VREFN), U901.44 (GND), U901.61 (GND), U901.95 (GND), U901.115 (GND), U901.135 (GND), U901.138 (GND); also elsewhere on the board
unnamed: C902.1, L901.1, TP903.1, U901.9 (VREFP)
unnamed: C905.1, R901.1, U901.140 (VBG)
unnamed: D901.1, U901.51 (PA14/WKUP8/PIODCEN1)
unnamed: D901.2, U901.42 (PA13/PIODC7)
unnamed: D901.3, U901.68 (PA12/PIODC6)
unnamed: D901.4, U901.64 (PA11/WKUP7/PIODC5)
unnamed: JP901.1, U901.1 (SPI1_NPCS1/DAC1/PD0)
unnamed: JP901.2, TP904.1
unnamed: TP901.1, U901.34 (UTXD3/AFE0_AD0/PD30)
unnamed: TP902.1, U901.32 (PA21/AFE0_AD1/PIODCEN2)

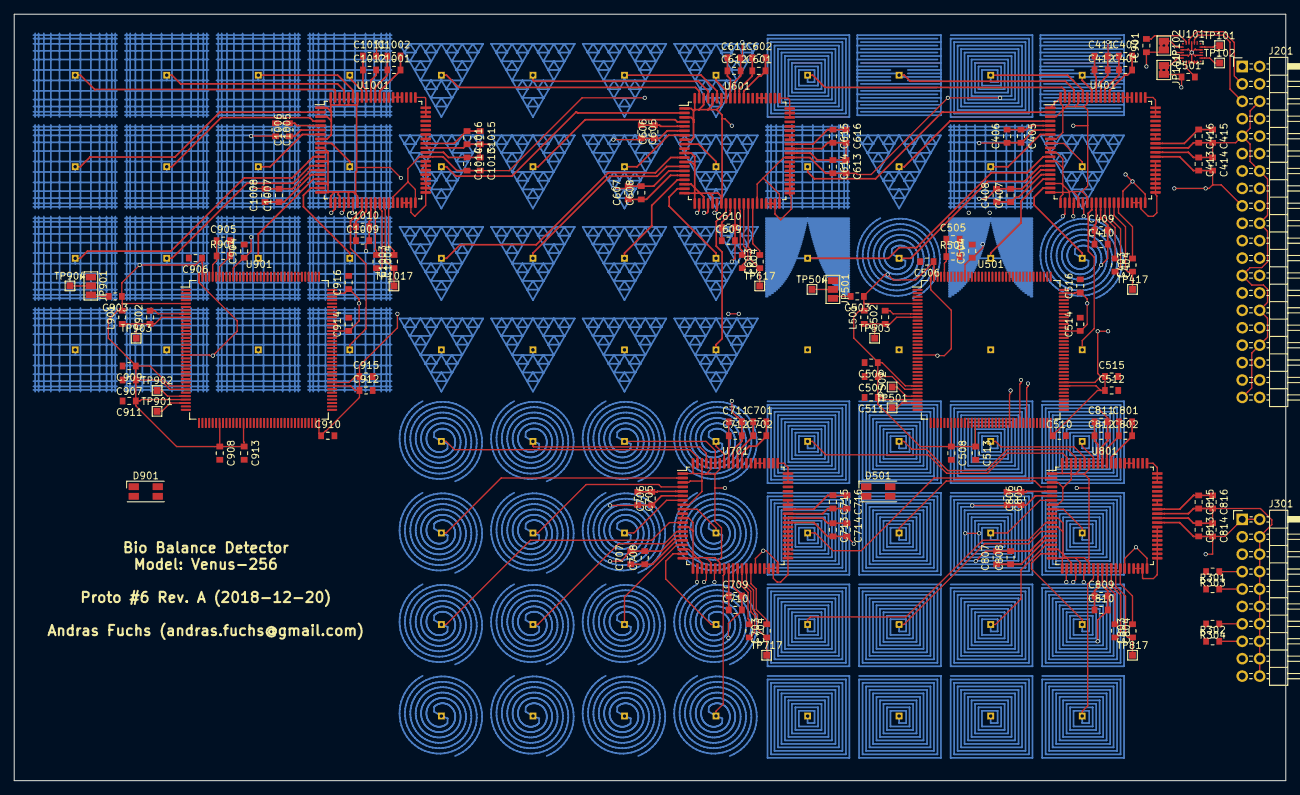
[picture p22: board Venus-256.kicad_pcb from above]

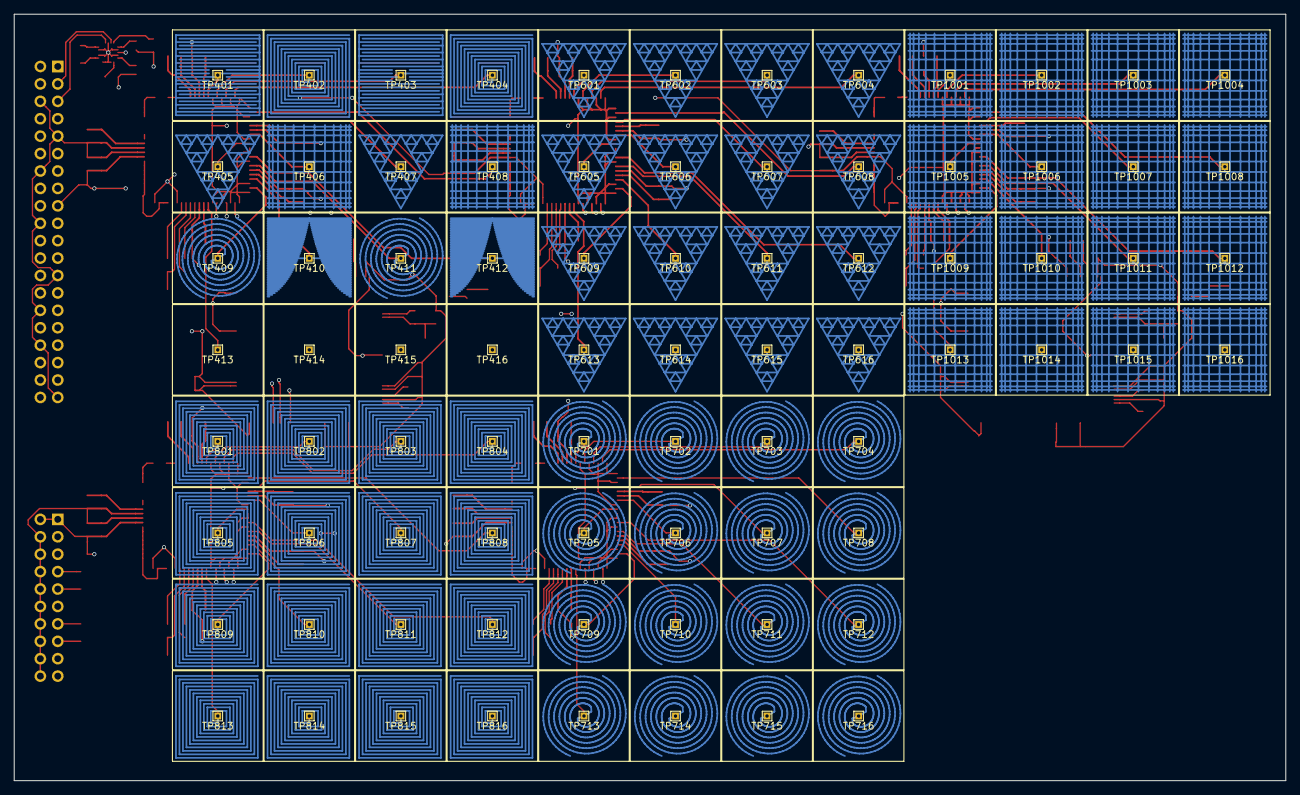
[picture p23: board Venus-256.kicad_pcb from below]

Board: 4 copper layers, 185.4 x 111.8 mm, 231 parts (80 on the bottom side), 166 nets.

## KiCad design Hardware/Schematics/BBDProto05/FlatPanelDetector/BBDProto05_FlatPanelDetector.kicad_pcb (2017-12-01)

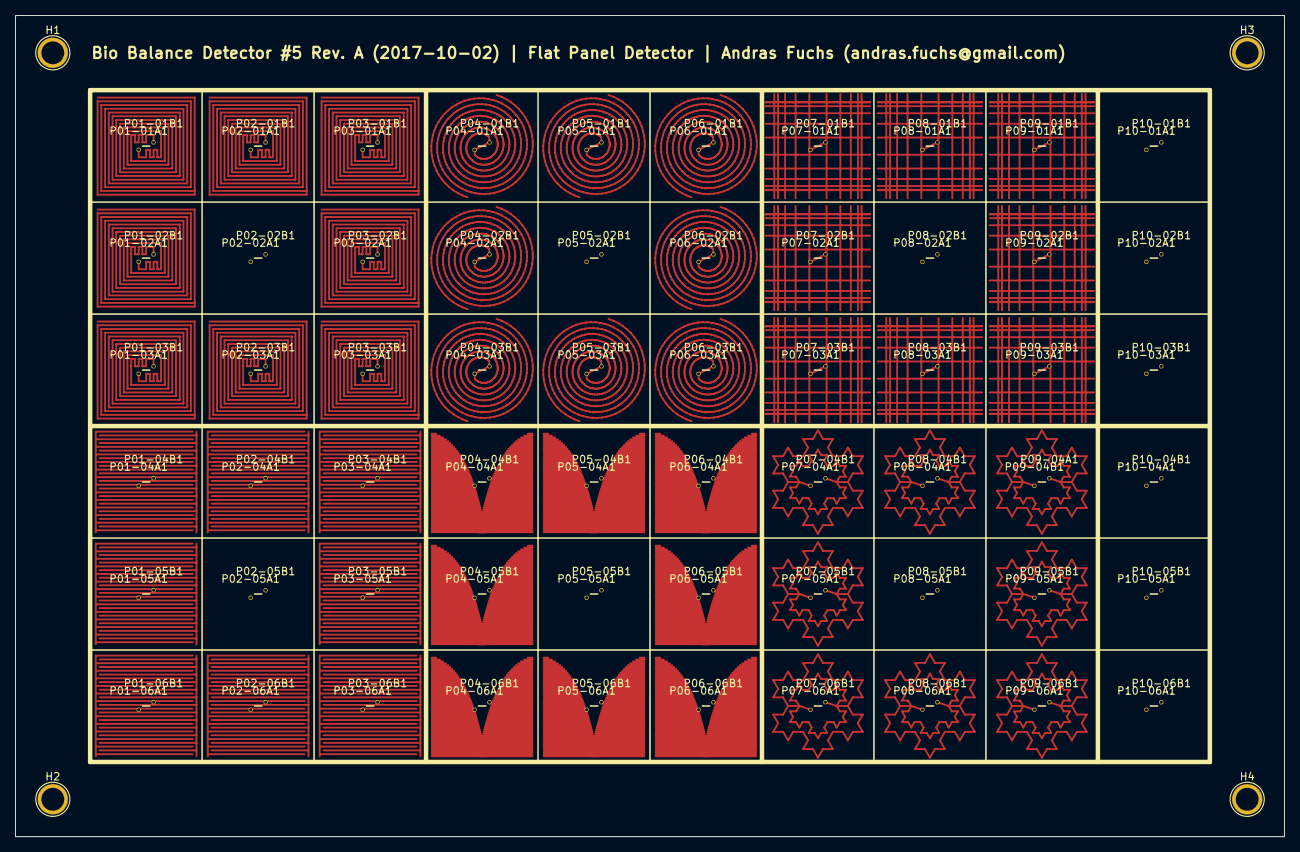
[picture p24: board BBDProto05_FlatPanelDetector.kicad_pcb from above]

Board: 2 copper layers, 170.0 x 110.0 mm, 124 parts (0 on the bottom side), 60 nets.

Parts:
H1, H2, H3, H4: VIA_06MM; 1pin
P01-01A1, P01-01B1, P01-02A1, P01-02B1, P01-03A1, P01-03B1, P01-04A1, P01-04B1, P01-05A1, P01-05B1, P01-06A1, P01-06B1, P02-01A1, P02-01B1, P02-02A1, P02-02B1, P02-03A1, P02-03B1, P02-04A1, P02-04B1, P02-05A1, P02-05B1, P02-06A1, P02-06B1, P03-01A1, P03-01B1, P03-02A1, P03-02B1, P03-03A1, P03-03B1, P03-04A1, P03-04B1, P03-05A1, P03-05B1, P03-06A1, P03-06B1, P04-01A1, P04-01B1, P04-02A1, P04-02B1, P04-03A1, P04-03B1, P04-04A1, P04-04B1, P04-05A1, P04-05B1, P04-06A1, P04-06B1, P05-01A1, P05-01B1, P05-02A1, P05-02B1, P05-03A1, P05-03B1, P05-04A1, P05-04B1, P05-05A1, P05-05B1, P05-06A1, P05-06B1, P06-01A1, P06-01B1, P06-02A1, P06-02B1, P06-03A1, P06-03B1, P06-04A1, P06-04B1, P06-05A1, P06-05B1, P06-06A1, P06-06B1, P07-01A1, P07-01B1, P07-02A1, P07-02B1, P07-03A1, P07-03B1, P07-04A1, P07-04B1, P07-05A1, P07-05B1, P07-06A1, P07-06B1, P08-01A1, P08-01B1, P08-02A1, P08-02B1, P08-03A1, P08-03B1, P08-04A1, P08-04B1, P08-05A1, P08-05B1, P08-06A1, P08-06B1, P09-01A1, P09-01B1, P09-02A1, P09-02B1, P09-03A1, P09-03B1, P09-04A1, P09-04B1, P09-05A1, P09-05B1, P09-06A1, P09-06B1, P10-01A1, P10-01B1, P10-02A1, P10-02B1, P10-03A1, P10-03B1, P10-04A1, P10-04B1, P10-05A1, P10-05B1, P10-06A1, P10-06B1: VIA_06MM; SolderWirePad_single_0-4mmDrill

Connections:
unnamed: P01-01A1.1, P01-01B1.1
unnamed: P01-02A1.1, P01-02B1.1
unnamed: P01-03A1.1, P01-03B1.1
unnamed: P01-04A1.1, P01-04B1.1
unnamed: P01-05A1.1, P01-05B1.1
unnamed: P01-06A1.1, P01-06B1.1
unnamed: P02-01A1.1, P02-01B1.1
unnamed: P02-02A1.1, P02-02B1.1
unnamed: P02-03A1.1, P02-03B1.1
unnamed: P02-04A1.1, P02-04B1.1
unnamed: P02-05A1.1, P02-05B1.1
unnamed: P02-06A1.1, P02-06B1.1
unnamed: P03-01A1.1, P03-01B1.1
unnamed: P03-02A1.1, P03-02B1.1
unnamed: P03-03A1.1, P03-03B1.1
unnamed: P03-04A1.1, P03-04B1.1
unnamed: P03-05A1.1, P03-05B1.1
unnamed: P03-06A1.1, P03-06B1.1
unnamed: P04-01A1.1, P04-01B1.1
unnamed: P04-02A1.1, P04-02B1.1
unnamed: P04-03A1.1, P04-03B1.1
unnamed: P04-04A1.1, P04-04B1.1
unnamed: P04-05A1.1, P04-05B1.1
unnamed: P04-06A1.1, P04-06B1.1
unnamed: P05-01A1.1, P05-01B1.1
unnamed: P05-02A1.1, P05-02B1.1
unnamed: P05-03A1.1, P05-03B1.1
unnamed: P05-04A1.1, P05-04B1.1
unnamed: P05-05A1.1, P05-05B1.1
unnamed: P05-06A1.1, P05-06B1.1
unnamed: P06-01A1.1, P06-01B1.1
unnamed: P06-02A1.1, P06-02B1.1
unnamed: P06-03A1.1, P06-03B1.1
unnamed: P06-04A1.1, P06-04B1.1
unnamed: P06-05A1.1, P06-05B1.1
unnamed: P06-06A1.1, P06-06B1.1
unnamed: P07-01A1.1, P07-01B1.1
unnamed: P07-02A1.1, P07-02B1.1
unnamed: P07-03A1.1, P07-03B1.1
unnamed: P07-04A1.1, P07-04B1.1
unnamed: P07-05A1.1, P07-05B1.1
unnamed: P07-06A1.1, P07-06B1.1
unnamed: P08-01A1.1, P08-01B1.1
unnamed: P08-02A1.1, P08-02B1.1
unnamed: P08-03A1.1, P08-03B1.1
unnamed: P08-04A1.1, P08-04B1.1
unnamed: P08-05A1.1, P08-05B1.1
unnamed: P08-06A1.1, P08-06B1.1
unnamed: P09-01A1.1, P09-01B1.1
unnamed: P09-02A1.1, P09-02B1.1
unnamed: P09-03A1.1, P09-03B1.1
unnamed: P09-04A1.1, P09-04B1.1
unnamed: P09-05A1.1, P09-05B1.1
unnamed: P09-06A1.1, P09-06B1.1
unnamed: P10-01A1.1, P10-01B1.1
unnamed: P10-02A1.1, P10-02B1.1
unnamed: P10-03A1.1, P10-03B1.1
unnamed: P10-04A1.1, P10-04B1.1
unnamed: P10-05A1.1, P10-05B1.1
unnamed: P10-06A1.1, P10-06B1.1

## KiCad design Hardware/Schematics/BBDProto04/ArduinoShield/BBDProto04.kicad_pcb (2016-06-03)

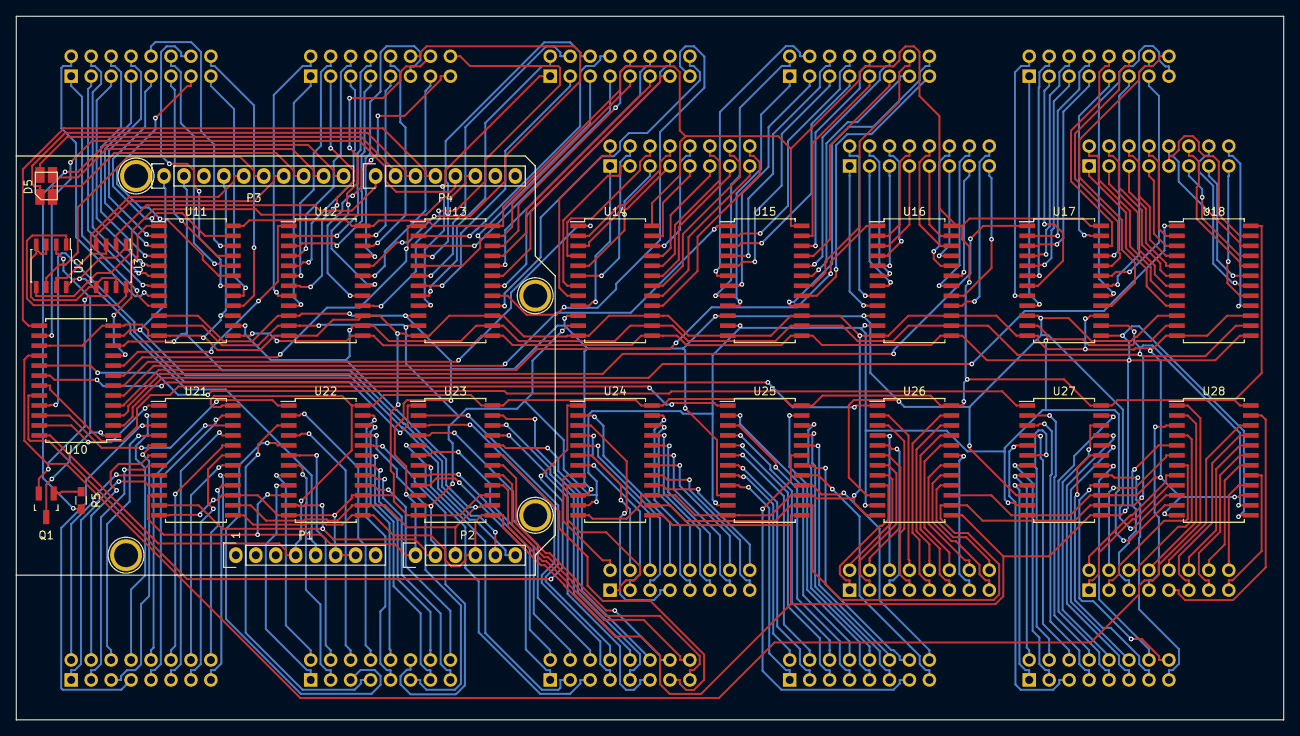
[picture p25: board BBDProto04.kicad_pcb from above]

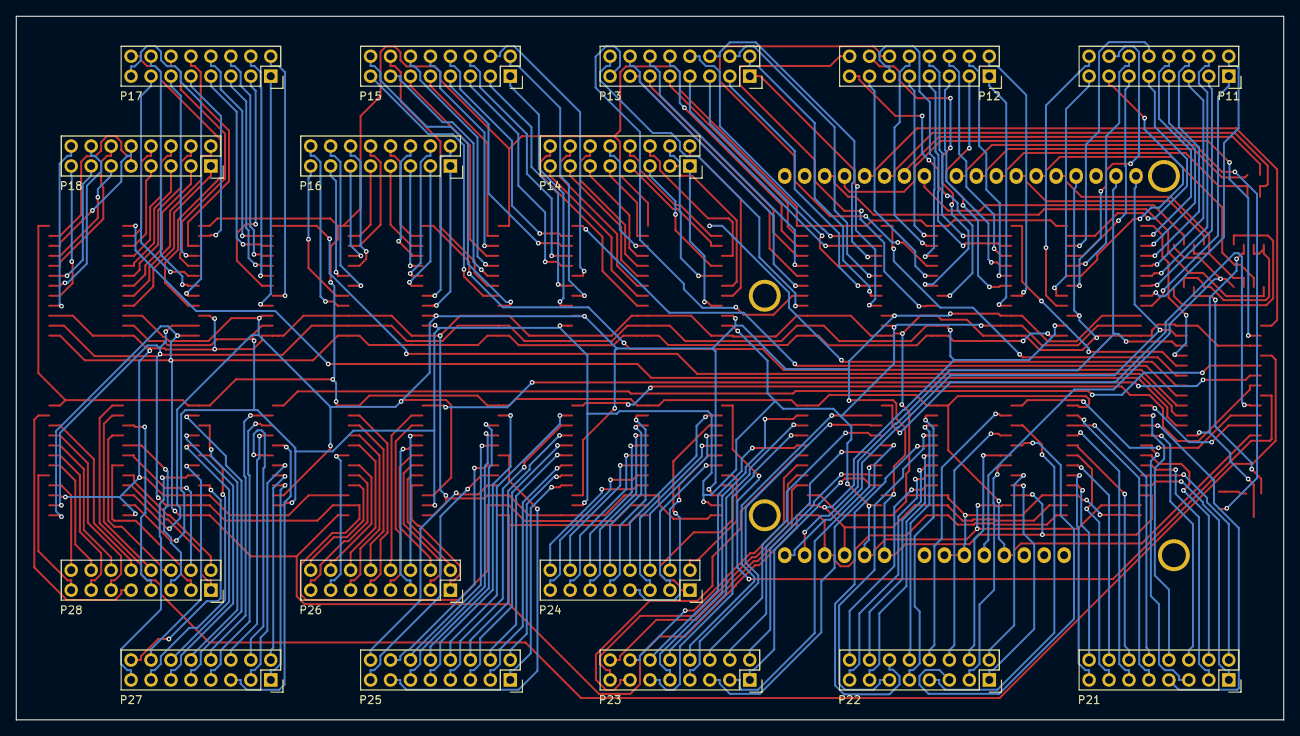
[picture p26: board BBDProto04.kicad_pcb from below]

Board: 2 copper layers, 161.3 x 89.5 mm, 46 parts (16 on the bottom side), 298 nets.

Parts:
D5: LED_RCBG; LED_3528-PLCC4
P1: Power; Socket_Strip_Arduino_1x08
P2: Analog; Socket_Strip_Arduino_1x06
P3: Digital; Socket_Strip_Arduino_1x10
P4: Digital; Socket_Strip_Arduino_1x08
P5, P6, P7, P8: CONN_1; Arduino_1pin
P11, P12, P13, P14, P15, P16, P17, P18, P21, P22, P23, P24, P25, P26, P27, P28: CONN_02X08; Socket_Strip_Straight_2x08
Q1: Q_NPN_BCE; SOT-23_Handsoldering
R5: 1k; R_0603_HandSoldering
U2: LTC1864; SOIC-8_3.9x4.9mm_Pitch1.27mm
U3: MCP4822; SOIC-8_3.9x4.9mm_Pitch1.27mm
U10, U11, U12, U13, U14, U15, U16, U17, U18, U21, U22, U23, U24, U25, U26, U27, U28: CD74HC4067; SOIC-24_7.5x15.4mm_Pitch1.27mm

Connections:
/2: P4.6, U2.5
/3(**): P4.5, U10.14
/4: P4.4, U10.13
/5(**): D5.1, P4.3
/6(**): D5.4, P4.2
/7: P4.1, U3.2
/8: P3.10, R5.2
/9(**): D5.3, P3.9
/10(**/SS): D5.2, P3.8
/11(**/MOSI): P3.7, U3.4
/12(MISO): P3.6, U2.6
/13(SCK): P3.5, U2.7, U3.3
/+3.3V: P1.4, U10.24, U11.24, U12.24, U13.24, U14.24, U15.24, U16.24, U17.24, U18.24, U21.24, U22.24, U23.24, U24.24, U25.24, U26.24, U27.24, U28.24
/+5.0V: P1.5, U2.8, U3.1
/A0: P2.1, U11.10, U12.10, U13.10, U14.10, U15.10, U16.10, U17.10, U18.10, U21.10, U22.10, U23.10, U24.10, U25.10, U26.10, U27.10, U28.10
/A1: P2.2, U11.11, U12.11, U13.11, U14.11, U15.11, U16.11, U17.11, U18.11, U21.11, U22.11, U23.11, U24.11, U25.11, U26.11, U27.11, U28.11
/A2: P2.3, U11.14, U12.14, U13.14, U14.14, U15.14, U16.14, U17.14, U18.14, U21.14, U22.14, U23.14, U24.14, U25.14, U26.14, U27.14, U28.14
/A3: P2.4, U11.13, U12.13, U13.13, U14.13, U15.13, U16.13, U17.13, U18.13, U21.13, U22.13, U23.13, U24.13, U25.13, U26.13, U27.13, U28.13
/A4(SDA): P2.5, P3.2, U10.10
/A5(SCL): P2.6, P3.1, U10.11
/ADC-VREF: U2.1, U3.8
/DAC-MULTIPLEXER-OUTPUT: Q1.2, U3.6
/MULTIPLEXER-INPUT: Q1.3, U2.2, U10.1
GND: P1.6, P1.7, P3.4, U10.12, U10.15, U11.12, U11.15, U12.12, U12.15, U13.12, U13.15, U14.12, U14.15, U15.12, U15.15, U16.12, U16.15, U17.12, U17.15, U18.12, U18.15, U21.12, U21.15, U22.12, U22.15, U23.12, U23.15, U24.12, U24.15, U25.12, U25.15, U26.12, U26.15, U27.12, U27.15, U28.12, U28.15
unnamed: P11.1, U11.9
unnamed: P11.2, U11.8
unnamed: P11.3, U11.7
unnamed: P11.4, U11.6
unnamed: P11.5, U11.5
unnamed: P11.6, U11.4
unnamed: P11.7, U11.3
unnamed: P11.8, U11.2
unnamed: P11.9, U11.23
unnamed: P11.10, U11.22
unnamed: P11.11, U11.21
unnamed: P11.12, U11.20
unnamed: P11.13, U11.19
unnamed: P11.14, U11.18
unnamed: P11.15, U11.17
unnamed: P11.16, U11.16
unnamed: P12.1, U12.9
unnamed: P12.2, U12.8
unnamed: P12.3, U12.7
unnamed: P12.4, U12.6
unnamed: P12.5, U12.5
unnamed: P12.6, U12.4
unnamed: P12.7, U12.3
unnamed: P12.8, U12.2
unnamed: P12.9, U12.23
unnamed: P12.10, U12.22
unnamed: P12.11, U12.21
unnamed: P12.12, U12.20
unnamed: P12.13, U12.19
unnamed: P12.14, U12.18
unnamed: P12.15, U12.17
unnamed: P12.16, U12.16
unnamed: P13.1, U13.9
unnamed: P13.2, U13.8
unnamed: P13.3, U13.7
unnamed: P13.4, U13.6
unnamed: P13.5, U13.5
unnamed: P13.6, U13.4
unnamed: P13.7, U13.3
unnamed: P13.8, U13.2
unnamed: P13.9, U13.23
unnamed: P13.10, U13.22
unnamed: P13.11, U13.21
unnamed: P13.12, U13.20
unnamed: P13.13, U13.19
unnamed: P13.14, U13.18
unnamed: P13.15, U13.17
unnamed: P13.16, U13.16
unnamed: P14.1, U14.9
unnamed: P14.2, U14.8
unnamed: P14.3, U14.7
unnamed: P14.4, U14.6
unnamed: P14.5, U14.5
unnamed: P14.6, U14.4
unnamed: P14.7, U14.3
unnamed: P14.8, U14.2
unnamed: P14.9, U14.23
unnamed: P14.10, U14.22
unnamed: P14.11, U14.21
unnamed: P14.12, U14.20
unnamed: P14.13, U14.19
unnamed: P14.14, U14.18
unnamed: P14.15, U14.17
unnamed: P14.16, U14.16
unnamed: P15.1, U15.9
unnamed: P15.2, U15.8
unnamed: P15.3, U15.7
unnamed: P15.4, U15.6
unnamed: P15.5, U15.5
unnamed: P15.6, U15.4
unnamed: P15.7, U15.3
unnamed: P15.8, U15.2
unnamed: P15.9, U15.23
unnamed: P15.10, U15.22
unnamed: P15.11, U15.21
unnamed: P15.12, U15.20
unnamed: P15.13, U15.19
unnamed: P15.14, U15.18
unnamed: P15.15, U15.17
unnamed: P15.16, U15.16
unnamed: P16.1, U16.9
unnamed: P16.2, U16.8
unnamed: P16.3, U16.7
unnamed: P16.4, U16.6
unnamed: P16.5, U16.5
unnamed: P16.6, U16.4
unnamed: P16.7, U16.3
unnamed: P16.8, U16.2
unnamed: P16.9, U16.23
unnamed: P16.10, U16.22
unnamed: P16.11, U16.21
unnamed: P16.12, U16.20
unnamed: P16.13, U16.19
unnamed: P16.14, U16.18
unnamed: P16.15, U16.17
unnamed: P16.16, U16.16
unnamed: P17.1, U17.9
unnamed: P17.2, U17.8
unnamed: P17.3, U17.7
unnamed: P17.4, U17.6
unnamed: P17.5, U17.5
unnamed: P17.6, U17.4
unnamed: P17.7, U17.3
unnamed: P17.8, U17.2
unnamed: P17.9, U17.23
unnamed: P17.10, U17.22
unnamed: P17.11, U17.21
unnamed: P17.12, U17.20
unnamed: P17.13, U17.19
unnamed: P17.14, U17.18
unnamed: P17.15, U17.17
unnamed: P17.16, U17.16
unnamed: P18.1, U18.9
unnamed: P18.2, U18.8
unnamed: P18.3, U18.7
unnamed: P18.4, U18.6
unnamed: P18.5, U18.5
unnamed: P18.6, U18.4
unnamed: P18.7, U18.3
unnamed: P18.8, U18.2
unnamed: P18.9, U18.23
unnamed: P18.10, U18.22
unnamed: P18.11, U18.21
unnamed: P18.12, U18.20
unnamed: P18.13, U18.19
unnamed: P18.14, U18.18
unnamed: P18.15, U18.17
unnamed: P18.16, U18.16
unnamed: P21.1, U21.9
unnamed: P21.2, U21.8
unnamed: P21.3, U21.7
unnamed: P21.4, U21.6
unnamed: P21.5, U21.5
unnamed: P21.6, U21.4
unnamed: P21.7, U21.3
unnamed: P21.8, U21.2
unnamed: P21.9, U21.23
unnamed: P21.10, U21.22
unnamed: P21.11, U21.21
unnamed: P21.12, U21.20
unnamed: P21.13, U21.19
unnamed: P21.14, U21.18
unnamed: P21.15, U21.17
unnamed: P21.16, U21.16
unnamed: P22.1, U22.9
unnamed: P22.2, U22.8
unnamed: P22.3, U22.7
unnamed: P22.4, U22.6
unnamed: P22.5, U22.5
unnamed: P22.6, U22.4
unnamed: P22.7, U22.3
unnamed: P22.8, U22.2
unnamed: P22.9, U22.23
unnamed: P22.10, U22.22
unnamed: P22.11, U22.21
unnamed: P22.12, U22.20
unnamed: P22.13, U22.19
unnamed: P22.14, U22.18
unnamed: P22.15, U22.17
unnamed: P22.16, U22.16
unnamed: P23.1, U23.9
unnamed: P23.2, U23.8
unnamed: P23.3, U23.7
unnamed: P23.4, U23.6
unnamed: P23.5, U23.5
unnamed: P23.6, U23.4
unnamed: P23.7, U23.3
unnamed: P23.8, U23.2
unnamed: P23.9, U23.23
unnamed: P23.10, U23.22
unnamed: P23.11, U23.21
unnamed: P23.12, U23.20
unnamed: P23.13, U23.19
unnamed: P23.14, U23.18
unnamed: P23.15, U23.17
unnamed: P23.16, U23.16
unnamed: P24.1, U24.9
unnamed: P24.2, U24.8
unnamed: P24.3, U24.7
unnamed: P24.4, U24.6
unnamed: P24.5, U24.5
unnamed: P24.6, U24.4
unnamed: P24.7, U24.3
unnamed: P24.8, U24.2
unnamed: P24.9, U24.23
unnamed: P24.10, U24.22
unnamed: P24.11, U24.21
unnamed: P24.12, U24.20
unnamed: P24.13, U24.19
unnamed: P24.14, U24.18
unnamed: P24.15, U24.17
unnamed: P24.16, U24.16
unnamed: P25.1, U25.9
unnamed: P25.2, U25.8
unnamed: P25.3, U25.7
unnamed: P25.4, U25.6
unnamed: P25.5, U25.5
unnamed: P25.6, U25.4
unnamed: P25.7, U25.3
unnamed: P25.8, U25.2
unnamed: P25.9, U25.23
unnamed: P25.10, U25.22
unnamed: P25.11, U25.21
unnamed: P25.12, U25.20
unnamed: P25.13, U25.19
unnamed: P25.14, U25.18
unnamed: P25.15, U25.17
unnamed: P25.16, U25.16
unnamed: P26.1, U26.9
unnamed: P26.2, U26.8
unnamed: P26.3, U26.7
unnamed: P26.4, U26.6
unnamed: P26.5, U26.5
unnamed: P26.6, U26.4
unnamed: P26.7, U26.3
unnamed: P26.8, U26.2
unnamed: P26.9, U26.23
unnamed: P26.10, U26.22
unnamed: P26.11, U26.21
unnamed: P26.12, U26.20
unnamed: P26.13, U26.19
unnamed: P26.14, U26.18
unnamed: P26.15, U26.17
unnamed: P26.16, U26.16
unnamed: P27.1, U27.9
unnamed: P27.2, U27.8
unnamed: P27.3, U27.7
unnamed: P27.4, U27.6
unnamed: P27.5, U27.5
unnamed: P27.6, U27.4
unnamed: P27.7, U27.3
unnamed: P27.8, U27.2
unnamed: P27.9, U27.23
unnamed: P27.10, U27.22
unnamed: P27.11, U27.21
unnamed: P27.12, U27.20
unnamed: P27.13, U27.19
unnamed: P27.14, U27.18
unnamed: P27.15, U27.17
unnamed: P27.16, U27.16
unnamed: P28.1, U28.9
unnamed: P28.2, U28.8
unnamed: P28.3, U28.7
unnamed: P28.4, U28.6
unnamed: P28.5, U28.5
unnamed: P28.6, U28.4
unnamed: P28.7, U28.3
unnamed: P28.8, U28.2
unnamed: P28.9, U28.23
unnamed: P28.10, U28.22
unnamed: P28.11, U28.21
unnamed: P28.12, U28.20
unnamed: P28.13, U28.19
unnamed: P28.14, U28.18
unnamed: P28.15, U28.17
unnamed: P28.16, U28.16
unnamed: Q1.1, R5.1
unnamed: U2.3, U2.4, U3.5, U3.7
unnamed: U10.2, U18.1
unnamed: U10.3, U17.1
unnamed: U10.4, U16.1
unnamed: U10.5, U15.1
unnamed: U10.6, U14.1
unnamed: U10.7, U13.1
unnamed: U10.8, U12.1
unnamed: U10.9, U11.1
unnamed: U10.16, U28.1
unnamed: U10.17, U27.1
unnamed: U10.18, U26.1
unnamed: U10.19, U25.1
unnamed: U10.20, U24.1
unnamed: U10.21, U23.1
unnamed: U10.22, U22.1
unnamed: U10.23, U21.1

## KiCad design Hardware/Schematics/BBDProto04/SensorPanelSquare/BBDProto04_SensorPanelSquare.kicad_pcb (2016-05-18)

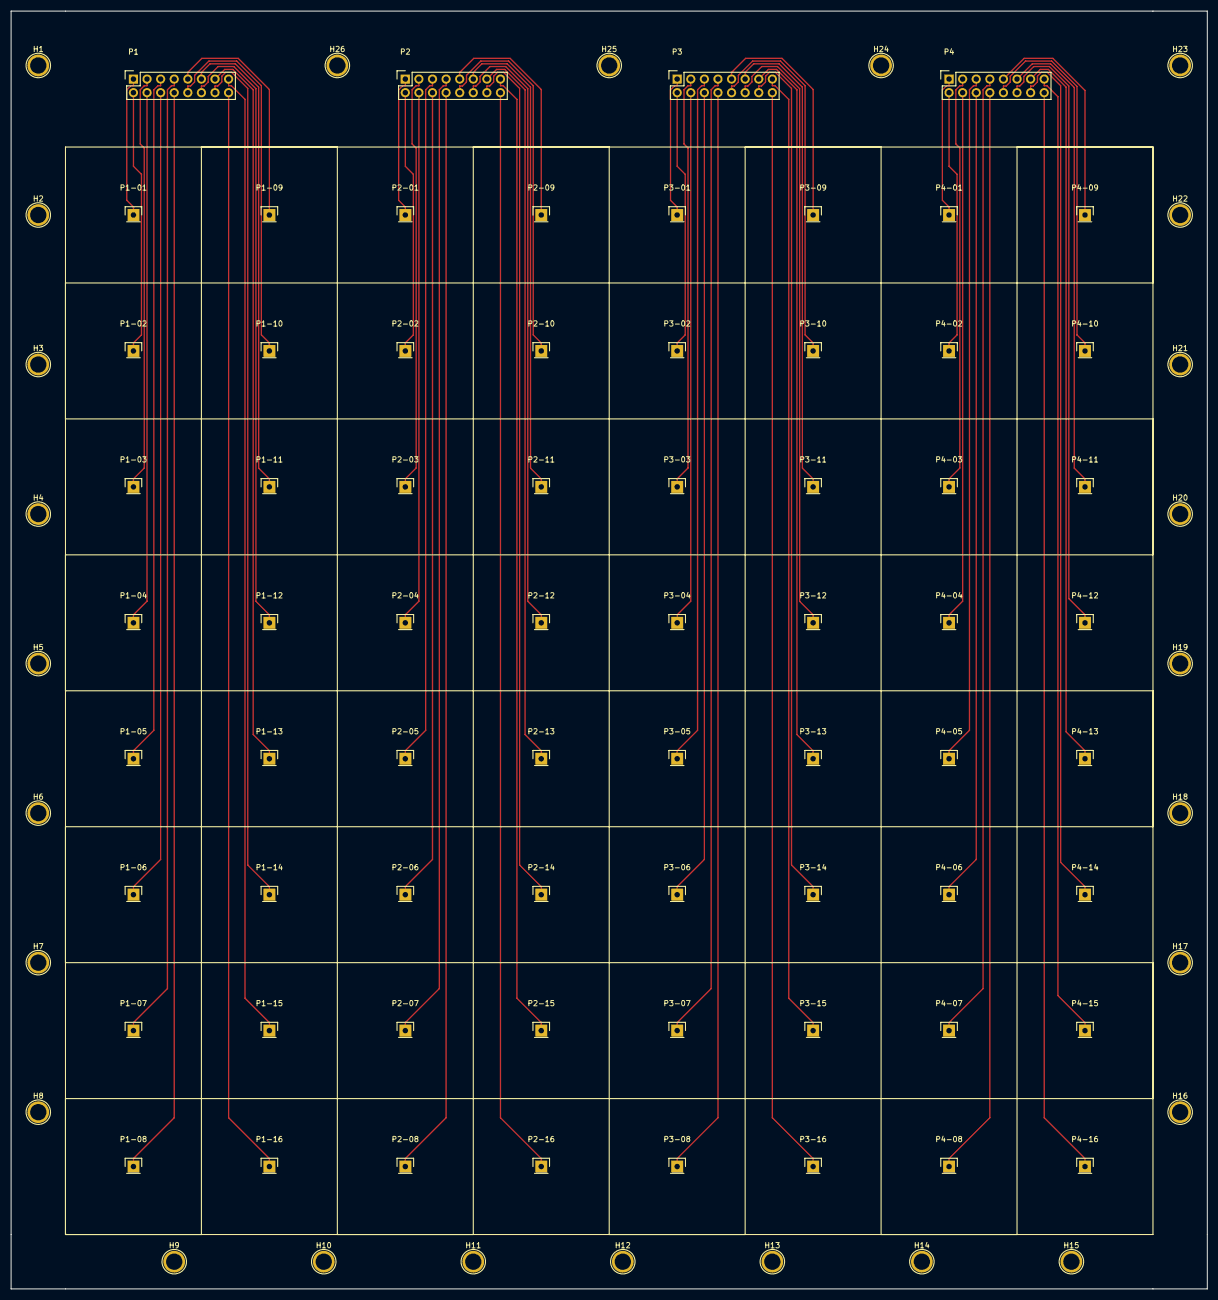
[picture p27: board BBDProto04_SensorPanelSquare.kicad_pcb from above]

Board: 2 copper layers, 223.5 x 238.8 mm, 94 parts (0 on the bottom side), 64 nets.

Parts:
H1, H2, H3, H4, H5, H6, H7, H8, H9, H10, H11, H12, H13, H14, H15, H16, H17, H18, H19, H20, H21, H22, H23, H24, H25, H26: CONN_01X01; Arduino_1pin
P1, P2, P3, P4: CONN_02X08; Socket_Strip_Straight_2x08
P1-01, P1-02, P1-03, P1-04, P1-05, P1-06, P1-07, P1-08, P1-09, P1-10, P1-11, P1-12, P1-13, P1-14, P1-15, P1-16, P2-01, P2-02, P2-03, P2-04, P2-05, P2-06, P2-07, P2-08, P2-09, P2-10, P2-11, P2-12, P2-13, P2-14, P2-15, P2-16, P3-01, P3-02, P3-03, P3-04, P3-05, P3-06, P3-07, P3-08, P3-09, P3-10, P3-11, P3-12, P3-13, P3-14, P3-15, P3-16, P4-01, P4-02, P4-03, P4-04, P4-05, P4-06, P4-07, P4-08, P4-09, P4-10, P4-11, P4-12, P4-13, P4-14, P4-15, P4-16: CONN_01X01; Pin_Header_Straight_1x01

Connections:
unnamed: P1.1, P1-01.1
unnamed: P1.2, P1-02.1
unnamed: P1.3, P1-03.1
unnamed: P1.4, P1-04.1
unnamed: P1.5, P1-05.1
unnamed: P1.6, P1-06.1
unnamed: P1.7, P1-07.1
unnamed: P1.8, P1-08.1
unnamed: P1.9, P1-09.1
unnamed: P1.10, P1-10.1
unnamed: P1.11, P1-11.1
unnamed: P1.12, P1-12.1
unnamed: P1.13, P1-13.1
unnamed: P1.14, P1-14.1
unnamed: P1.15, P1-15.1
unnamed: P1.16, P1-16.1
unnamed: P2.1, P2-01.1
unnamed: P2.2, P2-02.1
unnamed: P2.3, P2-03.1
unnamed: P2.4, P2-04.1
unnamed: P2.5, P2-05.1
unnamed: P2.6, P2-06.1
unnamed: P2.7, P2-07.1
unnamed: P2.8, P2-08.1
unnamed: P2.9, P2-09.1
unnamed: P2.10, P2-10.1
unnamed: P2.11, P2-11.1
unnamed: P2.12, P2-12.1
unnamed: P2.13, P2-13.1
unnamed: P2.14, P2-14.1
unnamed: P2.15, P2-15.1
unnamed: P2.16, P2-16.1
unnamed: P3.1, P3-01.1
unnamed: P3.2, P3-02.1
unnamed: P3.3, P3-03.1
unnamed: P3.4, P3-04.1
unnamed: P3.5, P3-05.1
unnamed: P3.6, P3-06.1
unnamed: P3.7, P3-07.1
unnamed: P3.8, P3-08.1
unnamed: P3.9, P3-09.1
unnamed: P3.10, P3-10.1
unnamed: P3.11, P3-11.1
unnamed: P3.12, P3-12.1
unnamed: P3.13, P3-13.1
unnamed: P3.14, P3-14.1
unnamed: P3.15, P3-15.1
unnamed: P3.16, P3-16.1
unnamed: P4.1, P4-01.1
unnamed: P4.2, P4-02.1
unnamed: P4.3, P4-03.1
unnamed: P4.4, P4-04.1
unnamed: P4.5, P4-05.1
unnamed: P4.6, P4-06.1
unnamed: P4.7, P4-07.1
unnamed: P4.8, P4-08.1
unnamed: P4.9, P4-09.1
unnamed: P4.10, P4-10.1
unnamed: P4.11, P4-11.1
unnamed: P4.12, P4-12.1
unnamed: P4.13, P4-13.1
unnamed: P4.14, P4-14.1
unnamed: P4.15, P4-15.1
unnamed: P4.16, P4-16.1

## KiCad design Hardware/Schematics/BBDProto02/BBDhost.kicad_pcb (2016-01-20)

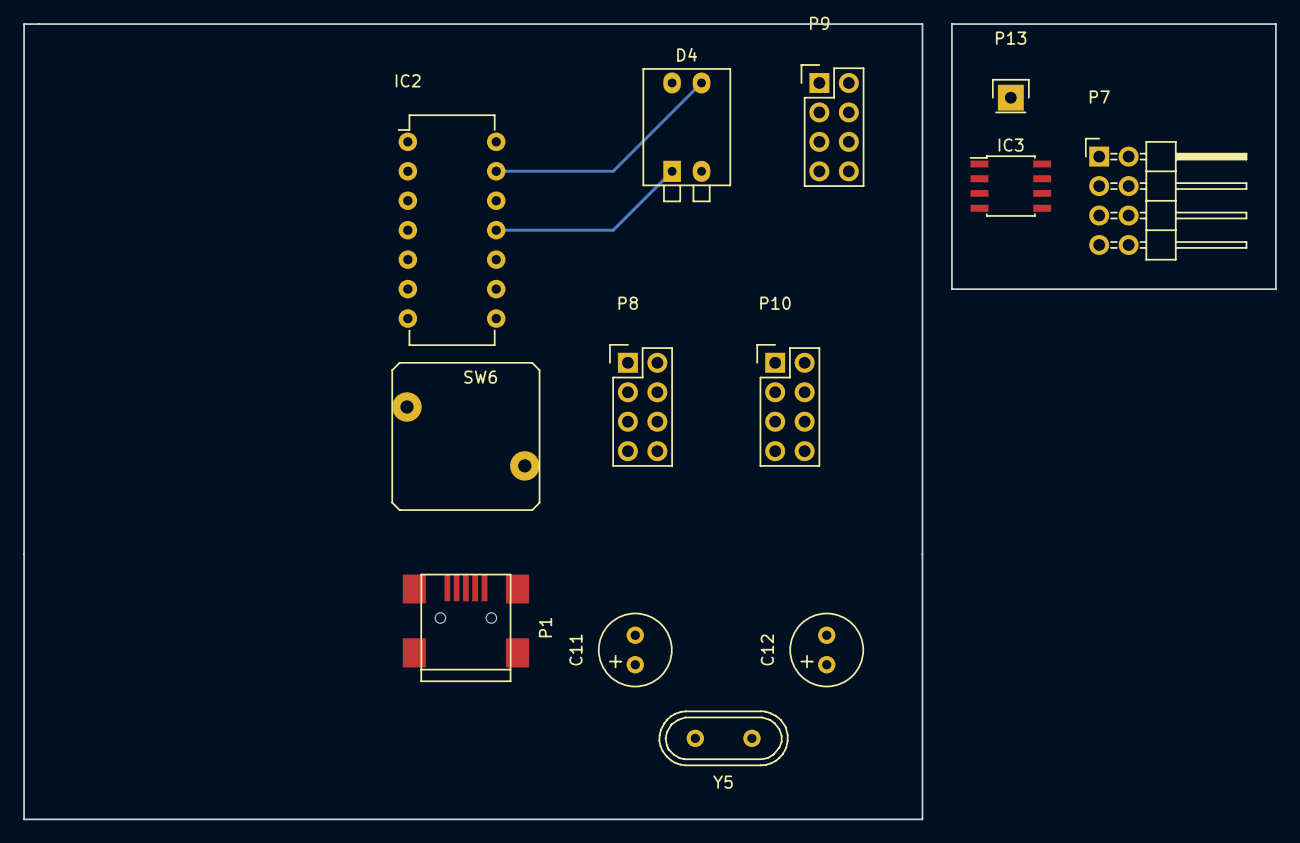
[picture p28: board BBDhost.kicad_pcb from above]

Board: 2 copper layers, 107.9 x 68.6 mm, 13 parts (0 on the bottom side), 24 nets.

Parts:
C11, C12: 12-22pF; Elko_vert_11.2x6.3mm_RM2.5_CopperClear
D4: LED_RCBG; SW_DIP_x2_Piano
IC2: ATTINY84A-P; DIP-14_W7.62mm
IC3: ATTINY25-S; SOIC-8_3.9x4.9mm_Pitch1.27mm
P1: USB_OTG; USB_Mini-B
P7: DIL8; Pin_Header_Angled_2x04
P8, P9, P10: DIL8; Pin_Header_Straight_2x04
P13: SENSOR; Pin_Header_Straight_1x01
SW6: CHANGE MODE; SW_PUSH
Y5: 20 Mhz; Crystal_HC49-U_Vertical

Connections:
unnamed: C11.1, IC2.3, P8.3, P9.3, P10.3, Y5.2
unnamed: C11.2, C12.2, IC2.14, P1.5, P8.4, P9.4, P10.4
unnamed: C12.1, IC2.2, P8.2, P9.2, P10.2, Y5.1
unnamed: D4.1, IC2.11
unnamed: D4.2, IC2.10
unnamed: D4.3, IC2.13
unnamed: D4.4, IC2.12
unnamed: IC2.1, P1.1, P8.8, P9.8, P10.8, SW6.1
unnamed: IC2.4, P1.3
unnamed: IC2.5, P1.2
unnamed: IC2.6, SW6.2
unnamed: IC2.7, P10.6
unnamed: IC2.8, P8.5
unnamed: IC2.9, P8.7, P9.7, P10.7
unnamed: IC3.1, P13.1
unnamed: IC3.2, P7.2
unnamed: IC3.3, P7.3
unnamed: IC3.4, P7.4
unnamed: IC3.5, P7.5
unnamed: IC3.6, P7.6
unnamed: IC3.7, P7.7
unnamed: IC3.8, P7.8
unnamed: P8.6, P9.5
unnamed: P9.6, P10.5

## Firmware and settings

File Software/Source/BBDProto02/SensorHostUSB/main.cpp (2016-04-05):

/*
 * BBD Proto #2 - EM Field Color Led and Antenna Tester with Power LEDs (2016-01-20 - 2016-03-12)
 *
 * Created: 2016-01-20
 * Author : Andras Fuchs (andras.fuchs@gmail.com)
 *
 * Controller:	Atmel ATmega168A
 * Pinout:		1 - Reset - button / Programmer yellow	28 - PC5 - Heartbeat
 *				2 - PD0 - Power level 8 LED				27 - PC4 - LED red
 *				3 - PD1 - Power level 7 LED				26 - PC3 - LED green
 *				4 - PD2 - Power level 6 LED				25 - NC
 *				5 - PD3 - Power level 5 LED				24 - NC
 *				6 - PD4 - Power level 4 LED				23 - ADC0 - antenna
 *				7 - Vcc									22 - GND
 *				8 - GND									21 - ARef - Battery 3.3V
 *				9 - NC									20 - AVcc = Vcc
 *				10 - NC									19 - SCK - Programmer green
 *				11 - PD5 - Power level 3 LED			18 - MISO - Programmer blue
 *				12 - PD6 - Power level 2 LED			17 - MOSI - Programmer orange
 *				13 - PD7 - Power level 1 LED			16 - PB2 - LED blue
 *				14 - PB0 - LED power					15 - NC
 * Description:
 *				The device detects the changes in the electro-magnetic field in the environment and changes the color of the LED accordingly.
 *				After startup it waits a few seconds (LED continuous red), and then it starts to sample the environment (LED blinking red).
 *				After the sampling finished it saves the average value of the field, and compares it to the current value:
 *				If the value is similar to the initial value the LED is green
 *				If the value is smaller (negative delta) than the initial value the LED is blue
 *				If the value is higher (positive delta) than the initial value the LED is red
 * Changelog:
 * 2016-03-12
 *  + added potmeter to ARef and changed the ADC's reference to ARef
 *  = changed the RGB LED pins
 *  - fixed the 55-second-freeze bug
 * 2016-03-11
 *  + 8 power leds on port Ds
 * 2016-03-10
 *	= changed delay values
 *  + adaptive long term average value
 *  + 2 selector buttons and antennas
 *  + reset button
 *
 * Notes:
 * Don't forget to set the fuses to use the external 20Mhz crystal as a clock (if you have one) by running
 * avrdude.exe -c usbasp -p atmega168 -U lfuse:w:0x6F:m
 *
*/

//#define F_CPU 8000000 // ATmega168's internal clock runs at 8.0 Mhz with CKDIV8 set (effective 1 Mhz), but changePrescaler speeds it up to 8 Mhz
#define F_CPU 20000000 // the external clock runs at 20.0 Mhz (with the 20Mhz extarnal clock the 1000ms delay takes 8 seconds, and with the internal 8 Mhz setting 20 seconds)

#include <avr/io.h>
#include <avr/sleep.h>
#include <avr/interrupt.h>
#include <avr/wdt.h>
#include <util/delay.h>

void changePrescaler(void);
double arrayAvg(double array[], int count);
void setLedPorts(int counter, int ledPower, int ledR, int ledG, int ledB);
int set_PORTB_bit(int position, int value);
int set_PORTC_bit(int position, int value);
void set_power_leds(int level);
void spectral_color(double &r,double &g,double &b,double l);
void adc_init(uint8_t ch);
uint16_t adc_read();
void adc_read_async();

const int avgSamplesCountShort = 5;
const int avgSamplesCountLong = 100;		// ~5 seconds


double adcValuesShort[avgSamplesCountShort];
double adcValuesLong[avgSamplesCountLong];

int ledPower = 50;	// 0 - 255
int ledR = 255;
int ledG = 0;
int ledB = 0;

int i = 0;
double adcValueAvgLong = 0.0;
double adcValueAvg = 0.0;
double adcValue = 0;


int main(void)
{
	changePrescaler();

	wdt_disable();
	wdt_enable(WDTO_8S);

	int counter = 0;
	
	// Set Port Bs as outputs (binary 1) or as inputs (binary 0)
	// PORTB bit 0 = physical pin #14 on the ATmega168A - LED Power
	// PORTB bit 1 = physical pin #16 on the ATmega168A - LED Blue
	// PORTB bit 3 = physical pin #17 on the ATmega168A - LED RED
	// PORTB bit 4 = physical pin #18 on the ATmega168A - LED GREEN
	DDRB = 0b00000101;

	// Set Port Cs as outputs (binary 1) or as inputs (binary 0)
	// PORTC bit 3 = physical pin #26 on the ATmega168 - LED Green
	// PORTC bit 4 = physical pin #27 on the ATmega168 - LED Red
	// PORTC bit 5 = physical pin #28 on the ATmega168 - Heartbeat LED
	DDRC = 0b00111000;

	// Set Port Ds as outputs (binary 1) or as inputs (binary 0)
	// PORTDs are the power level LEDs
	DDRD = 0b11111111;

	double r, g, b;
	double l = 400.0;

	setLedPorts(128, 255, 255, 0, 255);
	_delay_ms(5000);

	// Enable Noise Reduction Sleep Mode
	set_sleep_mode( SLEEP_MODE_ADC );
	sleep_enable();
		
	sei(); // enable global interrupts
		
	adc_init(0);

	// Set up a forever loop
    while (1) 
    {
		// version A: easy to read, but causes flicker
		//counter = (counter+1) % (120*256);

		// version B: looks more complicated but does not flicker
		counter = (counter+1);
		while (counter >= (120*256))
		{
			counter = counter - (120*256);

			PORTC ^= (1 << 5);
		}

		if ((counter%256) == 0)
		{
			//adc_read_async();
			sleep_cpu(); // this method automatically call the ADC interrupt method (so the adc_read_async() call is not neccessary)
		}
		
		if (i <= avgSamplesCountLong)
		{
			setLedPorts(counter, 0, 0, 0, 0);
		} else
		{
			setLedPorts(counter, ledPower, ledR, ledG, ledB);
		}

		wdt_reset();
	}
	
	return 1;
}


void changePrescaler(void) {
	cli();
	CLKPR = 1 << CLKPCE;		// Set the prescaler change enable bit to 1
	CLKPR = 0;					// Set the prescaler value to 1 and set the prescaler change enable bit to 0
	sei();
}




double arrayAvg(double array[], int count)
{
	double avg = 0.0;
	
	for (int j=0; j<count; j++)
	{
		avg = avg + array[j];
	}
	avg = avg / count;

	return avg;
}

void setLedPorts(int counter, int ledPower, int ledR, int ledG, int ledB)
{
	counter = counter % 256;
	
	if (counter <= ledPower)
	{
		set_PORTB_bit(0,1);
	}
	else
	{
		set_PORTB_bit(0,0);
	}


	if (counter >= ledR)
	{
		// turn RED led off
		set_PORTC_bit(4,1);
	}
	else
	{
		// turn RED led on
		set_PORTC_bit(4,0);
	}

	if (counter >= ledG)
	{
		set_PORTC_bit(3,1);
	}
	else
	{
		set_PORTC_bit(3,0);
	}

	if (counter >= ledB)
	{
		set_PORTB_bit(2,1);
	}
	else
	{
		set_PORTB_bit(2,0);
	}
}

int set_PORTB_bit(int position, int value)
{
	// Sets or clears the bit in position 'position'
	// either high or low (1 or 0) to match 'value'.
	// Leaves all other bits in PORTB unchanged.
	
	if (value == 0)
	{
		PORTB &= ~(1 << position);      // Set bit position low
	}
	else
	{
		PORTB |= (1 << position);       // Set high, leave others alone
	}

	return 1;
}

int set_PORTC_bit(int position, int value)
{
	// Sets or clears the bit in position 'position'
	// either high or low (1 or 0) to match 'value'.
	// Leaves all other bits in PORTC unchanged.
	
	if (value == 0)
	{
		PORTC &= ~(1 << position);      // Set bit position low
	}
	else
	{
		PORTC |= (1 << position);       // Set high, leave others alone
	}

	return 1;
}

void set_power_leds(int level)
{
	switch (level)
	{
		case 0: 
		PORTD = 0b00000000;
		break;

		case 1:
		PORTD = 0b10000000;
		break;

		case 2:
		PORTD = 0b11000000;
		break;

		case 3:
		PORTD = 0b11100000;
		break;

		case 4:
		PORTD = 0b11110000;
		break;

		case 5:
		PORTD = 0b11111000;
		break;

		case 6:
		PORTD = 0b11111100;
		break;

		case 7:
		PORTD = 0b11111110;
		break;

		case 8:
		PORTD = 0b11111111;
		break;
	}
}

void spectral_color(double &r,double &g,double &b,double l) // RGB <0,1> <- lambda l <400,700> [nm]
{
	double t;  r=0.0; g=0.0; b=0.0;
	if ((l>=400.0)&&(l<410.0)) { t=(l-400.0)/(410.0-400.0); r=    +(0.33*t)-(0.20*t*t); }
	else if ((l>=410.0)&&(l<475.0)) { t=(l-410.0)/(475.0-410.0); r=0.14         -(0.13*t*t); }
	else if ((l>=545.0)&&(l<595.0)) { t=(l-545.0)/(595.0-545.0); r=    +(1.98*t)-(     t*t); }
	else if ((l>=595.0)&&(l<650.0)) { t=(l-595.0)/(650.0-595.0); r=0.98+(0.06*t)-(0.40*t*t); }
	else if ((l>=650.0)&&(l<700.0)) { t=(l-650.0)/(700.0-650.0); r=0.65-(0.84*t)+(0.20*t*t); }
	if ((l>=415.0)&&(l<475.0)) { t=(l-415.0)/(475.0-415.0); g=             +(0.80*t*t); }
	else if ((l>=475.0)&&(l<590.0)) { t=(l-475.0)/(590.0-475.0); g=0.8 +(0.76*t)-(0.80*t*t); }
	else if ((l>=585.0)&&(l<639.0)) { t=(l-585.0)/(639.0-585.0); g=0.84-(0.84*t)           ; }
	if ((l>=400.0)&&(l<475.0)) { t=(l-400.0)/(475.0-400.0); b=    +(2.20*t)-(1.50*t*t); }
	else if ((l>=475.0)&&(l<560.0)) { t=(l-475.0)/(560.0-475.0); b=0.7 -(     t)+(0.30*t*t); }
}

void adc_init(uint8_t ch)
{
	// A: AREF, internal Vref turned off
	int ref = (0<<REFS1)|(0<<REFS0);
	
	// B: AVcc as Voltage Reference with external capacitor at AREF pin (#21).
	// int ref = (0<<REFS1)|(1<<REFS0);

	// C: Internal 1.1V Voltage Reference with external capacitor at AREF pin (#21).
	// int ref = (1<<REFS1)|(1<<REFS0);

	// select the corresponding channel 0~7
	// ANDing with ’7? will always keep the value
	// of ‘ch’ between 0 and 7
	ch &= 0b00000111;  // AND operation with 7
	ADMUX = (ref & 0xF8)|ch; // clears the bottom 3 bits before ORing
	
	// ADC Enable, do not start conversion, enable ADC interrupt, prescaler of 128
	// 20.0 Mhz/128 = 1'250kHz (96kSPS)
	ADCSRA = (1<<ADEN)|(0<<ADSC)|(1 << ADIE)|(1<<ADPS2)|(1<<ADPS1)|(1<<ADPS0);
}

uint16_t adc_read()
{
	// start single conversion
	// write '1' to ADSC
	ADCSRA |= (1<<ADSC);
	
	// wait for conversion to complete
	// ADSC becomes '0' again
	// till then, run loop continuously
	while(ADCSRA & (1<<ADSC));
	
	return (ADC);
}

void adc_read_async()
{
	// start single conversion
	// write '1' to ADSC
	ADCSRA |= (1<<ADSC);
}

ISR(ADC_vect)
{
	i = (i+1);
	if (i >= (120*256))
	{
		i = i - (120*256);
		if (i < avgSamplesCountLong)
		{
			i = avgSamplesCountLong;
		}
	}

	
	double adcValue = ((double)ADC) / 1024.0;
	
	// short average
	adcValuesShort[i % avgSamplesCountShort] = adcValue;
	double adcValueAvgShort = arrayAvg(adcValuesShort, avgSamplesCountShort);

	set_power_leds((int)(adcValueAvgShort*9));
	
	// long average
	if (i <= avgSamplesCountLong)
	{
		if (i%10 == 0)
		{
			setLedPorts(i, 255, 255, 0, 0);
			_delay_ms(200);
			setLedPorts(i, 0, 0, 0, 0);
			_delay_ms(200);
		}

		adcValuesLong[i % avgSamplesCountLong] = adcValue;
		
		if (i == avgSamplesCountLong)
		{
			adcValueAvgLong = arrayAvg(adcValuesLong, avgSamplesCountLong);
		}
	}
	
	
	adcValueAvg = (adcValueAvgShort - adcValueAvgLong) + 0.5;
	//adcValueAvg = adcValueAvg + 0.005;
	
	if (adcValueAvg < 0.0)
	{
		adcValueAvg = 0.0;
	}
	if (adcValueAvg > 1.0)
	{
		adcValueAvg = 1.0;
	}


	// method 1: color spectrum
	//l = (adcValueAvg * 285.0) + 400.0;
	
	//l = l+1.0;
	//if (l > 700.0)
	//{
	//l = l - 300.0;
	//}
	
	
	//spectral_color(r, g, b, l);
	//ledR = (int)(r*256);
	//ledG = (int)(g*256);
	//ledB = (int)(b*256);
	
	//ledPower = (int)(100 * adcValueAvg);
	
	// method 2: green - neutral, red power - positive, blue power - negative delta
	if ((adcValueAvg > 0.4) && (adcValueAvg < 0.6))
	{
		ledR = 0;
		ledG = 255;
		ledB = 0;
		
		if (adcValueAvg < 0.5)
		{
			ledPower = (int)(1000 * (adcValueAvg - 0.4)) + 10;
		} else
		{
			ledPower = (int)(1000 * (0.6 - adcValueAvg)) + 10;
		}
	} else if (adcValueAvg <= 0.4)
	{
		ledR = 0;
		ledG = 0;
		ledB = 255;
		
		ledPower = (int)(256 * (0.4 - adcValueAvg)) + 10;
	} else if (adcValueAvg >= 0.6)
	{
		ledR = 255;
		ledG = 0;
		ledB = 0;
		
		ledPower = (int)(256 * (adcValueAvg - 0.6)) + 10;
	}

	// move the long term average a little
	if (adcValueAvg < 0.5)
	{
		if (adcValueAvgLong > 0.1)
		{
			adcValueAvgLong = adcValueAvgLong - 0.00001;
		}
	} else {
		if (adcValueAvgLong < 0.9)
		{
			adcValueAvgLong = adcValueAvgLong + 0.00001;
		}
	}
}

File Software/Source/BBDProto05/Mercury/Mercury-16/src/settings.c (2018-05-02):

/*
 * settings.c
 *
 * Created: 2017-03-07 16:16:18
 *  Author: Andras Fuchs
 */ 

#include "settings.h"
#include <adc.h>
#include <udc.h>
#include <udd.h>


void settings_load_defaults()
{
	nvm_wait_until_ready();
	
	struct nvm_device_id device_id;
	nvm_read_device_id(&device_id);

	struct nvm_device_serial device_serial;
	nvm_read_device_serial(&device_serial);

	// (!!) the setting should be set manually

	settings.choice = 0xF004;
	settings.length = sizeof(settings) - 4;
	settings.firmware_version = 0x0002;
	settings.test_mode = 0; // 0 - test mode off, 1 - simple test mode, send ticks, 2 - send
	settings.device_status = 1;
	//settings.device_type = 1;	// (!!) 0 - unknown, 1 - cell , 2 - organizer
	settings.device_index = 0x36; // (!!) master: 0x36, slaves: 0x11 0x22 - change this for auto-configuration
	settings.device_id = (device_id.devid0 * 65536) + (device_id.devid1 * 256) + device_id.devid2;
	settings.device_serial = (device_serial.lotnum0 * 16777216) + (device_serial.wafnum * 65536) + (device_serial.coordx0 * 256) + device_serial.coordy0;
	settings.clk_sys = sysclk_get_per_hz();
	settings.clk_adc = 93750UL;
	//settings.adc_enabled = false;  // (!!) ADC should be enabled for cells and disabled for the organizer
	settings.adca_enabled = adc_is_enabled(&ADCA);
	settings.adcb_enabled = adc_is_enabled(&ADCB);
	settings.adc_bits = 12;
	settings.adc_ref = (uint8_t)ADC_REFSEL_INT1V_gc;
	//settings.adc_ref = (uint8_t)ADC_REFSEL_INTVCC_gc;
	settings.adc_gain = 8;
	settings.sample_rate = 4000;  // sample rate should be fixed to 1kSPS for now
	settings.sample_rate_compensation = 0;
	settings.channel_count = 8;
	settings.dac_enabled = false;
	//settings.usb_enabled = false;  // (!!) USB should be enabled for the organizer and disabled for the cells
	settings.usb_address = udd_getaddress();
	settings.usb_speed = (udd_is_high_speed() ? 480000000UL : 12000000UL);
	settings.usart_enabled = false;  // USART should be enabled for both the cells and the organizer
	//settings.usart_mode = 3; // (!!) 1 - async, 2 - sync master (organizer), 3 - sync slave (cell)
	settings.usart_speed = 1200; // the minumum speed should be [adc_value_bits] * [sample rate] * [channel_count] * [cell count] * 1.2 (for the overhead)
	
	settings.goertzel_enabled = false;
	settings.goertzel_frequency_01 = 7.83f;
	settings.goertzel_frequency_02 = 23.88f;
	settings.goertzel_frequency_03 = 50.00f;
	
	settings.adc_value_bits = 16;
	settings.adc_value_count_per_packet = settings.sample_rate / 60 < MAX_ADC_VALUES_PER_PACKET ?  settings.sample_rate / 60 : MAX_ADC_VALUES_PER_PACKET; // we must guarantee the 60 fps refresh rate

	//settings.adc_value_packet_to_usb = false;  // (!!)
	//settings.adc_value_packet_to_usart = true;  // (!!)
	//settings.goertzel_packet_to_usb = false;  // (!!)
	//settings.goertzel_packet_to_usart = false;  // (!!)

	// it just makes the testing easier, comment it in production
	if (settings.device_index == 0x36)
	{
		settings.device_type = 2;						// 0 - unknown, 1 - cell , 2 - organizer
		settings.adc_enabled = false;					// ADC should be enabled for cells and disabled for the organizer
		settings.usb_enabled = true;					// USB should be enabled for the organizer and disabled for the cells
		settings.usart_mode = 2;						// 1 - async, 2 - sync master (organizer), 3 - sync slave (cell)
		settings.adc_value_packet_to_usb = true;
		settings.adc_value_packet_to_usart = false;
		settings.goertzel_packet_to_usb = false;
		settings.goertzel_packet_to_usart = false;
	}

	if ((settings.device_index == 0x11) || (settings.device_index == 0x22))
	{
		settings.device_type = 1;						// (!!) 0 - unknown, 1 - cell , 2 - organizer
		settings.adc_enabled = true;					// (!!) ADC should be enabled for cells and disabled for the organizer
		settings.usb_enabled = false;					// (!!) USB should be enabled for the organizer and disabled for the cells
		settings.usart_mode = 3;						// (!!) 1 - async, 2 - sync master (organizer), 3 - sync slave (cell)
		settings.adc_value_packet_to_usb = false;		// (!!)
		settings.adc_value_packet_to_usart = true;		// (!!)
		settings.goertzel_packet_to_usb = false;
		settings.goertzel_packet_to_usart = true;
	}
	
	settings.adc_enabled = true;
}
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

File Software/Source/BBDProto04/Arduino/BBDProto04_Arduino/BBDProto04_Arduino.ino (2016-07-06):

/*
  Bio Balance Detector - Proto #3 - Arduino

 Created: 2016-04-01
 Updated: 2016-04-26
 by Andras Fuchs (andras.fuchs@gmail.com)

 Changelog:
 * 2016-04-28
	+ moved to Visual Studio
	= changed the ATTiny SS port to pin #8
 * 2016-04-26
	- removed unused parts
	= simplified the ADC value sending code
*/


// inslude the SPI library:
#include <SPI.h>

#include "TimerOne\TimerOne.h"

// set pin #9 (ATmega pin #15) as the slave select for the ADC
const int pinSelectADC = 2;

// set pin #10 (ATmega pin #16) as the slave select for the DAC
const int pinSelectDAC = 7;

const int pinRGBLEDRed = 5;
const int pinRGBLEDGreen = 10;
const int pinRGBLEDBlue = 9;
const int pinRGBLEDPower = 6;

const int pinSelectChannelS0 = A0;
const int pinSelectChannelS1 = A1;
const int pinSelectChannelS2 = A2;
const int pinSelectChannelS3 = A3;
const int pinSelectChannelS4 = A4;
const int pinSelectChannelS5 = A5;
const int pinSelectChannelS6 = 3;
const int pinSelectChannelS7 = 4;


const long UARTBaudRate = 115200*16;

// We need to declare the data exchange
// variable to be volatile - the value is
// read from memory.
unsigned short values[256];
volatile unsigned short channel = 0;
volatile unsigned short j = 0;
char previousChannelBits[8];

// Install the interrupt routine.
ISR(INT0_vect) {
	Serial.println("interrupt 0");
}

void setup() {

	// set the RGB-LED's pins as an output:
	pinMode(pinRGBLEDRed, OUTPUT);
	pinMode(pinRGBLEDGreen, OUTPUT);
	pinMode(pinRGBLEDBlue, OUTPUT);
	pinMode(pinRGBLEDPower, OUTPUT);

	// channel select pins
	pinMode(pinSelectChannelS0, OUTPUT);
	pinMode(pinSelectChannelS1, OUTPUT);
	pinMode(pinSelectChannelS2, OUTPUT);
	pinMode(pinSelectChannelS3, OUTPUT);
	pinMode(pinSelectChannelS4, OUTPUT);
	pinMode(pinSelectChannelS5, OUTPUT);
	pinMode(pinSelectChannelS6, OUTPUT);
	pinMode(pinSelectChannelS7, OUTPUT);

	// SPI slave selectors
	pinMode(pinSelectADC, OUTPUT);
	pinMode(pinSelectDAC, OUTPUT);

	// initialize SPI:
	SPI.begin();

	// set the baud rate to 2400, 4800, 9600, 19200, 38400, 57600 or 115200
	Serial.begin(UARTBaudRate);
	bitSet(UCSR0A, U2X0);     // change the UART speed divider from 16 to 8

	// set the sensitivity to the default (valid range is 0-4096)
	setDAC(2048);

	setChannel(0);
	for (int i = 0; i < 256; i++)
	{
		values[i] = 0;
	}


	// set up the timer to count every 0.0001 seconds
	//Timer1.initialize(100);
	//Timer1.attachInterrupt(timerInterrupt);
}

volatile unsigned long timerCounter = 0; // use volatile for shared variables

void timerInterrupt(void)
{
	timerCounter++;
}

void loop() {
	//sendBenchmarkFlag('a');
	j++;
	if (j > 512) j = 0;
	setLED(j, j + 128, j + 256, 50);

	for (int i = 0; i < 256; i++)
	{
		//setChannel(((i%16) * 16) + (i/16));
		setChannel(i);
		readADC(true);
		//delay(1);
	}
	delay(60);
	//sendBenchmarkFlag('f');
	sendAllValues();
	//sendBenchmarkFlag('g');
	//delay(5);
}

void setLED(int red, int green, int blue, int power)
{
	if (red >= 256) red = 511 - (red % 512);
	if (green >= 256) green = 511 - (green % 512);
	if (blue >= 256) blue = 511 - (blue % 512);

	analogWrite(pinRGBLEDRed, red);
	analogWrite(pinRGBLEDGreen, green);
	analogWrite(pinRGBLEDBlue, blue);
	analogWrite(pinRGBLEDPower, 255-power);
	//analogWrite(pinRGBLEDPower, 0);
}

void setChannel(unsigned int ch)
{
	char channelBits[8];

	channelBits[0] = (ch & (1 << 0)) >> 0;
	channelBits[1] = (ch & (1 << 1)) >> 1;
	channelBits[2] = (ch & (1 << 2)) >> 2;
	channelBits[3] = (ch & (1 << 3)) >> 3;
	channelBits[4] = (ch & (1 << 4)) >> 4;
	channelBits[5] = (ch & (1 << 5)) >> 5;
	channelBits[6] = (ch & (1 << 6)) >> 6;
	channelBits[7] = (ch & (1 << 7)) >> 7;

	if (channelBits[0] != previousChannelBits[0])
	{
		digitalWrite(pinSelectChannelS0, channelBits[0]);
		previousChannelBits[0] = channelBits[0];
	}

	if (channelBits[1] != previousChannelBits[1])
	{
		digitalWrite(pinSelectChannelS1, channelBits[1]);
		previousChannelBits[1] = channelBits[1];
	}

	if (channelBits[2] != previousChannelBits[2])
	{
		digitalWrite(pinSelectChannelS2, channelBits[2]);
		previousChannelBits[2] = channelBits[2];
	}

	if (channelBits[3] != previousChannelBits[3])
	{
		digitalWrite(pinSelectChannelS3, channelBits[3]);
		previousChannelBits[3] = channelBits[3];
	}

	if (channelBits[4] != previousChannelBits[4])
	{
		digitalWrite(pinSelectChannelS4, channelBits[4]);
		previousChannelBits[4] = channelBits[4];
	}

	if (channelBits[5] != previousChannelBits[5])
	{
		digitalWrite(pinSelectChannelS5, channelBits[5]);
		previousChannelBits[5] = channelBits[5];
	}

	if (channelBits[6] != previousChannelBits[6])
	{
		digitalWrite(pinSelectChannelS6, channelBits[6]);
		previousChannelBits[6] = channelBits[6];
	}

	if (channelBits[7] != previousChannelBits[7])
	{
		digitalWrite(pinSelectChannelS7, channelBits[7]);
		previousChannelBits[7] = channelBits[7];
	}

	channel = ch;
}

unsigned int readADC(bool storeValue)
{
	SPI.beginTransaction(SPISettings(16000000, MSBFIRST, SPI_MODE1));

	// take the SS pin low to select the chip:
	digitalWrite(pinSelectADC, LOW);

	byte rx1 = SPI.transfer(0b10000000);
	byte rx2 = SPI.transfer(0b00000000);

	// take the SS pin high to de-select the chip:
	digitalWrite(pinSelectADC, HIGH);

	SPI.endTransaction();

	int value = (rx1 * 256) + rx2;

	if (storeValue)
	{
		values[channel] = value;
	}

	return value;
}

void sendSingleValue(int channel, unsigned int adcValue)
{
	if (adcValue > 0)
	{
		char buffer[6+2*8];
		snprintf(buffer, sizeof buffer, "<|ch|%u,%u|>", channel, adcValue);
		Serial.print(buffer);
	}
}

void sendAllValues()
{
	uint8_t buffer[5+256*2+2];

	for (int i = 0; i < 256; i++)
	{
		buffer[5 + i * 2 + 0] = (uint8_t)(values[i] >> 8);
		buffer[5 + i * 2 + 1] = (uint8_t)(values[i] & 0xFF);
	}

	//Serial.print("<|ll|");
	buffer[0] = 60;
	buffer[1] = 124;
	buffer[2] = 108;
	buffer[3] = 108;
	buffer[4] = 124;
	//Serial.print("|>");
	buffer[5 + 256 * 2 + 0] = 124;
	buffer[5 + 256 * 2 + 1] = 62;

	Serial.write(buffer, sizeof(buffer));	
}

void sendBenchmarkFlag(char flag)
{
	char buffer[15];

	if (flag == 'a') timerCounter = 0;

	snprintf(buffer, sizeof buffer, "<|bm|%c,%lu|>", flag, timerCounter);
	Serial.print(buffer);
}
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

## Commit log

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2016-03-11 Prototype #2 new features
    Added the power leds, antenna selector buttons and reset
    [main.cpp]
2016-03-12 55-second-bug fix
    55-second-bug fix
    [main.cpp]
2016-03-23 Added chips to library and schematics
    Added chips to library and schematics
    [BBDProto03.kicad_pcb, BBDProto03.sch, BBDProto03_.sch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]
2016-03-24 Updated some components and descriptions
    Updated some components and descriptions
    [BBDProto03.sch]
2016-04-05 Library updates, photos, FreeRoute
    Library updates, photos, FreeRoute
    [BBDProto03.dsn, BBDProto03.kicad_pcb, BBDProto03.sch]
2016-04-06 Proto #3 rev B
    Proto #3 rev B
    [BBDProto03.sch]
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2016-04-11 Arduino firmware
    Arduino firmware to manage the SPI bus for the DAC and the ADC.
    [BBDProto03.sch]
2016-04-14 Refined schemantics, ATtiny861 first version, AVRdude update
    Refined schemantics, ATtiny861 first version, AVRdude update
    [BBDProto03.kicad_pcb, BBDProto03.sch]
2016-04-15 Added footprint associations to new components
    Added footprint associations to new components: I/O transistor, reset
    switch
    [BBDProto03.kicad_pcb, BBDProto03.sch]
2016-04-15 AutoRouter rerun, new photos and fabrication files
    AutoRouter rerun, new photos and fabrication files
    [BBDProto03.dsn, BBDProto03.kicad_pcb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]
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2016-05-18 Proto #4 - Rev A
    Proto #4 - Rev A
    [BBDProto04.dsn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]
2016-05-22 MultiplexerServer: 64-channel WAV generator
    MultiplexerServer: 64-channel WAV generator
    [BBDProto04.sch]
2016-06-03 AVR mkii, new photos, avrdude and usbasp PDI hack
    AVR mkii, new photos, avrdude and usbasp PDI hack
    [USBasp.sch]
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2016-06-19 Wave file generator fix
    Wave file generator fix
    [BBDProto04_Arduino.ino]
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2017-02-15 Sample projects and their documentation for XMEGA-A3U
    Sample projects and their documentation for XMEGA-A3U
    [SineWave.xls]
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2017-02-23 Fixed the USB descriptor bug
    The USB descriptor of Mercury was not retrieved by the driver. The
    problem was that I listed the devices with LibUsbDotNet, but tried to
    open the interface using WinUSBNet.
    [main.c]
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2017-03-13 Fixed a few ADC sampling and signal processig bugs
    [adc_oversampling.c, conf_dac.h, main.c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]
2017-03-13 Fixed the buffer append bug and the spektrum visual output jitter.
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2017-08-09 Hardware design files for Proto #06: Mercury-64
    Hardware design files for Proto #06: Mercury-64
    [Mercury64.kicad_pcb, Mercury64.sch]
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2017-08-13 Fixed an issue with ASF
    Fixed an issue with ASF
    [adc_oversampling.c, main.c, settings.c]
2017-08-13 Started the new schematic for Mercury-64
    Started the new schematic for Mercury-64
    [Mercury64.sch]
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2017-09-07 Fixed some LCD texts and added some comments to the code
    Fixed some LCD texts and added some comments to the code
    [main.c, settings.c]
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2017-09-15 Slowed the ADC clock and fixed it's display
    Slowed the ADC clock and fixed it's display
    [bbd_lcd.c, main.c, settings.c]
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2017-09-23 BBD Proto#5 Flat Panel Detector schemantics and PCB
    BBD Proto#5 Flat Panel Detector schemantics and PCB
    [BBDProto05_FlatPanelDetector.dsn, BBDProto05_FlatPanelDetector.kicad_pcb, BBDProto05_FlatPanelDetector.sch]
2017-09-25 FlatPanelDetector and its generator
    FlatPanelDetector and its generator
    [BBDProto05_FlatPanelDetector.kicad_pcb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]
2017-10-04 Fabrication files for the new flat panel detector
    Fabrication files for the new flat panel detector
    [BBDProto05_FlatPanelDetector.kicad_pcb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]
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2017-12-01 Fixed a few minor problems on the PCB
    Fixed a few minor problems on the PCB
    [BBDProto05_FlatPanelDetector.kicad_pcb]
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2018-03-17 Added the fractal triangle antenna and made the drill holes bigger
    Added the fractal triangle antenna and made the drill holes bigger
    [BBDProto05_FlatPanelDetector-B.Cu.gbr, BBDProto05_FlatPanelDetector-B.SilkS.gbr, BBDProto05_FlatPanelDetector-F.Cu.gbr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]
2018-03-20 Empty Venus-256 hardware design files
    Empty Venus-256 hardware design files
    [Mercury64.kicad_pcb, Mercury64.sch, Venus256.kicad_pcb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]
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2018-04-06 Created a new KiCad 5 project file for Venus-256
    Created a new KiCad 5 project file for Venus-256
    [Venus-256.kicad_pcb, Venus-256.sch, Venus256.kicad_pcb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]
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2018-04-26 Added the older ATSAME70Q21 datasheet
    Added the older ATSAME70Q21 datasheet which has the correct 144-LQPF pin numbers
2018-04-26 Added the hierarchical sheets
    Added the hierarchical sheets for Cell Master and Slave
    [CellMaster.sch, CellSlave.sch, RaspberryPiGPIOHeader.sch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]
2018-04-27 Added datasheets and schematics of AD7616 EVAL board
    Added datasheets and schematics of AD7616 EVAL board
    [Analog_Devices_EVAL-AD7616SDZ-Schematics.ods]
2018-04-27 Updated the Cell Master and Slave schematics
    Updated the Cell Master and Slave schematics
    [ARMJTAGHeader.sch, CellMaster.sch, CellSlave.sch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]
2018-04-27 Added Cell Slave capacitors
    Added Cell Slave capacitors
    [CellSlave.sch, Venus-256.sch]
2018-04-27 Completed the Cell Master and Slave schematics
    Completed the Cell Master and Slave schematics
    [ARMJTAGHeader.sch, CellMaster.sch, CellSlave.sch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]
2018-04-27 Added ADG715 switch array
    Added ADG715 switch array
    [Venus-256.sch]
2018-04-27 Started to rearrange the Venus-256 PCB
    Started to rearrange the Venus-256 PCB
    [ARMJTAGHeader.sch, CellMaster.sch, CellSlave.sch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]
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2018-05-02 Added a 5th cell-slave
    Added a 5th cell-slave
    [ARMJTAGHeader.sch, CellMaster.sch, CellSlave.sch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]
2018-05-11 Updated the AD7616 and its Cell Slave schematics
    Updated the AD7616 and its Cell Slave schematics
    [ARMJTAGHeader.sch, CellMaster.sch, CellSlave.sch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]
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2018-05-25 Fixed many rules check errors and changed the footprint of test points
    [CellMaster.sch, CellSlave.sch, RaspberryPiGPIOHeader.sch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]
2018-05-27 Replaced the ADG715 with TPS22993
    [CellMaster.sch, Venus-256.kicad_pcb, Venus-256.sch]
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2018-05-28 Updated the AD7616 symbol to match the library
    Updated the AD7616 symbol to match the library
    [CellSlave.sch, Venus-256.kicad_pcb, Venus-256.sch]
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2018-05-28 Switched from 2 layer to 4 layer design
    [Venus-256.kicad_pcb]
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2018-05-28 Fixed the triangle nets
    [Venus-256.kicad_pcb]
2018-05-28 Added the burried vias to the first ADC
    [Venus-256.kicad_pcb]
2018-05-28 Switched around the ADC channels to make the PCB simpler
    [CellMaster.sch, CellSlave.sch, Venus-256.kicad_pcb]
2018-05-28 Moved the ADC to fit the 0.65 grid (its own pitch)
    [Venus-256.kicad_pcb]
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2018-12-05 Fixed the nets connected to 16 pads
    [Venus-256.kicad_pcb]
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2018-12-06 Expanded the sensors by adding an extra 0.65mm gap between them and rearraged the MCUs a little
    [Venus-256.kicad_pcb]
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2018-12-06 Revert "Connected the sensors manually"
    This reverts commit 920ffef15f235d024d89dcae21abf078b3e216eb.
    [Venus-256.kicad_pcb]
2018-12-06 Fixed the antenna net mess-up
    [Venus-256.kicad_pcb]
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2018-12-07 Extended the board to have space for the ADCs on the right
    [Venus-256.kicad_pcb]
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2020-01-31 Moved the mounting points and added a few AGND vias to the board
    [Mars-64.kicad_pcb]
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2020-02-01 Finished up the missing routes, ready to manufacturing
    [Mars-64.kicad_pcb]
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2020-02-13 Replaced the older footprints of U101 and U201
    [Mars-64.kicad_pcb]
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2020-02-28 Added two capacitors to stabilize VCC
    [Mars-64.kicad_pcb, Mars-64.sch]
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2020-05-10 Fixed a few bugs on the PCB and changed the revision from D to E
    [Mars-64.kicad_pcb, Mars-64.sch]
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2020-05-10 Fixed the footprints of PmodF and PmodM, and removed the routed tracks
    [Mars-64.kicad_pcb, Mars-64.sch]
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2021-01-16 Fix the sample rate bug
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

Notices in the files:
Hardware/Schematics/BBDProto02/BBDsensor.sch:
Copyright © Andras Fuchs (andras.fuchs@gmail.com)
